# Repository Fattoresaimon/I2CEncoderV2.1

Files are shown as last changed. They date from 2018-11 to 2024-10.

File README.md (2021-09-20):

# I2C Encoder V2.1
--------------------------------------------------------------------------------
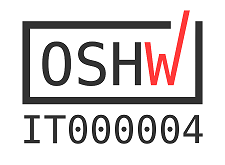
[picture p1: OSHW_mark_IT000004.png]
OSHW


## This repository is for the HW version 2.1!
In the bottom edge it's written the board version. 
If it's written V2.1 you are in the right palce, if it's writte V2.0 you need to go [here](https://github.com/Fattoresaimon/I2CEncoderV2.1/releases/tag/V2.0.0).

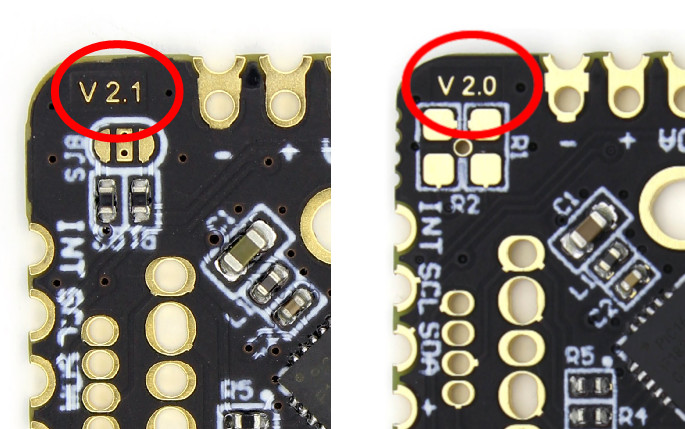
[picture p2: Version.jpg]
HW version V2.1


## Introduction
The I2C Encoder V2.1 is a small board where you can use a classical mechanical encoder, or an illuminated RGB encoder on I2C bus.
The device has also 3 configurable GPIOs with the same footprint of RGB LED. It's possible to connect up to 127 boards in cascade and read all of them with the same I2C bus.
The I2C Encoder V2.1 has a series of 8 bit registers where it is possible to configure  the parameters and four 32 bit of registers. These 32 bit registers store counter value, value of increment steps, maximum and minimum thresholds.
Every time when encoder rotates at least one step, the counter value increases or decreases according to the rotation direction by the value of the increment steps register.
When the counter value is outside of the limit set by the thresholds registers, the counter value can be wrapped or can stuck on the threshold value reached.
I2C Encoder V2.1 also has an open-drain interrupt pin. It is set to logic low every time an interrupt occurs, the source of interrupt can be customized.

## Where you can get this board?
This project is available on our [DuPPa store](https://www.duppa.net/duppa-shop/) and also in our [Tindie store!](https://www.tindie.com/products/Saimon/i2c-encoder-v2/)

## Repository Structure
* [Arduino Library:](https://github.com/Fattoresaimon/ArduinoDuPPaLib) Repository where you can find the Arduino IDE library for the DuPPa boards
* [Raspberry Library:](/Python%20Raspberry%20Library) Ready to use library in Python for the Raspberry board with example.
* [Firmware:](/Firmware) Project folder of Microchip MPLAB X contain the code running inside of the PIC16F18345
* [Hardware:](/Hardware) Folder containing the gerber file, schematic and BOM. 
* [Datasheet EncoderI2C V2.1:](EncoderI2CV2.1_v1.2.pdf) Datasheet of the board with the description of the registers and some useful information.

**The HW project is also available on [CircuitMaker](https://workspace.circuitmaker.com/Projects/Details/Simone--Caron/I2C-Encoder-V2)**

## Third-party libraries
* [CircuitPython](https://github.com/bwshockley/CircuitPython-i2cEncoderLibV21) thanks to Benjamin Shockley
* [C# / nanoFramework]( https://github.com/andylyonette/I2cEncoderV2)  thanks to  [Andy Lyonette](https://www.hackster.io/andy-lyonette)
* [PSOC](https://github.com/rudydevolder/DUPPA-i2cEncoder-for-PSOC) thanks to Rudy De Volder

## Third-party tutorial
[Tutorial #226 – Pyboard – Illuminated encoder](https://tutorial.hyperpanel.com/tutorials/tutorial-226-pyboard-illuminated-encoder/) thanks to Carolino Santonastasi

## Licensing

Hardware and firmware are licensed under GPL-3 license.

Documentation is licensed under a Creative Commons BY-SA 4.0 international license.

**If you want to donate for my work, i would really appreciate it. You can donate here with this link. Thank you!**



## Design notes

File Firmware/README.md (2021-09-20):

# I2C Encoder V2.1 Source code

Here you can find the last firmware version of the project.
You can find the MPLAB project with the source file, and you can find directly the binary file ready to be uploaded to the microcontroller.

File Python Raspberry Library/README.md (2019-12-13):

# I2C Encoder V2.1 Python library 
--------------------------------------------------------------------------------

## Introduction

Here you can find the library and some examples for Raspberry Pi.
For more details of the functionality of the board please read the [Datasheet](../EncoderI2CV2.1_v1.0.pdf) 

## Installation

The installation is very simple:

* Download the file [**i2cEncoderLibV2.py** ](Source/i2cEncoderLibV2.py) 
* Put the file in the folder where you have the source files.
* Import the library in your source files
``` python
import i2cEncoderLibV2
```

## Initialization

The library makes available the class **i2cEncoderLibV2**
For initialize the library you have to declare an instance of the class **i2cEncoderLibV2** for each encoders.
In the instance you have to declare the I2C address of the board
For example:

``` python
import smbus2
import i2cEncoderLibV2

bus = smbus2.SMBus(1)
encoder = i2cEncoderLibV2.i2cEncoderLibV2(bus, 0x61)
```
In this example the I2C address is 0x61: jumpers A0, A5 and A6 are soldered

## Callback Configuration

This library support the callback functionality.
There is the possibility to link a function to a specific interrupt of the I2C Encoder V2, in this way the function is automatically called when the I2C Encoder V2 generates an interrupts.

A callback function must be declared as the following:

```python
def NAME_OF_THE_FUNCTION():
```
There are 16 possible events:

| Event | Description |
|:---:|:---|
| onButtonRelease | Encoder push button is released |
| onButtonPush | Encoder push button is pushed |
| onButtonDoublePush | Encoder push button is double pushed |
| onIncrement | The counter value is incremented |
| onDecrement | The counter value is decremented |
| onChange | The counter value is incremented or decremented |
| onMax | The counter value reach the maximum threshold |
| onMin | The counter value reach the minimum threshold |
| onMinMax | The counter value reach the maximum or minimum threshold |
| onGP1Rise | GP1 configured as input, rising edge |
| onGP1Fall | GP1 configured as input, falling edge |
| onGP2Rise | GP2 configured as input, rising edge  |
| onGP2Fall | GP2 configured as input, falling edge  |
| onGP3Rise | GP3 configured as input, rising edge  |
| onGP3Fall | GP3 configured as input, falling edge  |
| onFadeProcess | Fade process terminated |

#### Examples:

```python
encoder = i2cEncoderLibV2.i2cEncoderLibV2(bus, 0x61)

...

 # Simple callback that ist's called when the encoder is rotated and blink the green led #
def EncoderChange():
    encoder.writeLEDG(100)
    print ('Changed: %d' % (encoder.readCounter32()))
    encoder.writeLEDG(0)

...

encoder.onChange = EncoderChange # Attach the event to the callback function#

}

```

If you need to remove the link with a callback, you just need to define:
```python
encoder.onChange = None
```

## Methods

### Initialization
#### begin(conf)
This is used for initialize the encoder by writing the configuration register.
The parameters can be concatenate in OR mode.
Possible parameters are the following:

| Parameter | Description |
| --- | --- |
| INT_DATA | The Threshold, counter step and counter value are used with integer numbers |
| FLOAT_DATA | The Threshold, counter step and counter value are used with floating numbers |
| | |
| WRAP_ENABLE | Wrap enable. When the counter value reaches the CMAX+1, restart to the CMIN and vice versa |
| WRAP_DISABLE | Wrap disable. When the counter value reaches the CMAX or CMIN, the counter stops to increasing or decreasing |
| | |
| DIRE_LEFT | Rotate left side to increase the value counter |
| DIRE_RIGHT | Rotate right side to increase the value counter |
| | |
| IPUP_DISABLE | Disable the internal pull-up on the INT pin |
| IPUP_ENABLE | Enable the internal pull-up on the INT pin |
| | |
| RMOD_X2 | Encoder in X2 mode |
| RMOD_X1 | Encoder in X1 mode |
| | |
| RGB_ENCODER | RGB illuminated encoder is soldered |
| STD_ENCODER | Standard rotary encoder is soldered |
| | |
| EEPROM_BANK1 | Select the first EEPROM bank |
| EEPROM_BANK2 | Select the second EEPROM bank |
| | |
| RESET | Reset the board |
| | |
| CLK_STRECH_ENABLE | Enable the I2C clock stretch (only v2.1) |
| CLK_STRECH_DISABLE | Disable the I2C clock stretch (only v2.1) |
| | |
| REL_MODE_ENABLE | Enable the CVAL relative mode (only v2.1)|
| REL_MODE_DISABLE | Disable the CVAL relative mode (only v2.1) |
| | |

###### Examples:

```python
encoder.begin(i2cEncoderLibV2.INT_DATA | i2cEncoderLibV2.WRAP_ENABLE | i2cEncoderLibV2.DIRE_RIGHT | i2cEncoderLibV2.IPUP_ENABLE | i2cEncoderLibV2.RMOD_X1 | i2cEncoderLibV2.RGB_ENCODER)
```

###  reset()
Reset of the board. 
In this command there is 8ms delay in order to make the board correctly restart.

### Configuration

#### GPx pins configuration

This 3 function are used for configure the GP pins. The parameter are the same for all of the 3 GP pins.
The interrupt configuration are used only when the pin is configured as digital input.

##### writeGP1conf(gp1)
##### writeGP2conf(gp2)
##### writeGP3conf(gp3)

| Parameter | Description |
|:---:|:---:|
|GP_PWM| Set the GP pin as PWM output|
|GP_OUT| Set the GP pin as digital output|
|GP_AN| Set the GP pin as analog input|
|GP_IN| Set the GP pin as digital input output|
|||
|GP_PULL_EN| Enable the internal pull-up of the pin|
|GP_PULL_DI| Disable the internal pull-up of the pin|
|||
|GP_INT_DI| Disable the pin interrupt|
|GP_INT_PE| Enable the interrupt at the positive edge|
|GP_INT_NE|  Enable the interrupt at the negative edge|
|GP_INT_BE|  Enable the interrupt at the positive and negative edge|

###### Examples:

```python
encoder.writeGP1conf(i2cEncoderLibV2.GP_AN | i2cEncoderLibV2.GP_PULL_DI | i2cEncoderLibV2.GP_INT_DI)  # Configure the GP1 as analog input with the pull-up and the interrupt disable #
```

##### writeInterruptConfig(interrupt)

This method is used for enable or disable the interrupt source selectively. When an interrupt event occurs, the INT pin goes low and the event is stored in the status register.

| Parameter | Description |
|:---:|:---:|
| PUSHR | Push button of the encoder is released |
| PUSHP | Push button of the encoder is pressed |
| PUSHD | Push button of the encoder is doule pushed  |
| RINC  | Encoder is rotated in the increment direction  |
| RDEC  | Encoder is rotated in the decrement direction  |
| RMAX  | Maximum threshold is reached  |
| RMIN  | Minimum threshold is reached  |
| INT_2  | An event on the interrupt 2 register occurs |

###  void autoconfigInterrupt(void)

This method auto configures the **INTCONF** register according to the attached callback.
**For the proper use, must be called after the definition of the last event property.**

```python
encoder.onChange = EncoderChange
encoder.onButtonPush = EncoderPush
encoder.onButtonDoublePush = EncoderDoublePush
encoder.onMax = EncoderMax
encoder.onMin = EncoderMin
  # Enable the I2C Encoder V2 interrupts according to the previous attached callback #
encoder.autoconfigInterrupt()

```

##### writeAntibouncingPeriod(bounce)

This method is used for writing the Anti-bouncing period **ANTBOUNC**.
This set the period where an opposite rotation  is ignored
The I2C encoder V2 will multiplies this value by 10 (value x10).
###### Examples:

```python
encoder.writeAntibouncingPeriod(20)  # Set an anti-bouncing of 200ms # 
```

##### writeDoublePushPeriod(dperiod)

This method is used for setting the window period  **DPPERIOD** of the double push of the rotary encoder switch. It the value is 0 the double push option is disabled.
The I2C encoder V2 will multiply this value x10.
###### Examples:

```python
encoder.writeDoublePushPeriod(50)  # Set a period for the double push of 500ms #
```

##### writeFadeRGB(fade)

This method is used for setting the fade speed **FADERGB** of the RGB LED of the rotary encoder. It the value is 0 the fade option is disabled.
###### Examples:

```python
encoder.writeFadeRGB(1)  #Fade enabled with 1ms step 
```

##### writeFadeGP(fade)

This method is used for setting the fade speed **FADEGP** of the GP pins. It the value is 0 the fade option is disabled.
###### Examples:

```python
  encoder.writeFadeGP(5)  # GP Fade enabled with 5ms step #
```

### writeGammaRLED(gamma)
### writeGammaGLED(gamma)
### writeGammaBLED(gamma)
### writeGammaGP1(gamma)
### writeGammaGP2(gamma)
### writeGammaGP3(gamma)

This method is used to set a gamma correction for the RGB led of the encoder and for the GP pins.

| Parameter | Description |
|:---:|:---|
| GAMMA_OFF | Gamma correction is OFF |
| GAMMA_1 | Gamma is 1, in this case the PWM is linear |
| GAMMA_1_8 | Gamma is 1.8 |
| GAMMA_2 | Gamma is 2 |
| GAMMA_2_2 | Gamma is 2.2 |
| GAMMA_2_4 | Gamma is 2.4 |
| GAMMA_2_6 | Gamma is 2.6 |
| GAMMA_2_8 | Gamma is 2.8 |

#### Examples:

```python
  encoder.writeGammaRLED(i2cEncoderLibV2.GAMMA_2)
  encoder.writeGammaGLED(i2cEncoderLibV2.GAMMA_2)
  encoder.writeGammaBLED(i2cEncoderLibV2.GAMMA_2)
```

### Status

##### updateStatus()
Read from the encoder status register (reg:0x05) and save the value internally.
Return value is **true** in case of some event, otherwise is **false**
In case an event of the I2STATUS  register, the I2STATUS is automatically readed.

###### Examples:

```python
  if Encoder.updateStatus() == True :
  # Something happens
  
```

##### readStatus(status)

Must be called after **updateStatus()**, this method is used for check if some event occurred one the **ESTATUS** register.
Return value is **true** in case of the event occurred, otherwise is **false**
Possible parameter are:

| Parameter | Description |
|:---:|:---:|
| PUSHR | Push button of the encoder is released |
| PUSHP | Push button of the encoder is pressed |
| PUSHD | Push button of the encoder is double pushed  |
| RINC  | Encoder is rotated in the increment direction  |
| RDEC  | Encoder is rotated in the decrement direction  |
| RMAX  | Maximum threshold is reached  |
| RMIN  | Minimum threshold is reached  |
| INT_2  | An event on the interrupt 2 register occurs |

###### Example:
```python
 if  encoder.updateStatus() == True :
      if  encoder.readStatus(RINC) == True :
      	print ('Increment: %d' % (encoder.readCounter32())) 
      
      if  encoder.readStatus(RDEC) == True :
      	print ('Decrement: %d' % (encoder.readCounter32())) 

      if  encoder.readStatus(RMAX) == True :
      	print ('Max!') 

      if  encoder.readStatus(RMIN) == True :
      	print ('Min!')  

      if  encoder.readStatus(PUSHP) == True :
      	print ('Encoder pushed!')  
        
	  if  encoder.readStatus(PUSHR) == True :
      	print ('Encoder released!')   

      if  encoder.readStatus(PUSHD) == True :
      	print ('Encoder double pushed!')
```

##### readStatus()

Return the status of the register **ESTATUS**

##### readInt2(status)
Must be called after **updateStatus()**, this method is used for check if some event occurred one the secondary interrupt status **I2STATUS** register.
Return value is **true** in case of the event occurred, otherwise is **false**
Possible parameter are:

| Parameter | Description |
|:---:|:---:|
| GP1_POS  | Positive edge on the GP1 pin |
| GP1_NEG  | Negative edge on the GP1 pin |
| GP2_POS  | Positive edge on the GP2 pin |
| GP2_NEG  |Negative edge on the GP2 pin |
| GP3_POS  | Positive edge on the GP3 pin|
| GP3_NEG  |Negative edge on the GP3 pin |
| FADE_INT |Fade process finished |

###### Example:
```python
 if  Encoder.updateStatus() == True :
      if  Encoder.readInt2(GP1_POS)
        print("GP1 positive edge")
      
      if Encoder.readInt2(GP1_NEG) == True :
        print ('GP1 negative edge ')

      if Encoder.readInt2(GP2_POS)  == True :
          print('GP2 positive edge')

      if  Encoder.readInt2(GP2_NEG) == True :
        print('GP2 negative edge ')

      if  Encoder.readInt2(GP3_POS) == True :
        print('GP3 positive edge')

      if  Encoder.readInt2(GP3_NEG) == True :
        print('GP3 negative edge ')

      if  Encoder.readInt2(FADE_INT) == True :
        println('Fade process finished') 
      
```

##### readInt2Raw()

Return the status of the register **I2STATUS**

##### readFadeStatus(status)

When this function is called, it performs a I2C reading.
This function return **true** when the fade running, otherwise return **false**

| Parameter | Description |
|:---:|:---:|
| FADE_R  | Fade process status of the RGB encoder Red color |
| FADE_G  | Fade process status of the RGB encoder Green color |
| FADE_B  | Fade process status of the RGB encoder Blue color |
| FADE_GP1  | Fade process status of the GP1 |
| FADE_GP2  | Fade process status of the GP2 |
| FADE_GP3  | Fade process status of the GP3 |

##### readFadeStatusRaw()

Return the value of the register **FSTATUS**.

### Reading methods
In this section are listed all the reading method available

##### readCounter32()
Return the counter value in the format **32bit int**, by reading all the 4 bytes of the counter value registers.

##### readCounter16()
Return the counter value in the format **16bit int**, by reading the 2 LSB  of the counter value registers.
Useful when the counter register is between the values -32768 to 32767.

##### readCounter8()
Return the counter value in the format **8bit int**, by reading the LSB byte of the counter value register.
Useful when the counter register is between the values -128 to 127

##### readCounterFloat()
Return the counter value in the format **float**, by reading all the 4 bytes of the counter value registers.
For using this function you have to configure the board with the parameter **FLOAT_DATA**.

##### readMax()
Return the maximum threshold in format **32bit int**, bye reading all the 4 bytes of the counter Max.

##### readMaxFloat()
Return the maximum threshold in format **float**, bye reading all the 4 bytes of the counter Max.

##### readMin()
Return the minimum threshold in format **32bit int**, by reading all the 4 byte of the counter Min.

##### readMinFloat()
Return the minimum  threshold in format **float**, bye reading all the 4 bytes of the counter Min.

##### readStep()
Return the minimum threshold in format **32bit int**, by reading all the 4 bytes of the ISTEP registers.

##### readStepFloat()
Return the step value in format **float**, by reading all the 4 bytes of the ISTEP registers .

##### readLEDR()
Return the value of the RLED register. 

##### readLEDG()
Return the value of the GLED register. 

##### readLEDB()
Return the value of the BLED register. 

##### readGP1()
Return the value of the GP1REG register. 
If the **GP1** is configured as input, it's possible to read the logic status of the pin: *1* when the pin is high, otherwise *0*.
If the **GP1** is configured as analog, it's possible to read the 8bit of the ADC.

##### readGP2()
Return the value of the GP2REG register. 
If the **GP2** is configured as input, it's possible to read the logic status of the pin: *1* when the pin is high, otherwise *0*.
If the **GP2** is configured as analog, it's possible to read the 8bit of the ADC.

##### readGP3()
Return the value of the GP3REG register. 
If the **GP3** is configured as input, it's possible to read the logic status of the pin: *1* when the pin is high, otherwise *0*.
If the **GP3** is configured as analog, it's possible to read the 8bit of the ADC. 

##### readAntibouncingPeriod()
Return the value of the ANTBOUNC register. 

##### readDoublePushPeriod()
Return the value of the DPPERIOD register. 

##### readFadeRGB()
Return the value of the FADERGB register. 

##### readFadeGP()
Return the value of the FADEGP register. 

##### readIDCode()
Return the ID code of the I2C Encoder V2.1, that is 0x53
Available only on the V2.1

##### readVersion()
Return the version of the board. 
Available only on the V2.1

##### readEEPROM(add)
Return the value of the EEPROM register. 
This function automatically manage the setting of the first and second memory bank.

### Writing methods
#####  writeCounter(value)
Write the counter value register with a  **32bit int** number. All of the 4 bytes are wrote.

#####  writeCounterFloat(value)
Write the counter value register with a  **float** number. All of the 4 bytes are wrote.

#####  writeMax(max)
Write the Max register with a  **32bit int** number. All of the 4 bytes are wrote.

#####  writeMax(max)
Write the Max register with a  **float** number. All of the 4 bytes are wrote.

#####  writeMin(min)
Write the Min register with a **32bit int** number. All of the 4 bytes are wrote.

#####  writeMinFloat(min)
Write the Min register with a **float** number. All of the 4 bytes are wrote.

#####  writeStep(step)
Write the increment step  with a  **32bit int** number. All of the 4 bytes are wrote.

#####  writeStepFloat(step)
Write the increment step with a  **float** number. All of the 4 bytes are wrote.

##### writeLEDR(rled)
Write the PWM value of the RLED of the RGB encoder. When 0 means PWM at 0%, LED off while 0xFF means PWM at 100% and LED ON.

##### writeLEDG(gled)
Write the PWM value of the GLED of the RGB encoder. When 0 means PWM at 0%, LED off while 0xFF means PWM at 100% and LED ON.

##### writeLEDB(bled)
Write the PWM value of the BLED of the RGB encoder. When 0 means PWM at 0%, LED off while 0xFF means PWM at 100% and LED ON.

##### writeRGBCode(rgb)
Write a 24bit RGB color in the format 0xRRGGBB.

##### writeGP1(gp1)
Write the GP1REG register.
If the GP1 is configure as PWM with this method it's possible to write the PWM value.
If the GP1 is configure as output with this method it's possible to write the logic status: 1 for high, while 0 for low.

##### writeGP2(gp2)
Write the GP2REG register.
If the GP2 is configure as PWM with this method it's possible to write the PWM value.
If the GP2 is configure as output with this method it's possible to write the logic status: 1 for high, while 0 for low.

##### writeGP3(gp3)
Write the GP2REG register.
If the GP2 is configure as PWM with this method it's possible to write the PWM value.
If the GP2 is configure as output with this method it's possible to write the logic status: 1 for high, while 0 for low.

##### writeAntibouncingPeriod(bounc)
Write the ANTBOUNC register.

##### writeDoublePushPeriod(dperiod)
Write the DPPERIOD register.

##### writeFadeRGB(fade)
Write the FADERGB register.

##### writeFadeGP(fade)
Write the FADEGP register.

##### writeGammaRLED(gamma)
Configure the gamma correction for the red led of the RGB encoder

##### writeGammaGLED(gamma)
Configure the gamma correction for the green led of the RGB encoder

##### writeGammaBLED(gamma)
Configure the gamma correction for the blue led of the RGB encoder

##### writeGammaGP1(gamma)
Configure the gamma correction for the GP1 pin

##### writeGammaGP2(gamma)
Configure the gamma correction for the GP2 pin

##### writeGammaGP3(gamma)
Configure the gamma correction for the GP3 pin

##### writeEEPROM(add, data)
Write the EEPROM memory.
The input parameter *add* is the address. This method automatically change the first or the second bank.
The input parameter *data* is the data that will be written.

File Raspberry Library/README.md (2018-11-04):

# I2C Encoder V2 Python library 
--------------------------------------------------------------------------------

## Introduction

Here you can find the library and some examples for Raspberry Pi.
For more details of the functionality of the board please read the [Datasheet](https://github.com/Fattoresaimon/I2CEncoderV2/blob/master/EncoderI2CV2_v1.3.pdf) 

## Installation

There are two versions of the library. The library under the folder [smbus](https://github.com/Fattoresaimon/I2CEncoderV2/tree/master/Raspberry%20Library/smbus)  uses the library smbus, while the library under the folder  [smbus2](https://github.com/Fattoresaimon/I2CEncoderV2/tree/master/Raspberry%20Library/smbus2) uses the library  [smbus2](https://github.com/kplindegaard/smbus2).
The smbus2 is better optimized for the I2C transaction respect to the smbus. 

The installation is very simple:

* Download the file **i2cEncoderLibV2.py**
* Put the file in the folder where you have the source files.
* Import the library in your source files
``` python
import i2cEncoderLibV2
```

## Initialization

The library makes available the class **i2cEncoderLibV2**
For initialize the library you have to declare an instance of the class **i2cEncoderLibV2** for each encoders.
For example:

``` python
import smbus
import i2cEncoderLibV2

bus=smbus.SMBus(1)
encoder = i2cEncoderLibV2.i2cEncoderLibV2(bus,0x61)
```
Or if you want to use the smbus2

```python
import smbus2
import i2cEncoderLibV2

bus=smbus2.SMBus(1)
encoder = i2cEncoderLibV2.i2cEncoderLibV2(bus,0x61)
```

## Methods

### Initialization
#### begin(conf)
This is used for initialize the encoder by writing the configuration register of the encoder.
The parameters can be concatenate in OR mode.
Possible parameters are the following:

|Parameter | Description |
| --- | --- |
| INT_DATA | The Threshold, counter step and counter value are used with integer numbers |
| FLOAT_DATA | The Threshold, counter step and counter value are used with floating numbers |
| | |
| WRAP_ENABLE | Wrap enable. When the counter value reaches the CMAX+1, restart to the CMIN and vice versa |
| WRAP_DISABLE | Wrap disable. When the counter value reaches the CMAX or CMIN, the counter stops to increasing or decreasing |
| | |
| DIRE_LEFT | Rotate left side to increase the value counter |
| DIRE_RIGHT | Rotate right side to increase the value counter |
| | |
| IPUP_DISABLE | Disable the internall pull-up on the INT pin |
| IPUP_ENABLE | Enable the internall pull-up on the INT pin |
| | |
| RMOD_X2 | Encoder in X2 mode |
| RMOD_X1 | Encoder in X1 mode |
| | |
| RGB_ENCODER | RGB illuminated encoder is soldered |
| STD_ENCODER | Standard rotary encoder is soldered |
| | |
| EEPROM_BANK1 | Select the first EEPROM bank |
| EEPROM_BANK2 | Select the second EEPROM bank |
| | |
| RESET | Reset the board |

###### Examples:

```python
encoder.begin(i2cEncoderLibV2.INT_DATA | i2cEncoderLibV2.WRAP_ENABLE | i2cEncoderLibV2.DIRE_RIGHT | i2cEncoderLibV2.IPUP_ENABLE | i2cEncoderLibV2.RMOD_X1 | i2cEncoderLibV2.RGB_ENCODER)
```

### Configuration

#### GPx pins configuration

This 3 function are used for configure the GP pins. The parameter are the same for all of the 3 GP pins.
The interrupt configuration are used only when the pin is configured as digital input.

##### writeGP1conf(gp1)
##### writeGP2conf(gp2)
##### writeGP3conf(gp3)

| Parameter | Description |
|:---:|:---:|
|GP_PWM| Se the GP pin as PWM output|
|GP_OUT| Se the GP pin as digital output|
|GP_AN| Se the GP pin as analog input|
|GP_IN| Se the GP pin as digital input output|
|||
|GP_PULL_EN| Enable the internal pull-up of the pin|
|GP_PULL_DI| Disable the internal pull-up of the pin|
|||
|GP_INT_DI| Disable the pin interrupt|
|GP_INT_PE| Enable the interrupt at the positive edge|
|GP_INT_NE|  Enable the interrupt at the negative edge|
|GP_INT_BE|  Enable the interrupt at the positive and negative edge|

###### Examples:

```python
encoder.writeGP1conf(i2cEncoderLibV2.GP_AN | i2cEncoderLibV2.GP_PULL_DI | i2cEncoderLibV2.GP_INT_DI)  ##Configure the GP1 as analog input with the pull-up and the interrupt disable 
```

##### writeInterruptConfig(interrupt)

This method  is used for enable or disable the interrupt source selectively. When an interrupt event occurs, the INT pin goes low and the event is stored in the status register.

| Parameter | Description |
|:---:|:---:|
| PUSHR | Push button of the encoder is released |
| PUSHP | Push button of the encoder is pressed |
| PUSHD | Push button of the encoder is doule pushed  |
| RINC  | Encoder is rotated in the increment direction  |
| RDEC  | Encoder is rotated in the decrement direction  |
| RMAX  | Maximum threshold is reached  |
| RMIN  | Minimum threshold is reached  |
| INT2  | An event on the interrupt 2 register occurs |

##### writeAntibouncingPeriod(bounc)

This method is used for writing the Anti-bouncing period **ANTBOUNC**.
The I2C encoder V2 will multiplie this value x10.
###### Examples:

```python
encoder.writeAntibouncingPeriod(20)  #Set an anti-bouncing of 200ms 
```

##### writeDoublePushPeriod(dperiod)

This method is used for setting the window period  **DPPERIOD** of the double push of the rotary encoder switch. It the value is 0 the double push option is disabled.
The I2C encoder V2 will multiplie this value x10.
###### Examples:

```python
encoder.writeDoublePushPeriod(50)  #Set a period for the double push of 500ms 
```

##### writeFadeRGB(fade)

This method is used for setting the fade speed **FADERGB** of the RGB LED of the rotary encoder. It the value is 0 the fade option is disabled.
###### Examples:

```python
encoder.writeFadeRGB(1)  #Fade enabled with 1ms step 
```

##### writeFadeGP(fade)

This method is used for setting the fade speed **FADEGP** of the RGB LED of the rotary encoder. It the value is 0 the fade option is disabled.
###### Examples:

```python
  encoder.writeFadeGP(5)  #GP Fade enabled with 5ms step 
```

### Status

##### updateStatus()
Read from the encoder status register (reg:0x05) and save the value internally.
Return value is **true** in case of some event, otherwise is **false**
In case an event of the I2STATUS  register, the I2STATUS is automatically readed.

###### Examples:

```python
  if Encoder.updateStatus() == True :
  # Somthing happens
  
```

##### readStatus(status)

Must be called after **updateStatus()**, this method is used for check if some event occurred one the **ESTATUS** register.
Return value is **true** in case of the event occured, otherwise is **false**
Possible parameter are:

| Parameter | Description |
|:---:|:---:|
| PUSHR | Push button of the encoder is released |
| PUSHP | Push button of the encoder is pressed |
| PUSHD | Push button of the encoder is doule pushed  |
| RINC  | Encoder is rotated in the increment direction  |
| RDEC  | Encoder is rotated in the decrement direction  |
| RMAX  | Maximum threshold is reached  |
| RMIN  | Minimum threshold is reached  |
| INT2  | An event on the interrupt 2 register occurs |

###### Example:
```python
 if  encoder.updateStatus() == True :
      if  encoder.readStatus(RINC) == True :
      	print ('Increment: %d' % (encoder.readCounter32())) 
      
      if  encoder.readStatus(RDEC) == True :
      	print ('Decrement: %d' % (encoder.readCounter32())) 

      if  encoder.readStatus(RMAX) == True :
      	print ('Max!') 

      if  encoder.readStatus(RMIN) == True :
      	print ('Min!')  

      if  encoder.readStatus(PUSHP) == True :
      	print ('Encoder pushed!')  
        
	  if  encoder.readStatus(PUSHR) == True :
      	print ('Encoder released!')   

      if  encoder.readStatus(PUSHD) == True :
      	print ('Encoder double pushed!')
```

##### readStatus()

Return the status of the register **ESTATUS**

##### readInt2(status)
Must be called after **updateStatus()**, this method is ued for check if some event occured one the secondary interrupt status **I2STATUS** register.
Return value is **true** in case of the event occured, otherwise is **false**
Possible parameter are:

| Parameter | Description |
|:---:|:---:|
| GP1_POS  | Positive edge on the GP1 pin |
| GP1_NEG  | Negative edge on the GP1 pin |
| GP2_POS  | Positive edge on the GP2 pin |
| GP2_NEG  |Negative edge on the GP2 pin |
| GP3_POS  | Positive edge on the GP3 pin|
| GP3_NEG  |Negative edge on the GP3 pin |
| FADE_INT |Fade process finished |

###### Example:
```python
 if  Encoder.updateStatus() == True :
      if  Encoder.readInt2(GP1_POS)
        print("GP1 positive edge")
      
      if Encoder.readInt2(GP1_NEG) == True :
        print ('GP1 negative edge ')

      if Encoder.readInt2(GP2_POS)  == True :
          print('GP2 positive edge')

      if  Encoder.readInt2(GP2_NEG) == True :
        print('GP2 negative edge ')

      if  Encoder.readInt2(GP3_POS) == True :
        print('GP3 positive edge')

      if  Encoder.readInt2(GP3_NEG) == True :
        print('GP3 negative edge ')

      if  Encoder.readInt2(FADE_INT) == True :
        println('Fade process finished') 
      
```

##### readInt2Raw()

Return the status of the register **I2STATUS**

##### readFadeStatus(status)

When this function is called, it performs a I2C reading.
This function return **true** when the fade running, otherwise return **false**

| Parameter | Description |
|:---:|:---:|
| FADE_R  | Fade process status of the RGB encoder Red color |
| FADE_G  | Fade process status of the RGB encoder Green color |
| FADE_B  | Fade process status of the RGB encoder Blue color |
| FADE_GP1  | Fade process status of the GP1 |
| FADE_GP2  | Fade process status of the GP2 |
| FADE_GP3  | Fade process status of the GP3 |

##### readFadeStatusRaw()

Return the value of the register **FSTATUS**.

### Reading methods

##### readCounter32()
Return the counter value in the format **32bit int**, by reading all the 4 bytes of the counter value registers.

##### readCounter16()
Return the counter value in the format **16bit int**, by reading the 2 LSB  of the counter value registers.
Useful when the counter register is between the values -32768 to 32767.

##### readCounter8()
Return the counter value in the format **8bit int**, by reading the LSB byte of the counter value register.
Useful when the counter register is between the values -128 to 127

##### readCounterFloat()
Return the counter value in the format **float**, by reading all the 4 bytes of the counter value registers.
For using this function you have to configure the board with the parameter **FLOAT_DATA**.

##### readMax()
Return the maximum threshold in format **32bit int**, bye reading all the 4 bytes of the counter Max.

##### readMaxFloat()
Return the maximum threshold in format **float**, bye reading all the 4 bytes of the counter Max.

##### readMin()
Return the minimum threshold in format **32bit int**, by reading all the 4 byte of the counter Min.

##### readMinFloat()
Return the minimum  threshold in format **float**, bye reading all the 4 bytes of the counter Min.

##### readStep()
Return the minimum threshold in format **32bit int**, by reading all the 4 bytes of the ISTEP registers.

##### readStepFloat()
Return the step value in format **float**, by reading all the 4 bytes of the ISTEP registers .

##### readLEDR()
Return the value of the RLED register. 

##### readLEDG()
Return the value of the GLED register. 

##### readLEDB()
Return the value of the BLED register. 

##### readGP1()
Return the value of the GP1REG register. 
If the **GP1** is configured as input, it's possible to read the logic status of the pin: *1* when the pin is high, otherwise *0*.
If the **GP1** is configured as analog, it's possible to read the 8bit of the ADC.

##### readGP2()
Return the value of the GP2REG register. 
If the **GP2** is configured as input, it's possbile to read the logic status of the pin: *1* when the pin is high, otherwise *0*.
If the **GP2** is configured as analog, it's possible to read the 8bit of the ADC.

##### readGP3()
Return the value of the GP3REG register. 
If the **GP3** is configured as input, it's possbile to read the logic status of the pin: *1* when the pin is high, otherwise *0*.
If the **GP3** is configured as analog, it's possible to read the 8bit of the ADC. 

##### readAntibouncingPeriod()
Return the value of the ANTBOUNC register. 

##### readDoublePushPeriod()
Return the value of the DPPERIOD register. 

##### readFadeRGB()
Return the value of the FADERGB register. 

##### readFadeGP()
Return the value of the FADEGP register. 

##### readEEPROM(add)
Return the value of the EEPROM register. 
This function automatically manage the setting of the first and second memory bank.

### Writing methods
#####  writeCounter(value)
Write the counter value register with a  **32bit int** number. All of the 4 bytes are wrote.

#####  writeCounterFloat(value)
Write the counter value register with a  **float** number. All of the 4 bytes are wrote.

#####  writeMax(max)
Write the Max register with a  **32bit int** number. All of the 4 bytes are wrote.

#####  writeMax(max)
Write the Max register with a  **float** number. All of the 4 bytes are wrote.

#####  writeMin(min)
Write the Min register with a **32bit int** number. All of the 4 bytes are wrote.

#####  writeMinFloat(min)
Write the Min register with a **float** number. All of the 4 bytes are wrote.

#####  writeStep(step)
Write the increment step  with a  **32bit int** number. All of the 4 bytes are wrote.

#####  writeStepFloat(step)
Write the increment step with a  **float** number. All of the 4 bytes are wrote.

##### writeLEDR(rled)
Write the PWM value of the RLED of the RGB encoder. When 0 means PWM at 0%, LED off while 0xFF means PWM at 100% and LED ON.

##### writeLEDG(gled)
Write the PWM value of the GLED of the RGB encoder. When 0 means PWM at 0%, LED off while 0xFF means PWM at 100% and LED ON.

##### writeLEDB(bled)
Write the PWM value of the BLED of the RGB encoder. When 0 means PWM at 0%, LED off while 0xFF means PWM at 100% and LED ON.

##### writeRGBCode(rgb)
Write a 24bit RGB color in the format 0xRRGGBB.

##### writeGP1(gp1)
Write the GP1REG register.
If the GP1 is configure as PWM with this method it's possible to write the PWM value.
If the GP1 is configure as output with this method it's possible to write the logic status: 1 for high, while 0 for low.

##### writeGP2(gp2)
Write the GP2REG register.
If the GP2 is configure as PWM with this method it's possible to write the PWM value.
If the GP2 is configure as output with this method it's possible to write the logic status: 1 for high, while 0 for low.

##### writeGP3(gp3)
Write the GP2REG register.
If the GP2 is configure as PWM with this method it's possible to write the PWM value.
If the GP2 is configure as output with this method it's possible to write the logic status: 1 for high, while 0 for low.

##### writeAntibouncingPeriod(bounc)
Write the ANTBOUNC register.

##### writeDoublePushPeriod(dperiod)
Write the DPPERIOD register.

##### writeFadeRGB(fade)
Write the FADERGB register.

##### writeFadeGP(fade)
Write the FADEGP register.

##### writeEEPROM(add, data)
Write the EEPROM memory.
The input parameter *add* is the address. This method automatically change the first or the second bank.
The input parameter *data* is the data taht will be written.

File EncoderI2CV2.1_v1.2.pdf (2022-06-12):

www.duppa.net

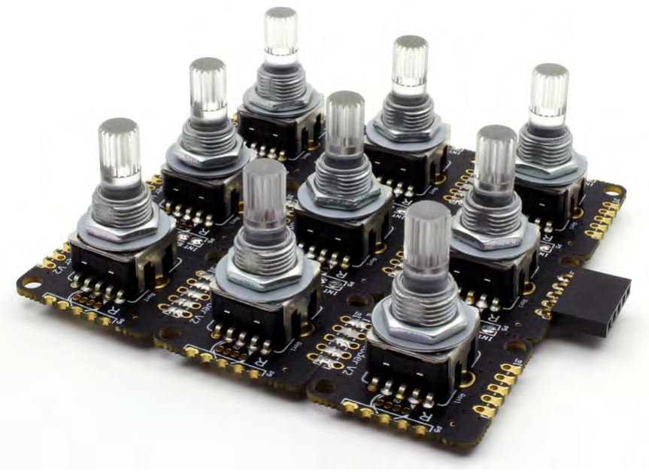
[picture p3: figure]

# I2C Encoder V2.1

## HW V2.1 - FW V2.3

June 12, 2022

Document written in LATEX

www.duppa.net | I2C Encoder V2.1

# Revision History

Revision | Date | Author(s) | Description
1.0 | 09.07.19 | Simone | Update to V2.1

# Contents

1 Device Overview | 4
2 Registers | 15

3 Reference | 32
4 Programming | 33
5 Changelog | 34
6 Issues | 36
7 Schematic | 37

# 1. Device Overview

The I2C Encoder V2.1 is a small board where you can use a classical mechanical encoder, or an illuminated RGB encoder on I²C bus. The device has also 3 configurable GPIOs with the same footprint of RGB LED. It’s possible to connect up to 127 boards in cascade and read all of them with the same I²C bus.
The I2C Encoder V2.1 has a series of 8 bit registers where it is possible to configure the parameters and four 32 bit of registers. These 32 bit registers store counter value, value of increment steps, maximum and minimum thresholds. Every time when encoder rotates at least one step, the counter value increases or decreases according to the rotation direction by the value of the increment steps register .
When the counter value is outside of the limit set by the thresholds registers, the counter value can be wrapped or can stuck on the threshold value reached.
The I2C Encoder V2.1 also has an open-drain interrupt pin. It is set to logic low every time an interrupt occurs, the source of interrupt can be customized.

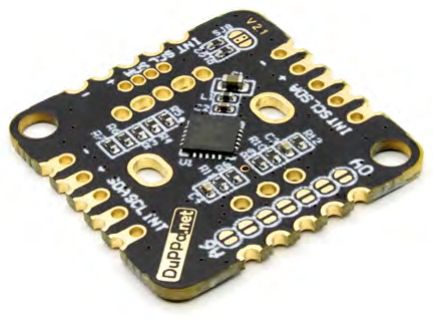
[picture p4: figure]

Figure 1.1: I2C Encoder V2.1 bottom view

## 1.1 Electrical characteristics

Parameter | Symbol | Min | Max
Supply voltage | VDD | 3.3V | 5V
2C input-low level I | VIL | 0 | 0.3 * VDD
I 2C input-high level | VIH | 0.8 * VDD | VDD
I 2C clock input frequency | fSCL | | 400kHz
Encoder frequency | fENC | | 500hz
Current at 5V | IDD5V | 1.9mA (RGB LED off) | 57mA (RGB LED on)
Current at 3.3V | IDD3V3 | 1.7mA (RGB LED off) | 25mA (RGB LED on)
Interrupt pull-up resistor | RINT | 15kΩ | 120kΩ

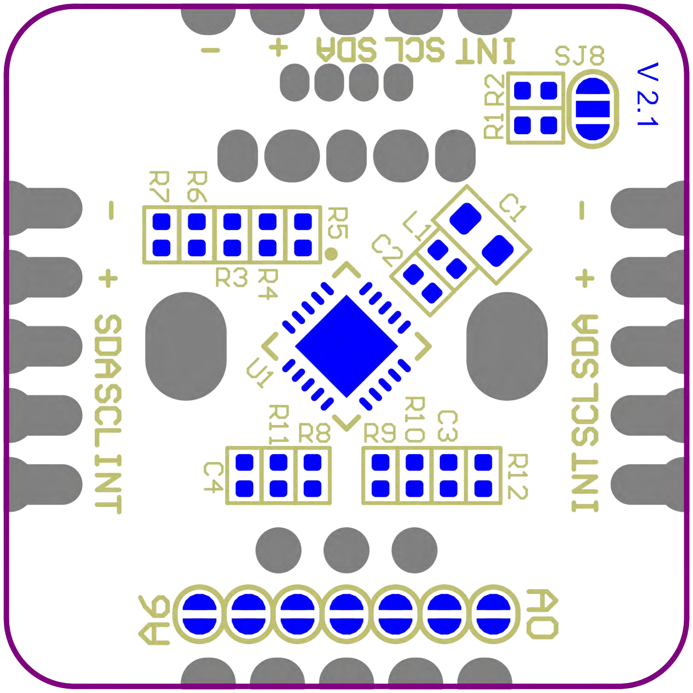
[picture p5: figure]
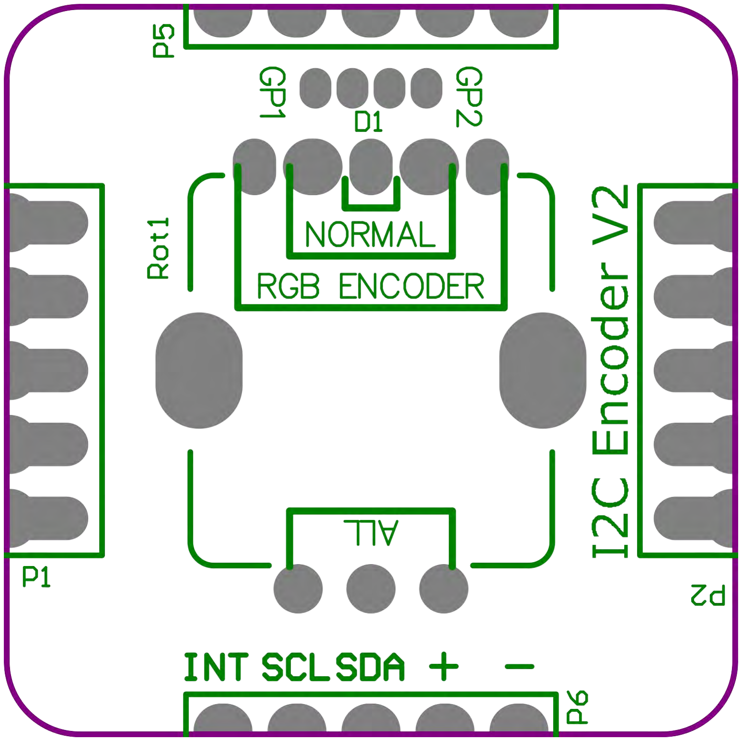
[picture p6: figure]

Figure 1.2: Top view of the board | Figure 1.3: Bottom view of the board

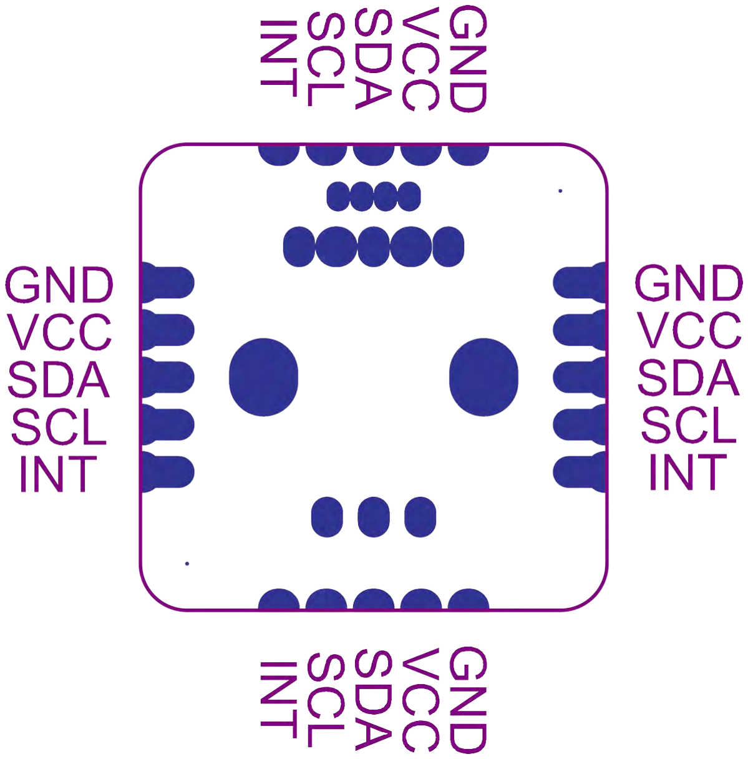
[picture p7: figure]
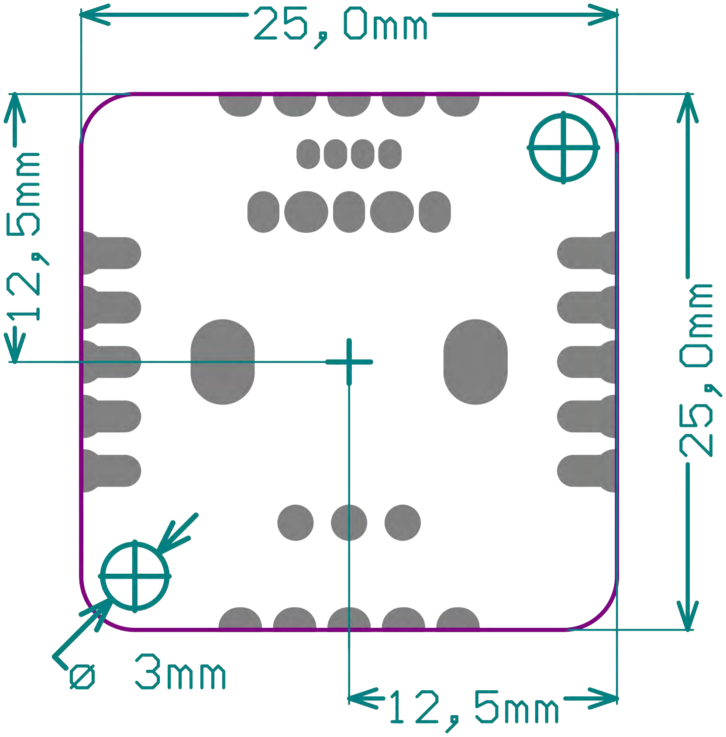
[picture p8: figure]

Figure 1.4: Dimensions of the board | Figure 1.5: Pin-out of the board

## 1.2 Connection

Figure 1.5 shows the pin-out of the I2C Encoder V2.1.

Pin | I/O Type | Function
GND | Power | Ground reference for logic
Vcc | Power | Positive supply for logic
SDA | I/O | 2C data I
SCL | I | 2C clock I
INT | OD | Open-drain interrupt output

There are two 5 pin headers on the right and left sides of the I2C Encoder V2.1. There are also 5 castellated holes on each four side.
The I2C Encoder V2.1 can be connected together in a matrix by soldering the castellated holes. In order to avoid I

2C address conflict, the address of each device must be different. In the section 1.3, it is described how to set the address.

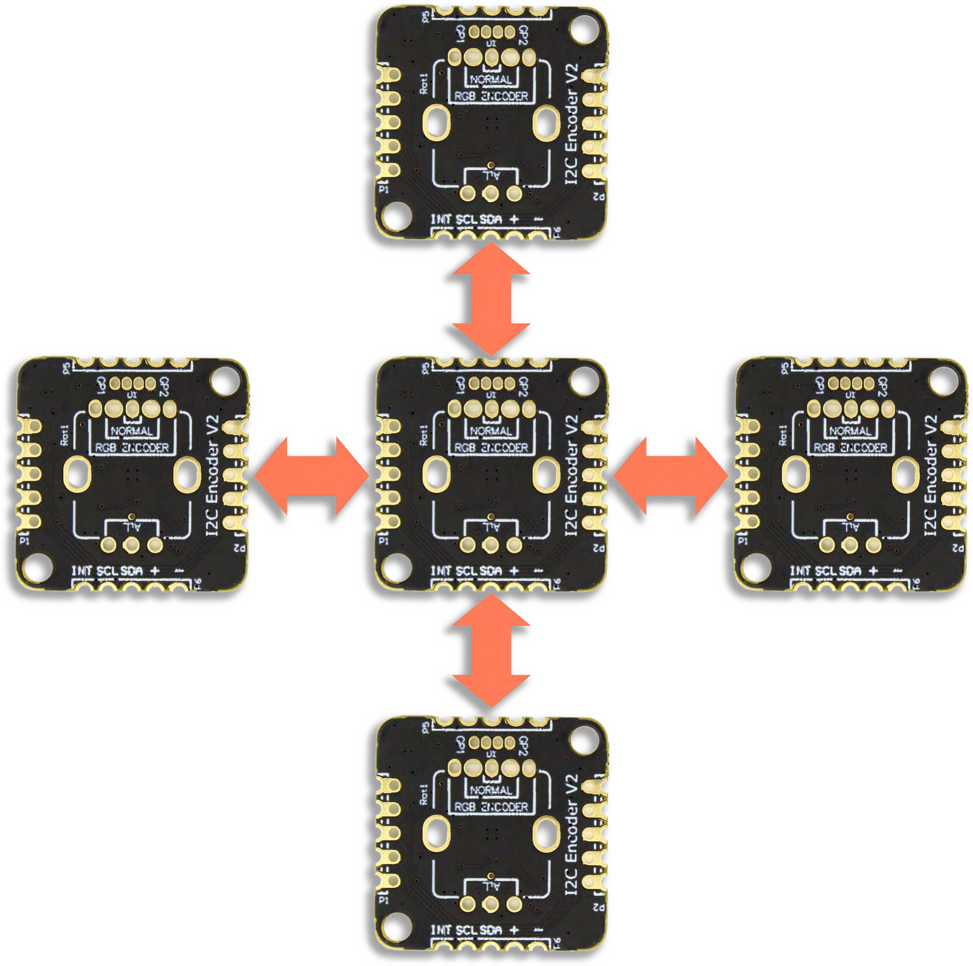
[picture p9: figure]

Figure 1.6: Easy way to create a custom encoder matrix

## 1.3 I²C interface

The I2C Encoder V2.1 is a I²C slave. In order to be as compatible as possible, the clock stretch feature is disabled by default, it is possible to enable it by setting the bit CKSRC of the second configuration register.

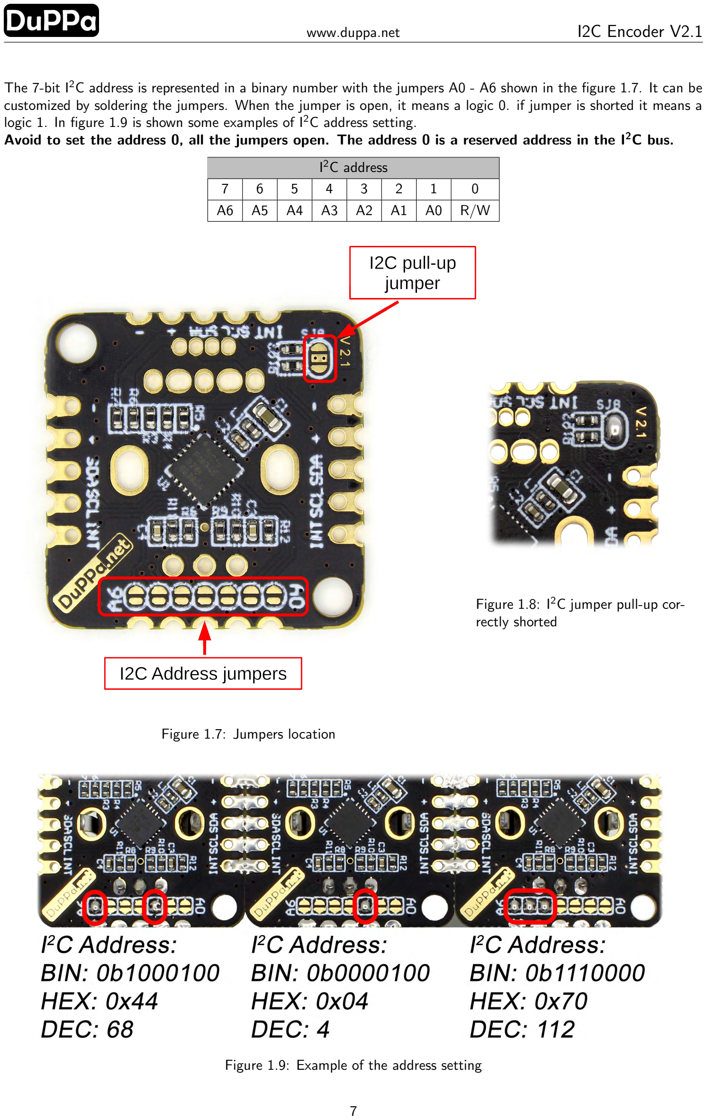
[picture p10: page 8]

The 7-bit I²C address is represented in a binary number with the jumpers A0 - A6 shown in the figure 1.7. It can be customized by soldering the jumpers. When the jumper is open, it means a logic 0. if jumper is shorted it means a logic 1. In figure 1.9 is shown some examples of I²C address setting.
Avoid to set the address 0, all the jumpers open. The address 0 is a reserved address in the I²C bus.

I

2C address

7 | 6 | 5 | 4 | 3 | 2 | 1 | 0
A6 | A5 | A4 | A3 | A2 | A1 | A0 | R/W

Figure 1.7: Jumpers location

Figure 1.8: I²C jumper pull-up cor-rectly shorted

Figure 1.9: Example of the address setting

The I2C Encoder V2.1 has built in 4.7kΩ pull-up resistors for the I²C bus. By default the resistors are disabled. It’s possible to enable them by soldering the jumper SJ8, in the figure 1.7 is showed the correct soldering. This must be done in case that the master doesn’t have these resistors and must be enabled only one I2C Encoder V2.1 in a chain.

## 1.4 Rotary encoder

On the I2C Encoder V2.1, it is possible to solder a standard rotary encoder and an illuminated RGB encoder. In the figure 1.12 is showed in witch pins with the standard encoder have to be soldered, while in the figure 1.13 is showed the pins used for the illuminated RGB encoder.
In both cases the encoder have to be soldered on the TOP face, where there are no components.

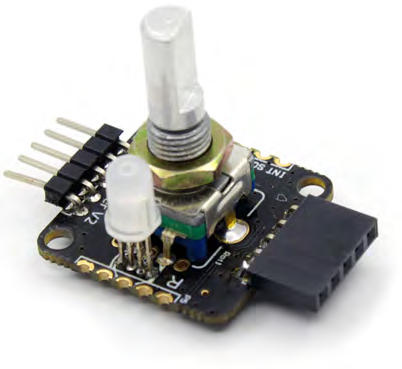
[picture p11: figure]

Figure 1.10: Example of assembled board with EC11 encoder, RGB LED and connectors

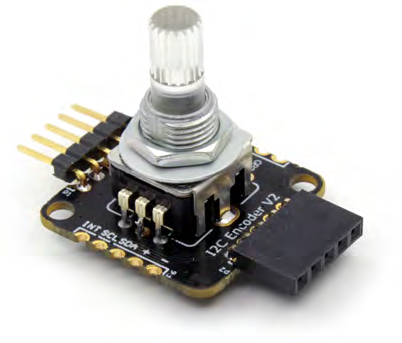
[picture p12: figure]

Figure 1.11: Example of assembled board with Illuminated RGB Encoder and connectors

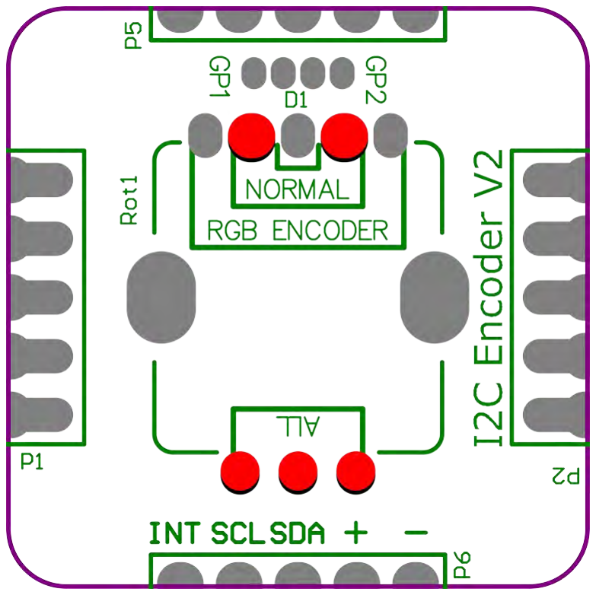
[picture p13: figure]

Figure 1.12: Used pins for mounting the standard rotary encoder

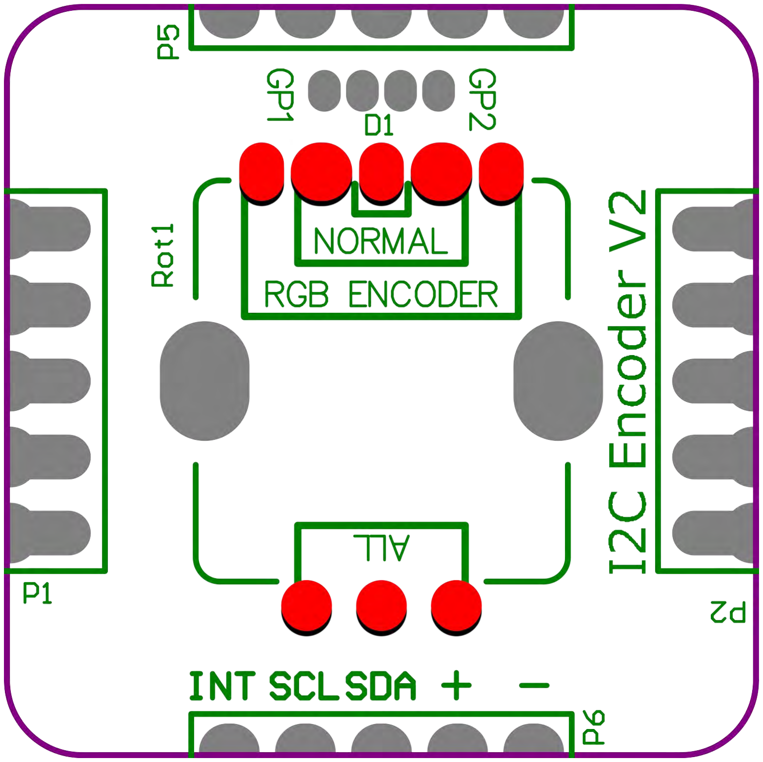
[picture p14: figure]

Figure 1.13: Used pins for mounting the RGB encoder

It’s possible to configure several option by setting the registers with the I²C bus. With the GCONF and GCONF2 registers, it is possible to configure several parameters.

In the configuration, it’s possible to set the rotation direction and also to set if the output of the encoder is X1 or X2.
In X1 mode the counting happens only on the falling edge of the channel A, The B channel is used for the direction. Most of the encoder have this type of encoding.
In X2 mode the it’s used both the falling and rising edge of the channel A, in this way the resolution is the double respect the X1. Few encoder have this type of encoding, or can be used for the encoder without dent.

For reading the rotary encoder movement, there are 4 32bit registers: CVAL, CMAX, CMIN and ISTEP. All of these 4 registers can be configured to work as 32bit int or as IEEE 754 floating number, this format can be set in the GCONF register.
The I2C Encoder V2.1 can work in two different way: absolute mode and relative mode. This option can be configured with the bit RELMODE.
By default it works in absolute mode. Every time the encoder moves one step, the value of the CVAL register is increased or decreased of the value of ISTEP. The direction of the rotation decides if ISTEP is added or subtracted from CVAL.
CMAX and CMIN are used for setting a minimum and maximum thresholds of CVAL. In the GCONF register, there is WRAPE bit. This bit is used to enable or disable a wrap functionality of CVAL when it exceeds from the thresholds.
If the bit RELMODE the I2C Encoder V2.1 works in relative mode, this mode is similar to the absolute mode, but every time the register CVAL is read it is automatically set to 0. In this way you know the number of step between two CVAL reading.

The counter limits are the following:

- 32bit INT: from −2.147.483.648 to +2.147.483.647
- IEEE 754 float: from −126, 0 to +127, 0

In case of 32bit INT, it is not necessary to read all the 4 bytes, you can read only the first 8 bit or the first 16 bit. For example, if you want to count between 0 and 10, you can read only the first byte of the CVAL register. In this way you can save I²C transactions.

Here a couple of example of how the I2C Encoder V2.1 works:

- CVAL= 0
- CMAX = 5
- CMIN = -5
- ISTEP= 1

I will have CVAL is incremented of 1 at each rotation step of the encoder. The maximum value that CVAL can reach will be 5 while the minimum is -5. In the figure 1.14 shows the value of CVAL.
As showed in the figure 1.15, when WRAPE is set to 1 when CVAL reaches the value of 5, at the next increment CVAL it will be wrapped to -5.
Every time when the encoder is rotated one step and when CVAL touch the thresholds, an interrupt is generated and is possible to read in the register ESTATUS.
The I2C Encoder V2.1 support also the rotary encoder with the push button. When the push button is pressed an interrupt is generated at the rising and falling edge. In this way, it is possible to check when the push button is pressed or released.
There is also possibility to read a fast double push by setting a window time in the register DPPERIOD. When a double push is made inside of the DPPERIOD window, an interrupt is generated.
If the DPPERIOD is 0, the double push function is disabled.
All the above interrupt are possible to read in the register ESTATUS, and can be also disabled with the register INTCONFIG.

The I2C Encoder V2.1 has a RC filer as anti-bouncing filter, but sometimes is not enough especially when the encoder is rotated slowly. In addition there is a digital filter made with fil-flops where it’s possible to configure the windows where the encoder signals are sampled.

With the register ANTBOUNC it’s possible to set the windows form 0.192ms up to 49.152ms with a step of 0.192ms. Value of 0 is not accepted and it is changed to 1.
The ANTBOUNC windows should be less than the maximum encoder frequency.

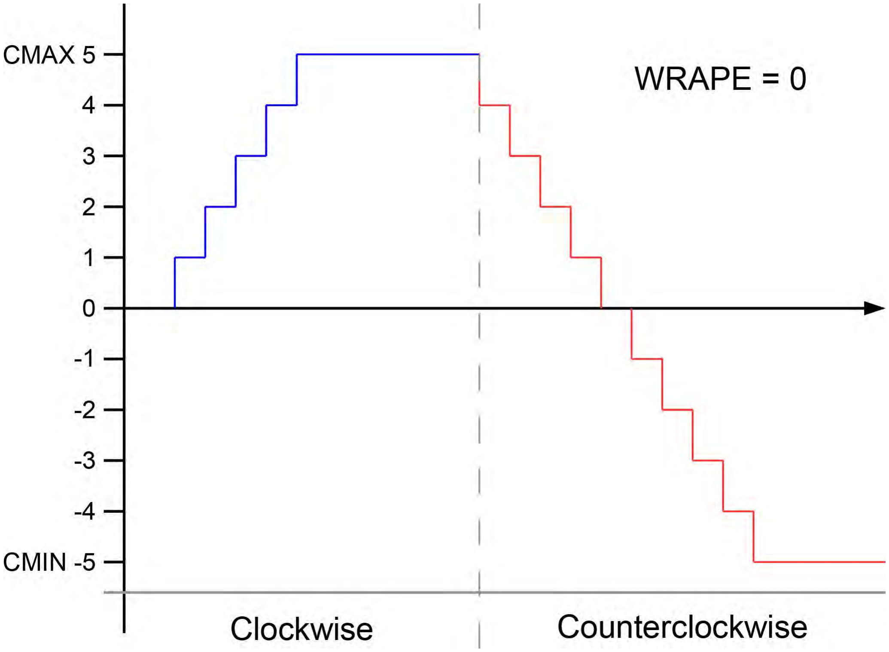
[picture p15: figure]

Figure 1.14: Blue and red line are the CVAL values when the encoder is rotate and the WRAPE is disabled

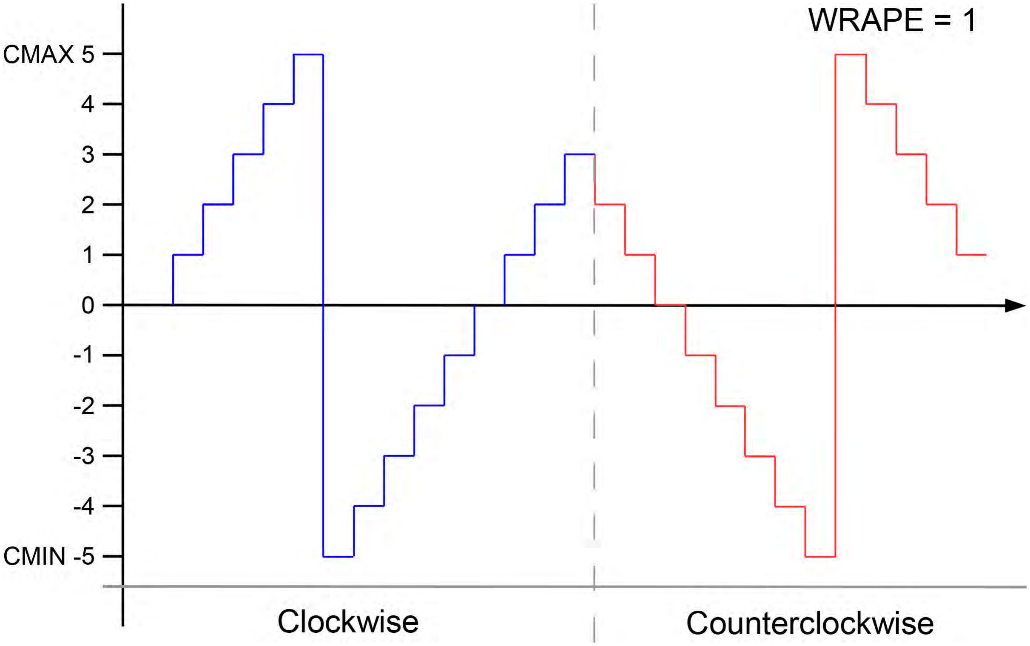
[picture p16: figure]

Figure 1.15: Blue and red line are the CVAL values when the encoder is rotate and the WRAPE is enabled

## 1.5 GP pins

There are 3 configurable GP pins, they are called GP1, GP2 and GP3. They have the same footprint of an 5mm RGB led. In figure 1.16, it is shown the position. Each pin can be configured to be:

- PWM: The pins is configured to be a PWM output.
- Analog input: The pins is configured to be an input of the internal ADC, the resolution is 8 bit.
- GPIO output: The pins is configured to be a digital output.
- GPIO Input: The pin is configured to be a digital input. It’s possible to set an interrupt at every signal edge.

In case of a RGB encoder is mounted, the GP3 will not be available. This because GP3 is internally connect to the red color of the RGB led and it is automatically configured to be a PWM.

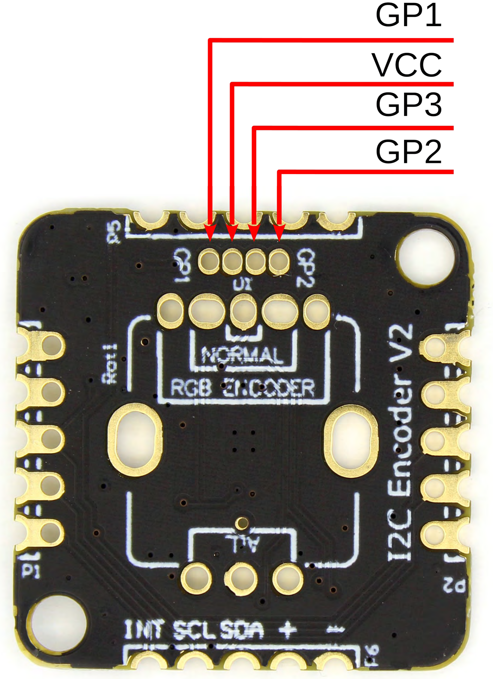
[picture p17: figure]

Figure 1.16: GP pins pinout

## 1.6 PWM

The I2C Encoder V2.1 have 6 configurable PWM outputs, 3 belong to the RGB LED of the RGB encoder, while the other 3 can be the GP pins. If the RGB Encoder is configured, only 2 PWM are available on the GP pins. The corresponding register are described in the section 2.5 for the RGB LEDs, and in the section 2.6 for the GP pins. There are a couple of features around the PWM, there is an automatic fading feature and the gamma correction in order to optimize the LED light.
The PWM resolution 10bit with a frequency of 31.25kHz, but the user can not access to the full resolution. By default the gamma correction in off and the user can access of a resolution of 8bit, from minimum is 0 and maximum of 255. 1
If a gamma correction is chose the PWM range change to maximum 100. In this way it’s possible to set a PWM value between 0% to 100% by writing 0 to 100 to the corresponding register.
In both case when the PWM is set to 0 the output is VCC, while when is set to it’s maximum the output is GND The PWM value can be changed in any moment during the board operation.

### 1.6.1 Fade function

The I2C Encoder V2.1 has an auto fading feature. This function can be enabled for the RGB LED of the rotary encoder, or in the PWM output of the GP pins.
There are two registers:
- FADERGB: for setting the RGB LED of the rotary encoder
- FADEGP: for setting the GP pins

The value of these registers is the step speed of the fading ramp, and it’s in ms. If the value is 0, the fade feature is disabled. It means that when the new value of PWM is written, it is immediately updated to the output.

In this way it’s compatible with the previous version I2C Encoder V2

The fading process starts when a PWM value is written. Fading process is complete according to the PWM value you have set. When the internal fade PWM value is the same of the PWM value (it means that when fading is complete), an interrupt will be generated. Let’s make an example:

At the startup, i write as:

- RLED = 0
- GLED = 0
- BLED = 0
- FADERGB = 1

In above case, the LEDs of the encoder are off and the fade has 1ms step size.
Now i write as: RLED=0xFF.
This moment, the ramp of the RLED starts and reaches the value 0xFF in 255ms. (the other LEDs remain OFF) When the ramp reaches 0xFF, i get an interrupt from the INT pin.
After this, i write as: RLED=0x00. At this point, the fade ramp starts again and it will turn off the LED in 255ms, and an interrupt will be generated at the end.
The figure 1.17 is showing an example of the fade output when a PWM value is written in different moments, as well as when the interrupt of the fade is generated.

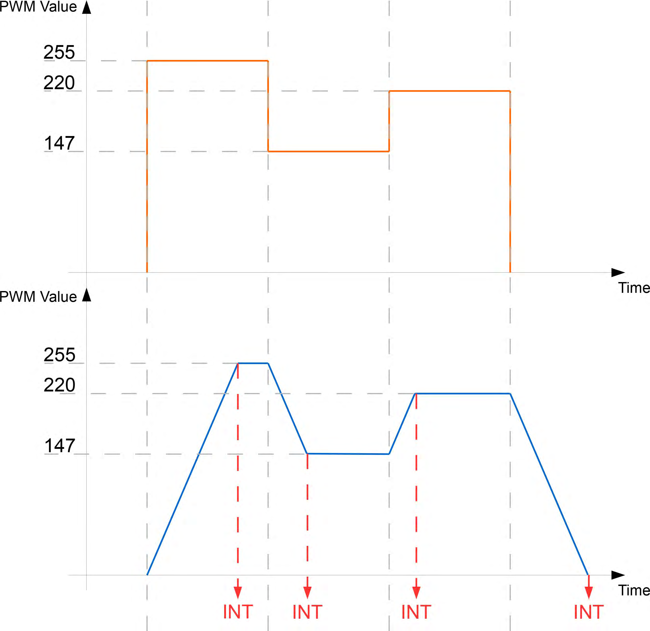
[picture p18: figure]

Figure 1.17: Time diagram of the fade output when writing on the PWM register

### 1.6.2 Gamma correction

The I2C Encoder V2.1 have in build a gamma correction function. This correction can be applied to all of the PWM output, such as the LEDs of the RGB encoder and the GP pins. The gamma correction is very useful in case you are using a LED, this because it make the luminosity of the LED more linear to our eys according to the PWM value. 2 There are six register where to configure the gamma correction and they are described in the section 2.8. It’s possible to configure 7 type of curve:

✥ Gamma OFF
✥ Gamma 1 (linear)

✥ Gamma 1.8

✥ Gamma 2.0

✥ Gamma 2.2

✥ Gamma 2.4

✥ Gamma 2.6

✥ Gamma 2.8

By default, the gamma correction is OFF, this means that it is possible to access to a 8bit PWM resolution. In the figure 1.18 is showed the relationship between the PWM at the full resolution and the PWM settable from the user.

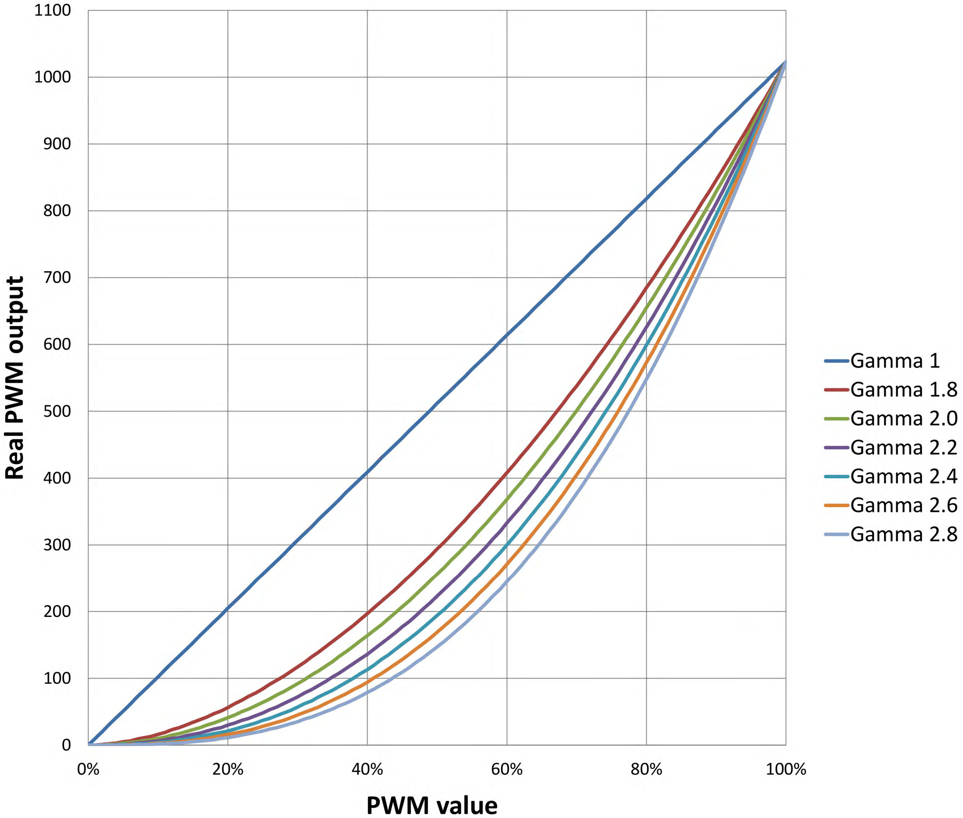
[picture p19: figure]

Figure 1.18: Possible gamma option

2For more information: https://en.wikipedia.org/wiki/Gamma correction (https://en.wikipedia.org/wiki/Gamma_correction)

## 1.7 EEPROM

The I2C Encoder V2.1 has 256 bytes of EEPROM.
This memory is divided in two banks of 128 bytes. With the bit MBANK in the GCONF register, it is possible to choose the bank 1 or the bank 2.
The memory area is between 0x80 and 0xFF address. To use the EEPROM, user only needs to perform reading or a writing in these address areas.
The writing time takes 4 - 5ms to be executed. Wait this time before sending other commands.

## 1.8 Interrupt

The I2C Encoder V2.1 has multiple interrupt source previously described. When an interrupt is generated, the INT pin is tied low. By reading the register ESTATUS, the interrupts are cleared and the INT pin returns high.
The INT pin is open-drain output. Hence it requires an external pull-up resistor, or internal pull-up resistor can be enabled by setting the bit IPUD to 1.
In a chain of I2C Encoder V2.1 all the INT pins can be connected together, like the pin of the I²C. When an interrupt occurs, user has to scan the boards in the chain to find who generates the interrupt.
With the register INTCONF, it is possible to enable or disable interrupt. When an interrupt is disabled, the corresponding bit is set, but the INT pin is not affected.

# 2. Registers

In this section, the internal registers of I2C Encoder V2.1 is described.
The I2C Encoder V2.1 has the auto increment feature. This means that after writing or reading a register, the internal address pointer is automatically incremented by one.

Address range | Name | Description | Dimension | Default value
0x00 | GCONF | General Configuration | 1 Byte | 0
0x01 | GP1CONF | GP 1 Configuration | 1 Byte | 0
0x02 | GP2CONF | GP 2 Configuration | 1 Byte | 0
0x03 | GP3CONF | GP 3 Configuration | 1 Byte | 0
0x04 | INTCONF | INT pin Configuration | 1 Byte | 0
0x05 | ESTATUS | Encoder Status | 1 Byte | 0
0x06 | I2STATUS | Secondary interrupt status | 1 Byte | 0
0x07 | FSTATUS | Fade process status | 1 Byte | 0
0x08 - 0x0B | CVAL | Counter Value | 4 Byte | 0
0x0C - 0x0F | CMAX | Counter Max value | 4 Byte | 0
0x10 - 0x13 | CMIN | Counter Min value | 4 Byte | 0
0x14 - 0x17 | ISTEP | Increment step value | 4 Byte | 0
0x18 | RLED | LED red color intensity | 1 Byte | 0
0x19 | GLED | LED green color intensity | 1 Byte | 0
0x1A | BLED | LED blue color intensity | 1 Byte | 0
0x1B | GP1REG | I/O GP1 register | 1 Byte | 0
0x1C | GP2REG | I/O GP2 register | 1 Byte | 0
0x1D | GP3REG | I/O GP3 register | 1 Byte | 0
0x1E | ANTBOUNC | Anti-bouncing period | 1 Byte | 1
0x1F | DPPERIOD | Double push period | 1 Byte | 0
0x20 | FADERGB | Fade timer RGB Encoder | 1 Byte | 0
0x21 | FADEGP | Fade timer GP ports | 1 Byte | 0
0x27 | GAMRLED | Gamma correction on red LED | 1 Byte | 0
0x28 | GAMGLED | Gamma correction on green LED | 1 Byte | 0
0x29 | GAMBLED | Gamma correction on blue LED | 1 Byte | 0
0x2A | GAMMAGP1 | Gamma correction on PWM of GP1 | 1 Byte | 0
0x2B | GAMMAGP2 | Gamma correction on PWM of GP2 | 1 Byte | 0
0x2C | GAMMAGP3 | Gamma correction on PWM of GP3 | 1 Byte | 0
0x30 | GCONF2 | Second configuration | 1 Byte | 0
0x70 | IDCODE | I2C Encoder V2.1 unique code | 1 Byte | 0x53
0x71 | VERSION | I2C Encoder V2.1 version | 1 Byte | 0x23
0x80 - 0xFF | EEPROM | EEPROM memory | 128 Byte | 0

## 2.1 Configuration

### 2.1.1 General Configuration

GCONF Address: 0x00
7 | 6 | 5 | 4 | 3 | 2 | 1 | 0
R/W-0 | R/W-0 | R/W-0 | R/W-0 | R/W-0 | R/W-0 | R/W-0 | R/W-0
RESET | MBANK | ETYPE | RMOD | IPUD | DIRE | WRAPE | DTYPE

❖ DTYPE Data type of the register: CVAL, CMAX, CMIN and ISTEP.

1: The registers are considered float numbers IEEE 754

0: The registers are considered int 32bit

❖ WRAPE Enable counter wrap.

1: Wrap enable. When the counter value reaches the CMAX+1, restart to the CMIN and vice versa

0: Wrap disable. When the counter value reaches the CMAX or CMIN, the counter stops to increasing or decreasing

❖ DIRE Direction of the encoder when increment.

1: Rotate left side to increase the value counter

0: Rotate right side to increase the value counter

❖ IPUD Interrupt Pull-UP disable.

1: Disable

0: Enable

❖ RMOD Reading Mode.

1: X2 mode

0: X1 mode

❖ ETYPE Set the encoder type

1: RGB illuminated encoder

0: Standard encoder

❖ MBANK Select the EEPROM memory bank. Each bank are 128 byte wide

1: Second memory bank

0: First memory bank

❖ RST Reset of the I2C Encoder V2.1

1: Reset of the I2C Encoder V2.1. The RESET command takes 400us to be executed.

0: No reset

### 2.1.2 Second Configuration

This register is available only in the I2C Encoder V2.1.

GCONF2 Address: 0x30
7 | 6 | 5 | 4 | 3 | 2 | 1 | 0
R/W-0 | R/W-0 | R/W-0 | R/W-0 | R/W-0 | R/W-0 | R/W-0 | R/W-0
- | - | - | - | - | - | RELMOD | CKSRC

❖ CKSRC I

2C clock stretch option.

1: Enable the I²C clock stretch.

0: Disable the I²C clock stretch.

❖ RELMOD CVAL working mode

1: Enable the relative mode of the CVAL register.

0: Disable the relative mode of the CVAL register.

### 2.1.3 GP1 Configuration

GP1CONF Address: 0x01
7 | 6 | 5 | 4 | 3 | 2 | 1 | 0
R/W-0 | R/W-0 | R/W-0 | R/W-0 | R/W-0 | R/W-0 | R/W-0 | R/W-0
- | - | - | GP1INT | | GP1PUL | GP1MODE

❖ GP1MODE Configuration of the pin GP1

00: PWM output
01: GPIO output Push-Pull

10: Analog input
11: GPIO Input

❖ GP1PUL Enable or disable the internal pull-up.

0: Pull-UP disable

1: Pull-UP enabled

❖ GP1INT Configuration of the interrupt, available only when the pin is configured as input

00: Interrupt disabled

01: Interrupt on positive edge

10: Interrupt on negative edge

11: Interrupt on both edges

### 2.1.4 GP2 Configuration

GP2CONF Address: 0x02
7 | 6 | 5 | 4 | 3 | 2 | 1 | 0
R/W-0 | R/W-0 | R/W-0 | R/W-0 | R/W-0 | R/W-0 | R/W-0 | R/W-0
- | - | - | GP2INT | | GP2PUL | GP2MODE

❖ GP2MODE Configuration of the pin GP2

00: PWM output
01: GPIO output Push-Pull

10: Analog input
11: GPIO Input

❖ GP2PUL Enable or disable the internal pull-up.

0: Pull-UP disable

1: Pull-UP enabled

❖ GP2INT Configuration of the interrupt, available only when the pin is configured as input

00: Interrupt disabled

01: Interrupt on positive edge

10: Interrupt on negative edge

11: Interrupt on both edges

### 2.1.5 GP3 Configuration

GP3CONF Address: 0x03
7 | 6 | 5 | 4 | 3 | 2 | 1 | 0
R/W-0 | R/W-0 | R/W-0 | R/W-0 | R/W-0 | R/W-0 | R/W-0 | R/W-0
- | - | - | GP3INT | | GP3PUL | GP3MODE

Note: When the ETYPE bit is set, this pin is in PWM mode automatically and can’t be changed.

❖ GP3MODE Configuration of the pin GP3

00: PWM output
01: GPIO output Push-Pull

10: Analog input
11: GPIO Input

❖ GP3PUL Enable or disable the internal pull-up.

0: Pull-UP disable

1: Pull-UP enabled

❖ GP3INT Configuration of the interrupt, available only when the pin is configured as input

00: Interrupt disabled

01: Interrupt on positive edge

10: Interrupt on negative edge

11: Interrupt on both edges

## 2.2 Interrupt output Configuration

This register is used for enable or disable the interrupt source selectively. When an interrupt event occurs, the INT pin goes low and the event is stored in the status register.

INTCONF Address: 0x04
7 | 6 | 5 | 4 | 3 | 2 | 1 | 0
R/W-0 | R/W-0 | R/W-0 | R/W-0 | R/W-0 | R/W-0 | R/W-0 | R/W-0
INT2 | IRMIN | IRMAX | IRDEC | IRINC | IPUSHD | IPUSHP | IPUSHR

❖ IPUSHR Push button release bit

1: Interrupt enabled when the push button is released.

0: Interrupt disabled

❖ IPUSHP Push button press bit

1: Interrupt enabled when the push button is pressed.

0: Interrupt disabled

❖ IPUSHD Push button double press

1: Interrupt enabled when the push button is double pressed.

0: Interrupt disabled

❖ IRINC Rotary encoder direction of increase

1: Interrupt enabled when the encoder is rotated in the direction of increase

0: Interrupt disabled

❖ IRDEC Rotary encoder direction of decrease

1: Interrupt enabled when the encoder is rotated in the direction of decrease

0: Interrupt disabled

❖ IRMAX CVAL reaches CMAX bit

1: Interrupt enabled when CVAL reaches CMAX

0: Interrupt disabled

❖ IRMIN CVAL reaches CMIN bit

1: Interrupt enabled when CVAL reaches CMIN

0: Interrupt disabled

❖ INT2 Enable the secondary interrupts

1: Secondary interrupt enabled

0: Secondary interrupt disabled

## 2.3 Status

### 2.3.1 Encoder Status

This register if only readable, when is read is automatically cleared.

ESTATUS Address: 0x05
7 | 6 | 5 | 4 | 3 | 2 | 1 | 0
R-0 | R-0 | R-0 | R-0 | R-0 | R-0 | R-0 | R-0
INT2 | RMIN | RMAX | RDEC | RINC | PUSHD | PUSHP | PUSHR

❑ PUSHR Status of the push button of the encoder

1: Push button is released

0: Push button is not released

❑ PUSHP Status of the push button of the encoder

1: Push button is pressed

0: Push button is not pressed

❑ PUSHD Status of the push button of the encoder

1: Push button is double pressed

0: Push button is not double pressed

❑ RINC Rotary encoder is rotated in the increase direction

1: Encoder is rotated

0: Encoder is not rotated

❑ RDEC Rotary encoder is rotated in the decrease direction

1: Encoder is rotated

0: Encoder is not rotated

❑ RMAX Status of the counter value

1: CVAL reaches the CMAX value

0: CVAL is below the CMAX value

❑ RMIN Status of the counter value

1: CVAL reaches the CMIN value

0: CVAL is above the CMIN value

❑ SINT2 Secondary interrupt status

1: Secondary interrupt event occurs

0: No secondary event occurs

### 2.3.2 Secondary interrupt status

In this register is possible to check the event of the fade process as well as the GP pins when is configured as input. This register if only readable, when is read is automatically cleared.

I2STATUS Address: 0x06
7 | 6 | 5 | 4 | 3 | 2 | 1 | 0
R-0 | R-0 | R-0 | R-0 | R-0 | R-0 | R-0 | R-0
- | FADE | EGP3 | | EGP2 | | EGP1

❑ GP1 Configuration of the GP1

00: No event occurs

01: Positive edge event

10: Negative edge event

❑ GP2 Configuration of the GP2.

00: No event occurs

01: Positive edge event

10: Negative edge event

❑ GP3 Configuration of the GP3. Available only with the standard encoder

00: No event occurs

01: Positive edge event

10: Negative edge event

❑ FADE Fade event occurs

1: Fade process event

0: No event in the fade process

### 2.3.3 Fade process status

With this register is possible to check the status of the PWM channel during the fade process. This register is only readable and the bits are set or cleared automatically during the fade process.

FSTATUS Address: 0x07
7 | 6 | 5 | 4 | 3 | 2 | 1 | 0
R-0 | R-0 | R-0 | R-0 | R-0 | R-0 | R-0 | R-0
- | - | FGP3 | FGP2 | FGP1 | FEB | FEG | FER

❑ FER Fade status process of the RGB Encoder color red

1: Fade process is running

0: Fade process terminated

❑ FEG Fade status process of the RGB Encoder color green

1: Fade process is running

0: Fade process terminated

❑ FEB Fade status process of the RGB Encoder color blue

1: Fade process is running

0: Fade process terminated

❑ GP1 Fade status process of the GP pin 1

1: Fade process is running

0: Fade process terminated

❑ GP2 Fade status process of the GP pin 2

1: Fade process is running

0: Fade process terminated

❑ GP3 Fade status process of the GP pin 3

1: Fade process is running

0: Fade process terminated

## 2.4 Encoder registers

### 2.4.1 Counter Value

CVAL Address: 0x08
31 | 30 | 29 | 28 | 27 | 26 | 25 | 24
R/W-0 | R/W-0 | R/W-0 | R/W-0 | R/W-0 | R/W-0 | R/W-0 | R/W-0
CVAL BYTE 4 <31 - 24>
Address: 0x09
23 | 22 | 21 | 20 | 19 | 18 | 17 | 16
R/W-0 | R/W-0 | R/W-0 | R/W-0 | R/W-0 | R/W-0 | R/W-0 | R/W-0
CVAL BYTE 3 <23 - 16>
Address: 0x0A
15 | 14 | 13 | 12 | 11 | 10 | 9 | 8
R/W-0 | R/W-0 | R/W-0 | R/W-0 | R/W-0 | R/W-0 | R/W-0 | R/W-0
CVAL BYTE 2 <15 - 8>
Address: 0x0B
7 | 6 | 5 | 4 | 3 | 2 | 1 | 0
R/W-0 | R/W-0 | R/W-0 | R/W-0 | R/W-0 | R/W-0 | R/W-0 | R/W-0
CVAL BYTE 1 <7 - 0>

### 2.4.2 Counter Max

CMAX Address: 0x0C
31 | 30 | 29 | 28 | 27 | 26 | 25 | 24
R/W-0 | R/W-0 | R/W-0 | R/W-0 | R/W-0 | R/W-0 | R/W-0 | R/W-0
CMAX BYTE 4 <31 - 24>
Address: 0x0D
23 | 22 | 21 | 20 | 19 | 18 | 17 | 16
R/W-0 | R/W-0 | R/W-0 | R/W-0 | R/W-0 | R/W-0 | R/W-0 | R/W-0
CMAX BYTE 3 <23 - 16>
Address: 0x0E
15 | 14 | 13 | 12 | 11 | 10 | 9 | 8
R/W-0 | R/W-0 | R/W-0 | R/W-0 | R/W-0 | R/W-0 | R/W-0 | R/W-0
CMAX BYTE 2 <15 - 8>
Address: 0x0F
7 | 6 | 5 | 4 | 3 | 2 | 1 | 0
R/W-0 | R/W-0 | R/W-0 | R/W-0 | R/W-0 | R/W-0 | R/W-0 | R/W-0
CMAX BYTE 1 <7 - 0>

### 2.4.3 Counter Min

CMIN Address: 0x10
31 | 30 | 29 | 28 | 27 | 26 | 25 | 24
R/W-0 | R/W-0 | R/W-0 | R/W-0 | R/W-0 | R/W-0 | R/W-0 | R/W-0
CMIN BYTE 4 <15 - 8>
Address: 0x11
23 | 22 | 21 | 20 | 19 | 18 | 17 | 16
R/W-0 | R/W-0 | R/W-0 | R/W-0 | R/W-0 | R/W-0 | R/W-0 | R/W-0
CMIN BYTE 3 <7 - 0>
Address: 0x12
15 | 14 | 13 | 12 | 11 | 10 | 9 | 8
R/W-0 | R/W-0 | R/W-0 | R/W-0 | R/W-0 | R/W-0 | R/W-0 | R/W-0
CMIN BYTE 2 <15 - 8>
Address: 0x13
7 | 6 | 5 | 4 | 3 | 2 | 1 | 0
R/W-0 | R/W-0 | R/W-0 | R/W-0 | R/W-0 | R/W-0 | R/W-0 | R/W-0
CMIN BYTE 1 <7 - 0>

### 2.4.4 Increment step

ISTEP Address: 0x14
31 | 30 | 29 | 28 | 27 | 26 | 25 | 24
R/W-0 | R/W-0 | R/W-0 | R/W-0 | R/W-0 | R/W-0 | R/W-0 | R/W-0
ISTEP BYTE 4 <15 - 8>
Address: 0x15
23 | 22 | 21 | 20 | 19 | 18 | 17 | 16
R/W-0 | R/W-0 | R/W-0 | R/W-0 | R/W-0 | R/W-0 | R/W-0 | R/W-0
ISTEP BYTE 3 <7 - 0>
Address: 0x16
15 | 14 | 13 | 12 | 11 | 10 | 9 | 8
R/W-0 | R/W-0 | R/W-0 | R/W-0 | R/W-0 | R/W-0 | R/W-0 | R/W-0
ISTEP BYTE 2 <15 - 8>
Address: 0x17
7 | 6 | 5 | 4 | 3 | 2 | 1 | 0
R/W-0 | R/W-0 | R/W-0 | R/W-0 | R/W-0 | R/W-0 | R/W-0 | R/W-0
ISTEP BYTE 1 <7 - 0>

## 2.5 LEDs registers

### 2.5.1 LED Red intensity

RLED Address: 0x18
7 | 6 | 5 | 4 | 3 | 2 | 1 | 0
R/W-0 | R/W-0 | R/W-0 | R/W-0 | R/W-0 | R/W-0 | R/W-0 | R/W-0
RED LED PWM Value <7 - 0>

This register is used for setting the PWM of the red LED of the RGB encoder. A value of 0x00 means PWM at 0%, LED OFF. A value of 0xFF means PWM at 100%, LED completely ON.

### 2.5.2 LED Green intensity

GLED Address: 0x19
7 | 6 | 5 | 4 | 3 | 2 | 1 | 0
R/W-0 | R/W-0 | R/W-0 | R/W-0 | R/W-0 | R/W-0 | R/W-0 | R/W-0
GREEN LED PWM Value <7 - 0>

This register is used for setting the PWM of the green LED of the RGB encoder. A value of 0x00 means PWM at 0%, LED OFF. A value of 0xFF means PWM at 100%, LED completely ON.

### 2.5.3 LED Blue intensity

BLED Address: 0x1A
7 | 6 | 5 | 4 | 3 | 2 | 1 | 0
R/W-0 | R/W-0 | R/W-0 | R/W-0 | R/W-0 | R/W-0 | R/W-0 | R/W-0
BLUE LED PWM Value <7 - 0>

This register is used for setting the PWM of the blue LED of the RGB encoder. A value of 0x00 means PWM at 0%, LED OFF. A value of 0xFF means PWM at 100%, LED completely ON.

## 2.6 GPs registers

The usage of these register depends of the configuration of the GP pins:

- PWM Is possible to write the PWM value.
- GPIO output: Is possible to write 1 or 0 for setting the output logic level.
- Analog input: Is possible to read the ADC value
- GPIO Input: Is possible to read the logic level of the output

### 2.6.1 GP1 register

GP1REG Address: 0x1B
7 | 6 | 5 | 4 | 3 | 2 | 1 | 0
R/W-0 | R/W-0 | R/W-0 | R/W-0 | R/W-0 | R/W-0 | R/W-0 | R/W-0
GP1 Value <7 - 0>

### 2.6.2 GP2 register

GP2REG Address: 0x1C
7 | 6 | 5 | 4 | 3 | 2 | 1 | 0
R/W-0 | R/W-0 | R/W-0 | R/W-0 | R/W-0 | R/W-0 | R/W-0 | R/W-0
GP2 Value <7 - 0>

### 2.6.3 GP3 register

GP3REG Address: 0x1D
7 | 6 | 5 | 4 | 3 | 2 | 1 | 0
R/W-0 | R/W-0 | R/W-0 | R/W-0 | R/W-0 | R/W-0 | R/W-0 | R/W-0
GP3 Value <7 - 0>

## 2.7 Timing registers

This register are used for changing some timing parameter

### 2.7.1 Anti-bouncing period

This register is used for setting the anti-bounce window. The range if from 0.192ms to 49.152ms with a step of 0.192ms. The default value is 1, it meas a window of 0.192ms. Value of 0 is not accepted and is converted to 1.

ANTBOUNC Address: 0x1E
7 | 6 | 5 | 4 | 3 | 2 | 1 | 0
R/W-0 | R/W-0 | R/W-0 | R/W-1 | R/W-1 | R/W-0 | R/W-0 | R/W-1
PBOUN <7 - 0>

### 2.7.2 Double push time

This register is used for setting the double push of the rotary encoder switch. The value is in ms × 10. When this register is 0 this function is disabled.

DPPERIOD Address: 0x1F
7 | 6 | 5 | 4 | 3 | 2 | 1 | 0
R/W-0 | R/W-0 | R/W-0 | R/W-0 | R/W-0 | R/W-0 | R/W-0 | R/W-0
PDPUSH <7 - 0>

### 2.7.3 Fade RGB encoder LED

This register is used for setting the fade speed of the RGB LED of the rotary encoder. The value is in ms and indicate the time of one step. If a standard rotary encoder is used, this register is not used.

FADERGB Address: 0x20
7 | 6 | 5 | 4 | 3 | 2 | 1 | 0
R/W-0 | R/W-0 | R/W-0 | R/W-0 | R/W-0 | R/W-0 | R/W-0 | R/W-0
FADERGB <7 - 0>

### 2.7.4 Fade GP ports

This register is used for setting the fade speed of the GP ports. The value is in ms and indicate the time of one step. This register is working only if the GP port are configured in PWM

FADEGP Address: 0x21
7 | 6 | 5 | 4 | 3 | 2 | 1 | 0
R/W-0 | R/W-0 | R/W-0 | R/W-0 | R/W-0 | R/W-0 | R/W-0 | R/W-0
FADEGP <7 - 0>

## 2.8 Gamma correction

This register is used for applying a gamma correction of the PWM output It can be very useful when a LED is connected.
This three registers are only for the RGB led of the RGB encoder

GAMRLED Address: 0x27
7 | 6 | 5 | 4 | 3 | 2 | 1 | 0
- | - | - | - | | R/W-0 | R/W-0 | R/W-0
| | | | | GAMRLED <2 - 0>

GAMGLED Address: 0x28
7 | 6 | 5 | 4 | 3 | 2 | 1 | 0
- | - | - | - | | R/W-0 | R/W-0 | R/W-0
| | | | | GAMGLED <2 - 0>

GAMBLED Address: 0x29
7 | 6 | 5 | 4 | 3 | 2 | 1 | 0
- | - | - | - | | R/W-0 | R/W-0 | R/W-0
| | | | | GAMBLED <2 - 0>

❑ GAMxLED Gamma curve selector for RGB led of the rotary encoder

000: Gamma OFF, the PWM register work like the V2.0

001: Gamma 1

010: Gamma 1.8

011: Gamma 2.0

100: Gamma 2.2

101: Gamma 2.4

110: Gamma 2.6

111: Gamma 2.8

This other three registers are used only when the corresponding GP pins is set to PWM.

GAMMAGP1 Address: 0x2A
7 | 6 | 5 | 4 | 3 | 2 | 1 | 0
- | - | - | - | | R/W-0 | R/W-0 | R/W-0
| | | | | GAMMAGP1 <2 - 0>

GAMMAGP2 Address: 0x2B
7 | 6 | 5 | 4 | 3 | 2 | 1 | 0
- | - | - | - | | R/W-0 | R/W-0 | R/W-0
| | | | | GAMMAGP2 <2 - 0>

GAMMAGP3 Address: 0x2C
7 | 6 | 5 | 4 | 3 | 2 | 1 | 0
- | - | - | - | | R/W-0 | R/W-0 | R/W-0
| | | | | GAMMAGP3 <2 - 0>

❑ GAMMAGPx Gamma curve selector for the PWM pins

000: Gamma OFF, the PWM register work like the V2.0

001: Gamma 1

010: Gamma 1.8

011: Gamma 2.0

100: Gamma 2.2

101: Gamma 2.4

110: Gamma 2.6

111: Gamma 2.8

## 2.9 I2C Encoder V2.1 unique code

This register contains an unique code that it’s used to identify the I2C Encoder V2.1. This register is only readable and not writable.

IDCODE Address: 0x70
7 | 6 | 5 | 4 | 3 | 2 | 1 | 0
R-0 | R-1 | R-0 | R-1 | R-1 | R-0 | R-1 | R-1
IDCODE = 0x53

## 2.10 I2C Encoder V2.1 version

This register contains the version of the I2C Encoder V2.1. This value will change in case of a new hardware or firmware release. This register is only readable and not writable.

VERSION Address: 0x71
7 | 6 | 5 | 4 | 3 | 2 | 1 | 0
R-0 | R-0 | R-0 | R-1 | R-0 | R-0 | R-0 | R-1
Version = 0x23

# 3. Reference

This project is open source, the HW and the FW as well as some example can be found on GitHub: https://github.com/Fattoresaimon/I2CEncoderV2.1

The HW project can be found on Circuit Maker site: https://workspace.circuitmaker.com/Projects/Details/Simone--Caron/I2C-Encoder-V2

# 4. Programming

The I2C Encoder V2.1 can be easily programmed with a customized firmware or with an official updated version. For programming the I2C Encoder V2.1 it’s required an external programmer, such us the PICkit 3 or the PICkit 4. The I2C Encoder V2 can be flashed with the FW of the I2C Encoder V2.1.

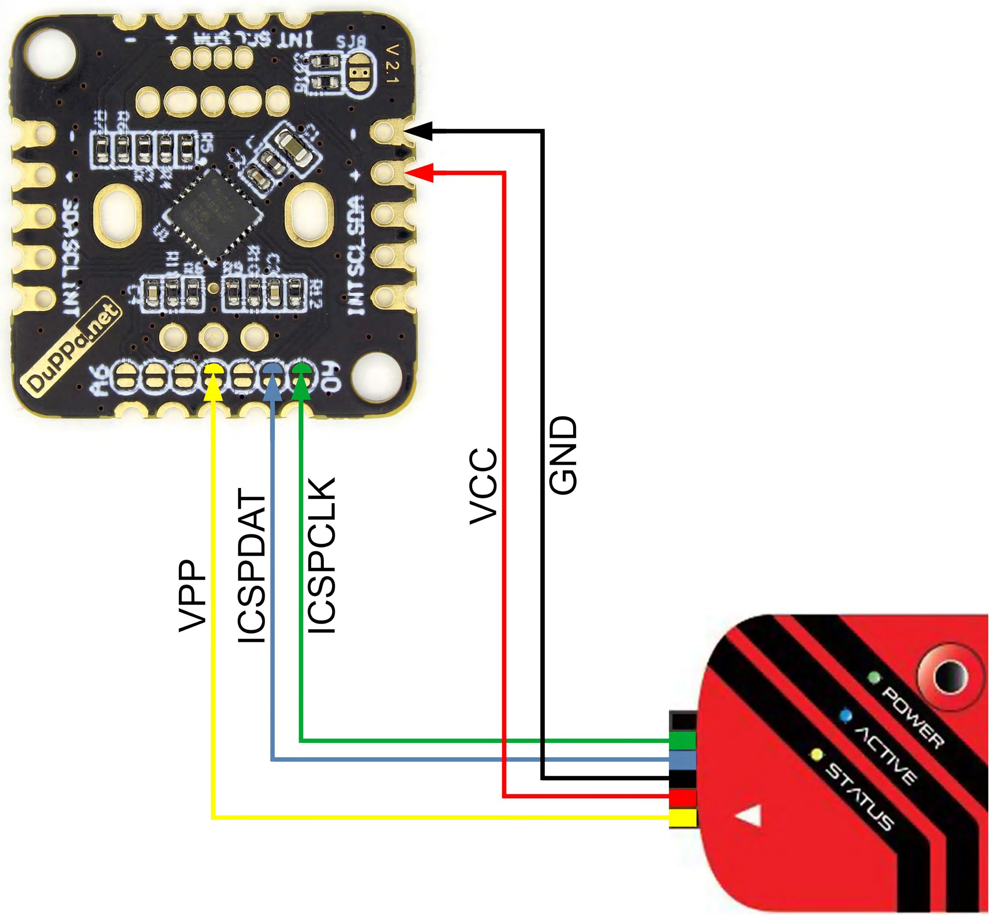
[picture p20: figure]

Figure 4.1: Schematic for programming with the PICkit 3

# 5. Changelog

In this chapter there are the hardware and firmware changes between the board version.

## I2C Encoder HW2.1 FW2.3 :

VERSION register value: 0x23

Firmware changes:

- Changed the ANTBOUNC register usage.
- Changed the method of detecting the encoder rotation.

## I2C Encoder HW2.1 FW2.1 :

VERSION register value: 0x21

Hardware changes:

- Added the jumper SJ8 for enable the pull-up resistor in the I²C bus.
- R1 and R2 are already soldered on the board with a 0402 footprint.
- Changed the value of R3 and R4 with 42.2Ω.
- Changed the value of R5 with 107Ω.

Firmware changes:

- Added the gamma correction feature.
- Added the unique code and the version registers.
- Added the possibility to enable/disable the I²C clock stretch.
- Added the possibility to count absolute or relative steps.
- Added and extra delay after the detection of the double-push.
- Changed the PWM frequency from 125kHz to 31,25kHz
- Decreased of the ∼33% the power consumption.
- Changed the default value of ISTEP from 1 to 0.

## I2C Encoder V2:

First version of the I2C Encoder V2.

# 6. Issues

In this section, there are listed the known bugs of the I2C Encoder V2.

# 7. Schematic

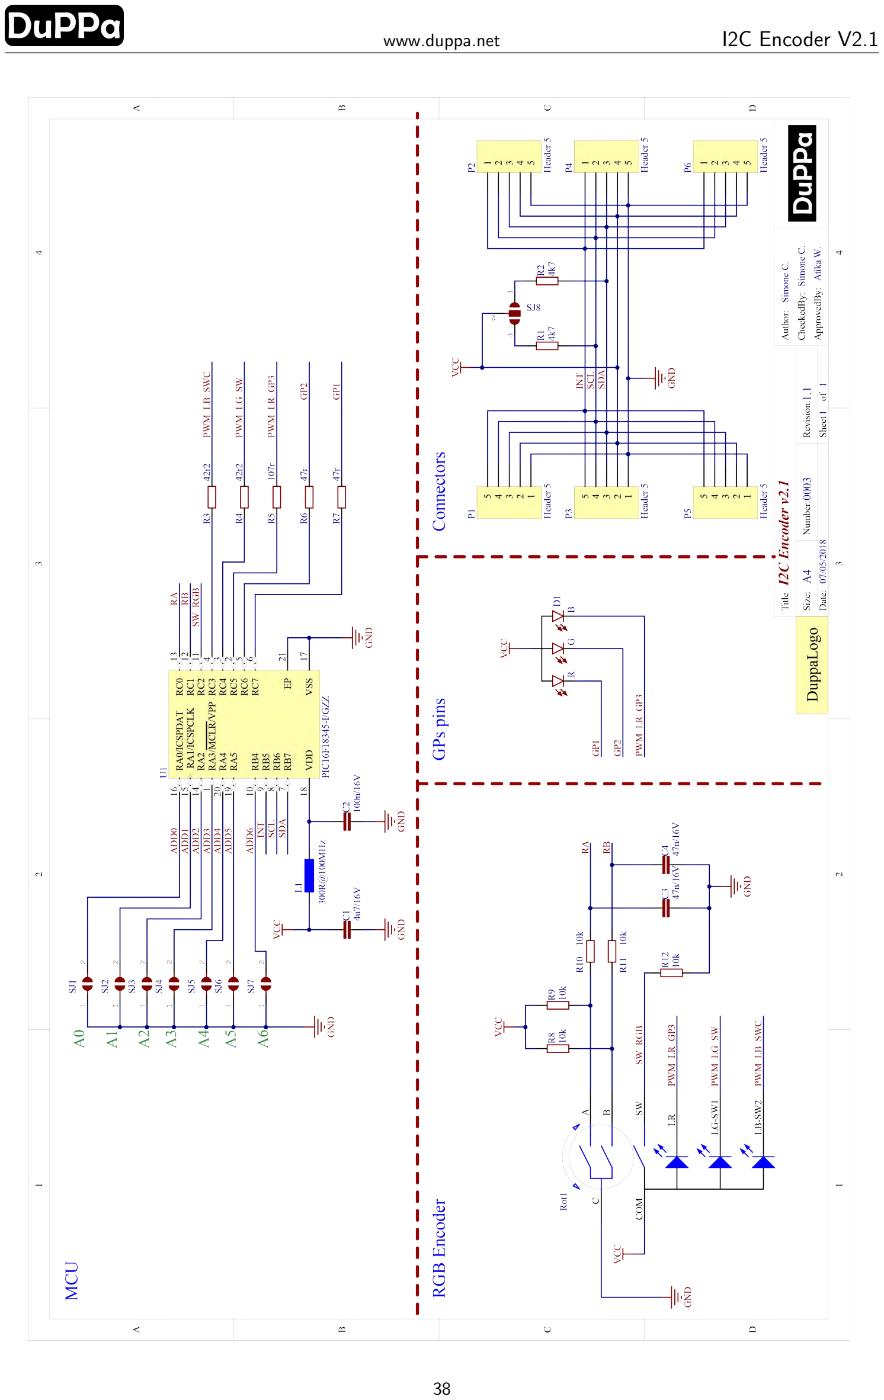
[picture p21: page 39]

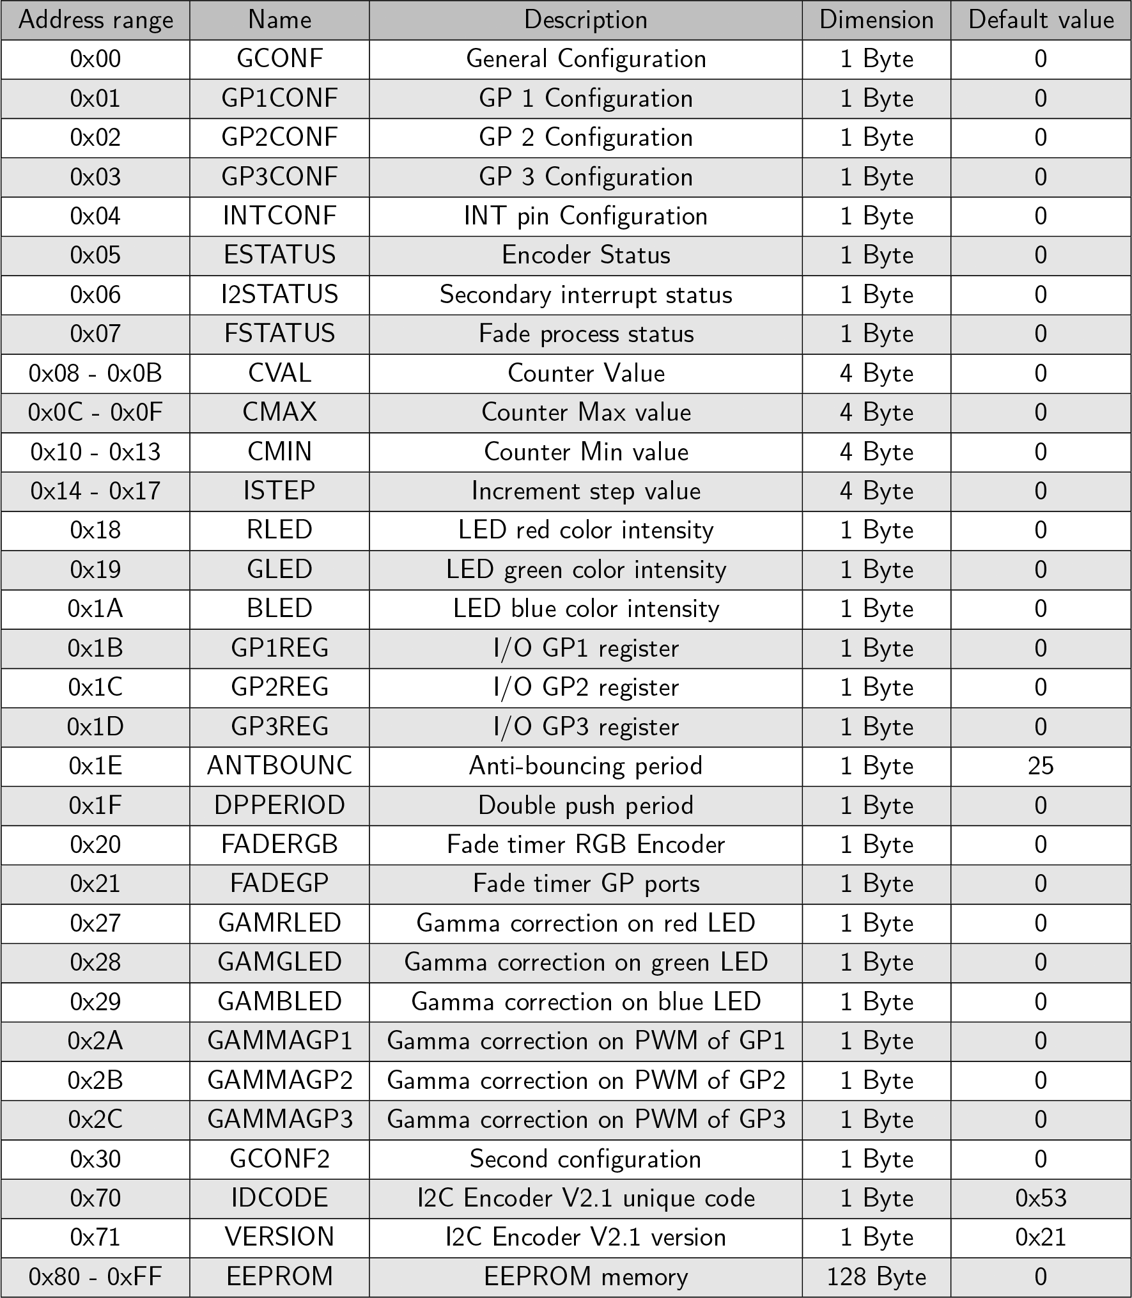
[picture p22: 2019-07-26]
I2Cmap.png

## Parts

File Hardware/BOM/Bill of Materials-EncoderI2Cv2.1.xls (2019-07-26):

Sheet: Bill of Materials-EncoderI2Cv2_
Description | Designator | Value | Footprint | MouserCode | PartNumber | Note
Capacitor | C1 | 4u7/16V | C0603 | 963-EMK107ABJ475MA-T | CC0603KRX5R7BB475
Capacitor | C2 | 100n/16V | C0402 | 603-CC402KRX5R8BB104 | GRM155R61C104KA88D
Capacitor | C3 | 47n/16V | C0402 | 81-GCM155R71E473KA5D | GCM155R71E473KA55D
Capacitor | C4 | 47n/16V | C0402 | 81-GCM155R71E473KA5D | GCM155R71E473KA55D
Ferrite Bead | L1 | 300R@100MHz | L0402 | 815-ACML-0402HC-301T | ACML-0402HC-301-T
Resistor | R1 | 4k7 | R0402 | 603-RC0402FR-074K7L | RC0402FR-074K7L
Resistor | R2 | 4k7 | R0402 | 603-RC0402FR-074K7L | RC0402FR-074K7L
Resistor | R3 | 42r2 | R0402 | 603-AC0402FR-0742R2L | AC0402FR-0742R2L
Resistor | R4 | 42r2 | R0402 | 603-AC0402FR-0742R2L | AC0402FR-0742R2L
Resistor | R5 | 107r | R0402 | 603-RC0402FR-07107RL | RC0402FR-07107RL
Resistor | R6 | 47r | R0402 | 603-RC0402FR-0747RL | RC0402FR-0747RL
Resistor | R7 | 47r | R0402 | 603-RC0402FR-0747RL | RC0402FR-0747RL
Resistor | R8 | 10k | R0402 | 603-RC0402FR-0710KL | RC0402FR-0710KL
Resistor | R9 | 10k | R0402 | 603-RC0402FR-0710KL | RC0402FR-0710KL
Resistor | R10 | 10k | R0402 | 603-RC0402FR-0710KL | RC0402FR-0710KL
Resistor | R11 | 10k | R0402 | 603-RC0402FR-0710KL | RC0402FR-0710KL
Resistor | R12 | 10k | R0402 | 603-RC0402FR-0710KL | RC0402FR-0710KL
8-bit Microcontrollers - MCU 8-BIT MCU 14KB Flash 1KB RAM, 256 EEPROM | U1 |  | MCHP-QFN-ML20_L | 579-PIC16F18345-I/GZ | PIC16F18345-I/GZ | I will ship to PCBWAY

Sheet: Foglio2
Description | Designator | Value | Footprint | MouserCode | PartNumber | PartNumber | Quantita | Board | Total
Capacitor | C1 | 4u7/16V | C0603 | 963-EMK107ABJ475MA-T | CC0603KRX5R7BB474 | EMK107ABJ475KA-T | 1 | 1200 | 1440
Capacitor | C2 | 100n/16V | C0402 | 603-CC402KRX5R8BB104 | GRM155R61C104KA88D | CC0402KRX7R7BB104 | 1 | 1200 | 1440
Capacitor | C3 | 47n/16V | C0402 | 81-GCM155R71E473KA5D | GCM155R71E473KA55D | CC0402KRX7R9BB473 | 2 | 1200 | 2880
Ferrite Bead | L1 | 300R@100MHz | L0402 | 815-ACML-0402HC-301T | ACML-0402HC-301-T | BLM15PX221SN1D | 1 | 1200 | 1440
Resistor | R1 | 4k7 | R0402 | 603-RC0402FR-074K7L | RC0402FR-074K7L | RC0402FR-074K7L | 2 | 1200 | 2880
Resistor | R3 | 42r2 | R0402 | 603-AC0402FR-0742R2L | AC0402FR-0742R2L | AC0402FR-0742R2L | 2 | 1200 | 2880
Resistor | R5 | 107r | R0402 | 603-RC0402FR-07107RL | RC0402FR-07107RL | AC0402FR-07107RL | 1 | 1200 | 1440
Resistor | R6 | 47r | R0402 | 603-RC0402FR-0747RL | RC0402FR-0747RL | RC0402FR-0747RL | 2 | 1200 | 2880
Resistor | R8 | 10k | R0402 | 603-RC0402FR-0710KL | RC0402FR-0710KL | RC0402FR-0710KL | 5 | 1200 | 7200

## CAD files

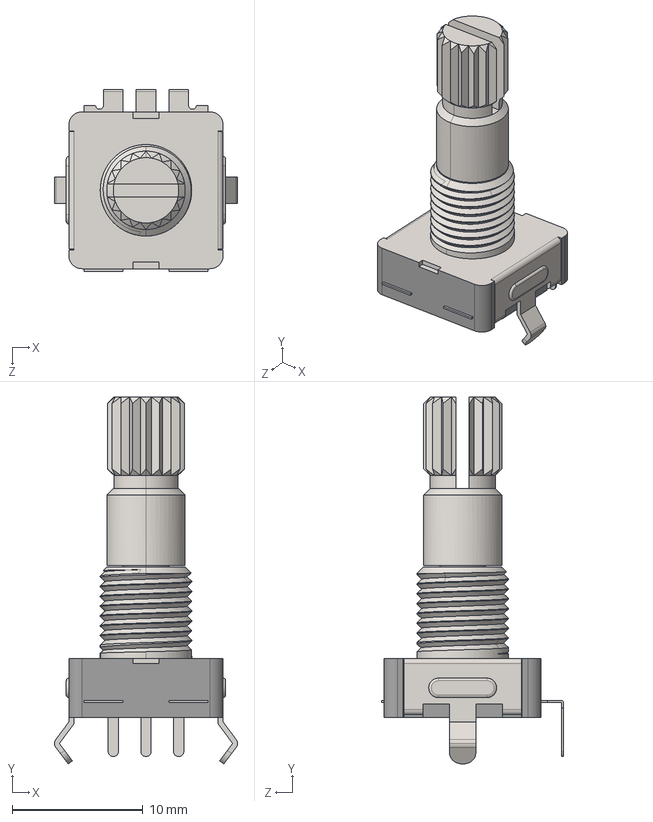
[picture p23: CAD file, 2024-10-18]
Hardware/STEP/EC11_20mm_Knurled.stp
14.0 x 28.1 x 13.9 mm

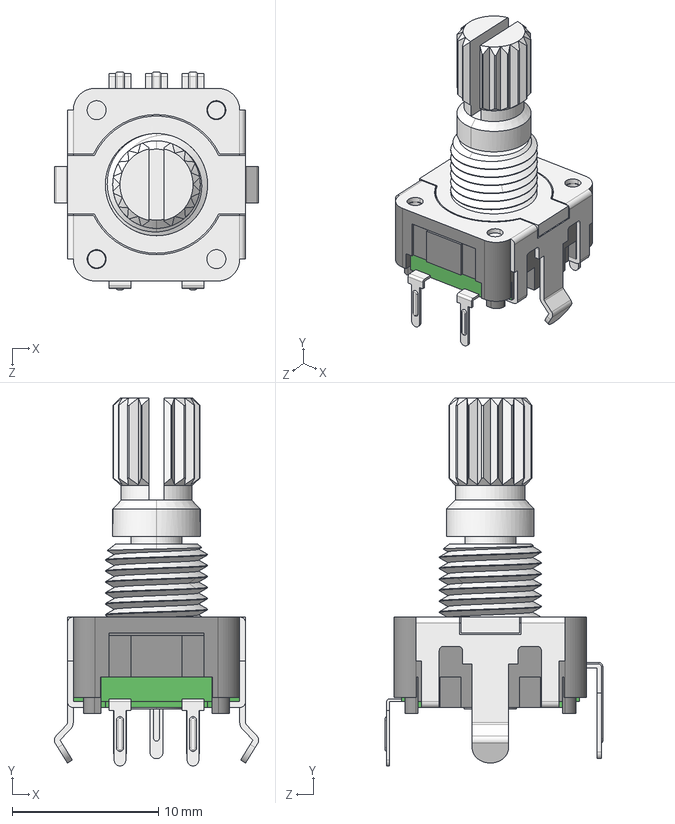
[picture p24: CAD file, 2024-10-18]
Hardware/STEP/EC11_15mm_Knurled.stp
14.0 x 25.2 x 14.9 mm

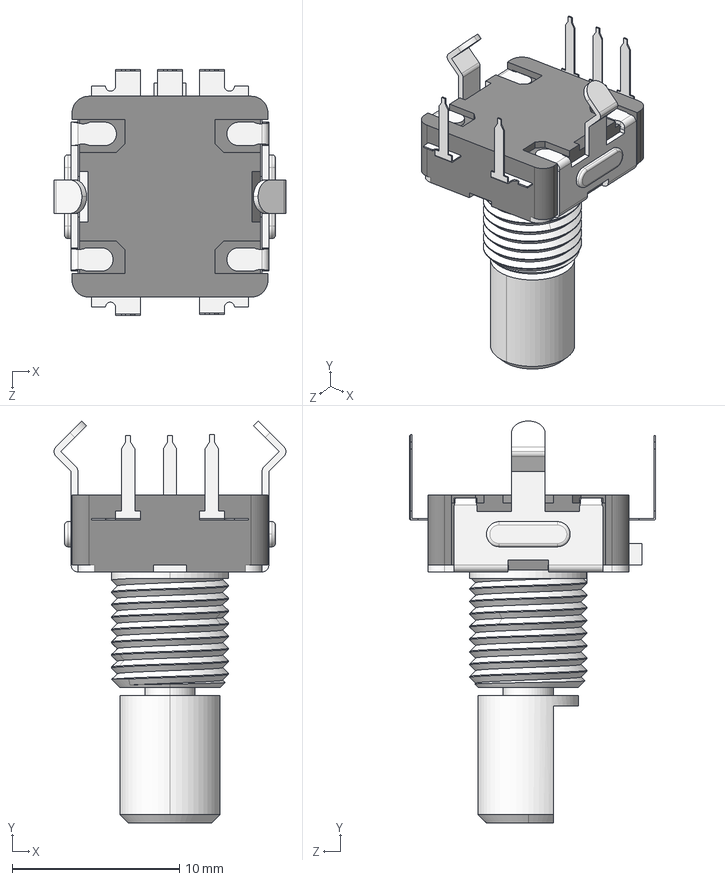
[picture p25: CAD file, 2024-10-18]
Hardware/STEP/EC11_15mm_Dshape.stp
13.8 x 24.0 x 14.7 mm

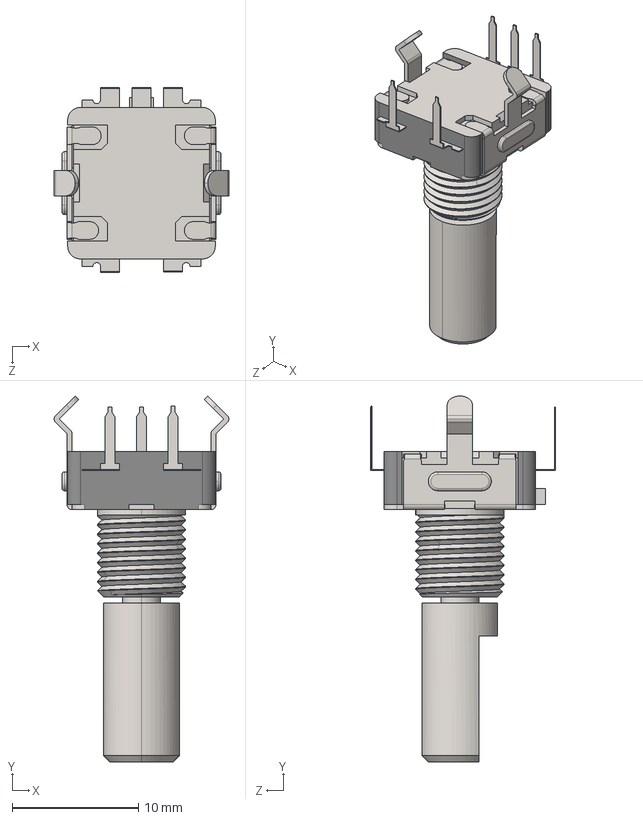
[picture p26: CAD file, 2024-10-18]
Hardware/STEP/EC11_20mm_Dshape.stp
13.8 x 29.0 x 14.7 mm

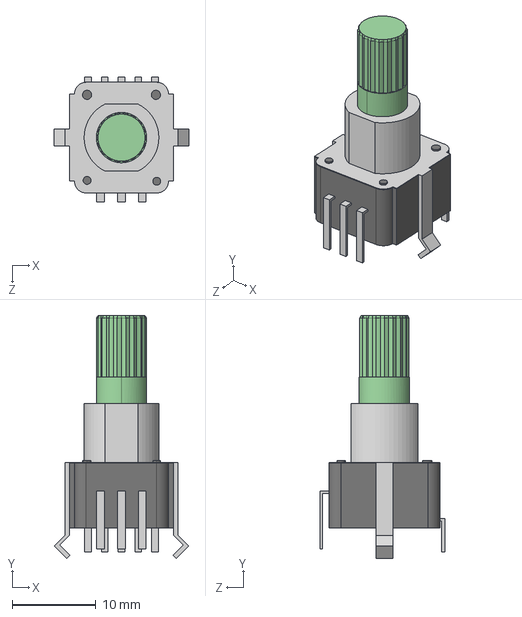
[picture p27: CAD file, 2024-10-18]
Hardware/STEP/RGB encoder.step
16.0 x 29.0 x 14.8 mm

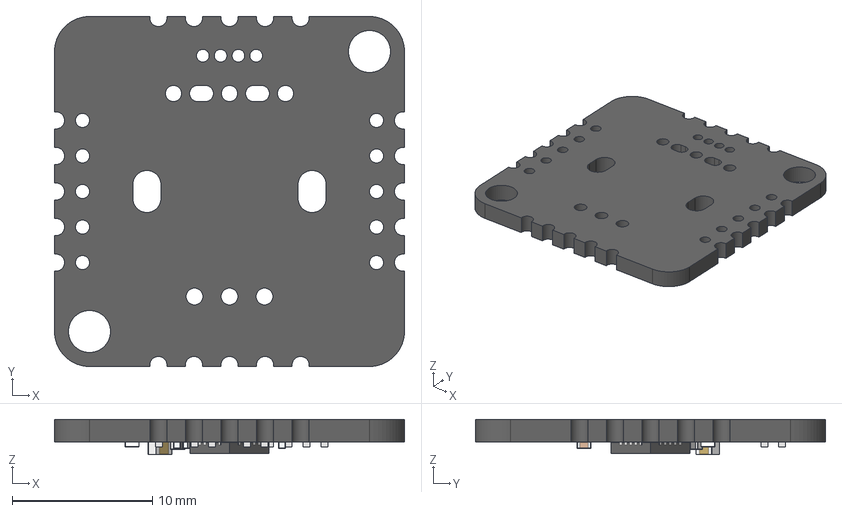
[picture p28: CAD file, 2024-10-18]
Hardware/STEP/EncoderI2Cv21.step
25.0 x 25.0 x 2.50 mm
User Library-R_0402 x 12
User Library-V0402HD_K_X_F6rper_1
User Library-V0402HD_Anschl_X_FCsse_1
User Library-QFN20_4x4x0_8
User Library-Capacitor 0402 x 3
User Library-CAPC1608X09

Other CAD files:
Hardware/AutoCAD PCB/EncoderI2Cv21_4Layer.DWG

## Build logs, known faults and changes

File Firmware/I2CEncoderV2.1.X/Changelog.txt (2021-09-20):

V2.1:

- Added gamma correction for all the PWM
- Added Version and ID code
- Added Clock strech option
- Added a delay after the double push
- the interrupt and register clear is immediatly the reading, and not after I2C stop
- ISTEP default now is 0

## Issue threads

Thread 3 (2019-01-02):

writeEEPROM requires some delay

hanyazou, 2019-01-02:
It seems that some delay() is needed after writeEEPROM() issued. Without this delay(), following read/write I2C register requests will fail and Arduino board and the I2C Encoder lose their sync.

```
for (int k = 0; k < 16; k++) {
  for (int j = 0; j < 16; j++) {
    Encoder.writeEEPROM(k*16+j, (k*16+j));
    delay(3);  // THIS IS NEEDED
  }
}
```

Is there any method to detect if the I2C Encoder is ready to receive next I2C request?

Fattoresaimon, 2019-01-02:
Hello,
Yes, you need to wait few ms when you write each byte on the EEPROM.
The PIC16F18344 datasheet says 4 - 5ms.
As far as i know from the other commands, there is no need to wait between commands.
Unfortunately there is no way to know when the I2C Encoder is ready to receive commands.

hanyazou, 2019-01-03:
I do not know about I2C in detail and I have never used PIC. But it is better to enable clock stretching, I think. It seems to be disabled SEN (Start Condition Enable/Stretch Enable bit) in I2C1_Initialize() in Firmware/I2CEncoderV2.X/mcc_generated_files/i2c1.c. (I don't know how to 'generate'd this...)
If clock stretching will be enabled properly, following I2C request might wait for completion of EEPROM access.

Fattoresaimon, 2019-01-03:
The clock stretching can be a solution, but can be a problem...
For example on the Raspberry Pi the clock stretching is buggy. Then in order to make the product more compatible i have decided to disable it
If you can grab a PIC programmer you can customize the FW. You only need to install the MPLAB X and the XC8 compiler. The peripheral driver are generated with the MCC tool inside of the MPLAB X

mrkale, 2019-01-03:
In general, clock stretching is driven by some slave, not by an MCU. Alas, the EEPROM chips belong to those slaves that do not provide clock stretching. So that we have to rely on the time delay by datasheets.

hanyazou, 2019-01-04:
I've installed MPLAB X and XC8 on to my Mac and enabled the SEN bit. I just changed SEN bit to 1 (enabled) in SSP1CON2 register. It worked well for Arduino Leonardo. The slave holds I2C clock for about 3ms to delay next I2C request from the master. I could issue EEPROM write requests from Arduino master  repeatedly without any delay().

I will try this with Raspberry Pi also when I have a time. If RaPi have any problem with this modification, how about that the clock stretching shall be controlled (enabled / disabled) from master by sending some configuration command so that Arduino master can issue EEPROM write request w/o delay()?

```
diff --git a/Firmware/I2CEncoderV2.X/mcc_generated_files/i2c1.c b/Firmware/I2CEncoderV2.X/mcc_generated_files/i2c1.c
index c1bf399..3b19913 100644
--- a/Firmware/I2CEncoderV2.X/mcc_generated_files/i2c1.c
+++ b/Firmware/I2CEncoderV2.X/mcc_generated_files/i2c1.c
@@ -79,7 +79,7 @@ void I2C1_Initialize(void) {
     // SSPEN enabled; WCOL no_collision; CKP disabled; SSPM 7 Bit Polling; SSPOV no_overflow;
     SSP1CON1 = 0x26;
     // ACKEN disabled; GCEN disabled; PEN disabled; ACKDT acknowledge; RSEN disabled; RCEN disabled; ACKSTAT received; SEN disabled;
-    SSP1CON2 = 0x00;
+    SSP1CON2 = 0x01; // SEN enabled
     // ACKTIM ackseq; SBCDE disabled; BOEN disabled; SCIE disabled; PCIE disabled; DHEN disabled; SDAHT 100ns; AHEN disabled;
     SSP1CON3 = 0x00;
     // SSP1MSK 127;
```

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

Fattoresaimon, 2019-01-04:
Hello, very good, thank you for the experiment!
Yes, I think is possible to add a configuration bit for enable/disable the clock stretch. But unfortunately the GCONF register is already full.
Change the registers map it will make incompatible the FW to the people that already have the boards. Since it's not a big bug I'm not intended to add now.
I will consider it to the next version!

hanyazou, 2019-01-04:
I tired my modification with My Raspberry Pi and raspbian. That did not allow the clock stretching even if it was only 5us. This means that I must disable the SEN bit for the RasPi. The micro seconds  order of interrupt latency can not handle by the firmware.

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

> the GCONF register is already full.

You can add new register for that. You have enough address space, don't you? If existing programs do not write new register and leave them as initial values, the encoder behaves as is was. So  there is no problem of compatibilities.

```
  /** Internal i2C address definition **/
  typedef enum {
      REG_GCONF = 0x00,
      REG_GP1CONF = 0x01,
          :
      REG_FADEGP = 0x21,
+     REG_GCONF2 = 0x22,
      REG_EEPROMS = 0x80,
};
```

> Since it's not a big bug I'm not intended to add now.

Yeah. It's your choice.

Fattoresaimon, 2019-01-04:
Hello, Thank you again for the experiment!

> You can add new register for that. You have enough address space, don't you? If existing programs do not write new register and leave them as initial values, the encoder behaves as is was. So there is no problem of compatibilities.

Yes, it's not a problem of space! i just don't want to do some mess with same boards but different FW version.
When i will run a new production i can change the marking on the boards from V2.0 to V2.1 and include this feature in the FW.

hanyazou, 2019-01-04:
I understand. I recommend you to add ID register and revision registers, from which I can read some fixed values.

Closed 2019-01-04.

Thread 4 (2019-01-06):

Dead time after resetting

therealprof, 2019-01-06:
I'm writing a driver in Rust for the I2CEncoderV2 and noticed that my initialisation sequence does not work because as a good citizen I would like to do a RESET followed by proper initialisation but when I set the reset bit the following I2C interaction automatically receives a NACK.

Fattoresaimon, 2019-01-06:
Hello,
I just did some tests.
I have found that the board requires at least 400uS for RESET.
Try to put a 400uS after issuing the RESET command.
Sorry i never had measured it before, i will add in the datasheet.
Thank you.

therealprof, 2019-01-06:
Hm, no idea how to achieve that in a generic driver. Can I keep polling until it comes back?

Fattoresaimon, 2019-01-06:
You can try, but i'm not sure that is the way.
Remember that the I2C Encoder V2 is based on a MCU and not on FPGA or CPLD.
So it's a bit slower on some operations.

therealprof, 2019-01-06:
Yeah, but I2C is not super fast anyway. I'd totally expect that any MCU can handle the timing by setting I2C up early and stretching the clock until it is ready to handle additional data.

Fattoresaimon, 2019-01-06:
Clock stretch is not enabled, check the other issue https://github.com/Fattoresaimon/I2CEncoderV2/issues/3

Fattoresaimon, 2019-01-06:
The RESET command is a full reset of the MCU.
So after that the MCU will restart from the beginning: initialize the peripherals, the variables, ecc..

therealprof, 2019-01-06:
Sure. But maybe if you want to have a proper I2C slave you should try to prioritise the functionality required for an I2C slave first?

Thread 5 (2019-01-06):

Cannot use RGB values with RGB encoders

therealprof, 2019-01-06:
First I'm enabling the RGB LED by setting the ETYPE bit and then I'm calling a function which tries to do a write on `RLED`, then `GLED` then `BLED` in succession but depending on the combination of colours and the previous value this yields completely random results; single colours mostly work, combinations of RGB deliver completely random results.

Reading back the `RLED`, `GLED` and `BLED` registers shows the correct colours I've set before. Fading is disabled.

Fattoresaimon, 2019-01-06:
Hello,
Can you please post the code with a combination of colors?
Can you please tell me which board you are using?
I've never encountered this problem, so it's look strange.

Fattoresaimon, 2019-01-06:
I have tried this sequence:

Encoder.begin(INT_DATA | WRAP_ENABLE | DIRE_LEFT | IPUP_ENABLE | RMOD_X1 | RGB_ENCODER);
Encoder.writeLEDR(0xff);
Encoder.writeLEDG(0xff);
Encoder.writeLEDB(0xff);

And i get the LED white, that is correct.
I'm thinking that you are sending the commands to much fast and this causes some misbehavior.
I'm using an ESP8266 and between the commands there are 20uS delay,

therealprof, 2019-01-06:
Uhm, too fast? The weird thing is that the values read back perfectly fine so they're registered by the MCU, just not properly applied.

Fattoresaimon, 2019-01-06:
Try to add a delay between the commands and tell me if it's solve.
And also try to send the commands with the I2C auto increment like the following:

1. Write I2C address of your board
2. Write the  REG_RLED address ->   0x18
3. Write the RLED data -> 0xFF
4. Write the GLED data -> 0xFF
5. Write the BLED data -> 0xFF

therealprof, 2019-01-06:
> Try to add a delay between the commands and tell me if it's solve.

I can't. This is a generic driver, could be executed on anything from a small MCU over a RaspPi over to a Windows server connected via a FTDI chip. I can only use defined features of the I2C bus which is write and write followed by a read.

> And also try to send the commands with the I2C auto increment like the following:

That makes it even worse. Reminds me, this should also be mentioned in the documentation; I wasn't sure if the registers are auto-incrementing since it worked even worse than before when I tried.

But I figured out a way to make it work: Reduce the I2C clock to 10kHz and write some dummy value (e.g. 0, 0, 0) to the RGB LED registers first...

Something is really off here...

Fattoresaimon, 2019-01-07:
Hi,
I have just tried with a NUCLEO-F446RE, but since i don't know how to program in Rust, i have made a simple example in C.
I have used the STM32CubeMX to generate the peripheral code and i have made a simple program in C using eclipse and the System Workbench plugin.
I have set the I2C at 400kHz in fast mode.
Here is the code:
```
  uint8_t buffer[5];
  buffer[0]=0;
  buffer[1]=0b00111111;
  HAL_I2C_Master_Transmit_IT(&hi2c1,0xC2,buffer,2);
  HAL_Delay(2); // Necessary in order to complete the previews writing
  buffer[0]=0x18;
  buffer[1]=0xFF;
  buffer[2]=0xFF;
  buffer[3]=0xFF;
  HAL_I2C_Master_Transmit_IT(&hi2c1,0xC2,buffer,4);
```

In my test, the RGB LED correctly turns on with white color, i did't have any issue.
Here  you can see the I2C transaction, there isn't any delay between the packet, and the RGB LED works correctly.

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

I don't know what was happening to you, did you tried with a different board?

Fattoresaimon, 2019-01-23:
Any update?
Did you have some code that i can try?

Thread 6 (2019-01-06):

RMOD not documented

therealprof, 2019-01-06:
There's a RMOD bit in the general configuration, but what does `Reading Mode` `X2 mode` and `X1 mode` actually mean?

Fattoresaimon, 2019-01-06:
Hello,
They are two types of encoding in the encoders.
Just google a bit: https://www.motioncontroltips.com/faq-what-do-x1-x2-and-x4-position-encoding-mean-for-incremental-encoders/

therealprof, 2019-01-06:
@Fattoresaimon So I guess the documentation should mention then that X2 mode doubles the resolution?

Fattoresaimon, 2019-01-06:
Yes!
I made this in order to be compatible with different type of encoders.

therealprof, 2019-01-06:
That is great but useless without the knowledge what it is and which setting is compatible with which encoder, (i.e. what is correct setting for the RGB led encoders and non-RGB encoders?)

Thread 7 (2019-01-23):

Make the library event driven with function callbacks

codebeat-nl, 2019-01-23:
Because it is now a more advanced product and you can use more than one, make it event driven.

for example:
--------------------

#define MAX_ENCODERS 5
#define ENC_ID_CHANNEL1 0x30
#define ENC_ID_CHANNEL2 0x31
#define ENC_ID_CHANNEL3 0x32
#define ENC_ID_CHANNEL4 0x33
#define ENC_ID_CHANNEL5 0x34

i2cEncoderLibV2* encoders[MAX_ENCODERS];

// Just an example event handler:
void myRotaryEncoderChangeEvent( EncoderClass opSender, int8_t iValue )
{
  Serial.print( opSender->addres );
  Serial.print( "has been changed to " );
  Serial.println( iValue );

 if( opSender->addres == ENC_ID_CHANNEL3 )
 {
   // do something nice
 }
}

void setup()
{
  uint8_t i = MAX_ENCODERS;
  while( i-- )
  {
    encoders[i]= new i2cEncoderLibV2(ENC_ID_CHANNEL1+i);
    encoders[i]->onEncoderChange = myRotaryEncoderChangeEvent;
  }
}

void loop()
{
  uint8_t i = MAX_ENCODERS;
  while( i-- )
  {
     // if something has been changed, it triggers an event if assigned
     encoders[i]->update();
  }
}

--------------------

Hopefully you understand the idea and why this would be nice. It makes it easier to handle more objects at once and avoids a if then else mess (structorize the code).

Fattoresaimon, 2019-01-23:
Hi,
Can be a nice idea,
When i will have more free time, i would definitely try.
Thank you
Simone

Fattoresaimon, 2019-03-02:
Hi,
I have followed your suggestion.
Here the result: https://github.com/Fattoresaimon/ArduinoDuPPaLib

codebeat-nl, 2019-03-05:
Hi,
Nice, great, however, why you call the event and handlers at some points interrupts? In your code of `attachInterrupt`() you assign a function to an event array (it is called Events). On update, you poll the encoder and fire events if assigned. Why is it not called `attachEvent`() ( and `detachEvent`() )?  An interrupt is really something else, this is confusing.

Another thing is the amount of events and the type of events. For example ENCODER_INCREMENT and  ENCODER_DECREMENT could be one event type, for example onChange. Now you have to specify two eventhandlers for practically the same - the encoder 'wiper' changed.  This could be something like onChange( obj, direction ), for example negative (steps) when turned left and positive (steps) when turned right.

Also the assignment of events could be more user friendly and less prone to errors (for example using the wrong constants, there is also no range check in the attachInterrupt function!). For example each encoder provides these simple event properties:
```
- onChange
- onButtonClick
- onButtonDown / onButtonPress
- onButtonUp / onButtonRelease
- onButtonDoubleClick
- onButtonHold
- onMinMaxRange()   // Do not know why you want to know this.

```
So you can do, to assign an event handler:
```
encoder.onChange = evMyEncoderChange;
encoder.onClick = evMyEncoderClick;
```

This naming convention is more clear, nicer, easier and also very similar to other languages.

Fattoresaimon, 2019-03-05:
Thank you a lot for the suggestion!

> there is also no range check in the attachInterrupt function!

Yeah i have noticed that huge mistake, i will fix.
I think i will follow (again 😅) your suggestions!

Fattoresaimon, 2019-03-13:
Hello,
I have made an update following your suggestions.
Thank you so much!

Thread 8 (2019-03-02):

GCONF.DIRE bit doesn't to work.

deadsy, 2019-03-02:
I'm using the kickstarter RGB encoder.

Here are my initial config values:

  {REI2C_GCONF, REI2C_GCONF_ETYPE},
  {REI2C_CVAL, 0}, // Counter Value
  {REI2C_CMAX, 32}, // Counter Max value
  {REI2C_CMIN, -32}, // Counter Min value
  {REI2C_ISTEP, 1}, // Increment step value

With GCONF = 0x20 (DIRE=0) turning it clockwise decrements the cval.
With GCONF = 0x24 (DIRE=1) turning it clockwise *still* decrements the cval.

I would expect that:
DIRE=0 a clockwise turn would increment cval.
DIRE=1 a clockwise turn would decrement cval.

Fattoresaimon, 2019-03-02:
Hello,

The DIRE functionality works, just re-tested to make sure.
I have tested with Arduino and with the following configuration:

Encoder.begin(INT_DATA | WRAP_DISABLE | DIRE_RIGHT | IPUP_ENABLE | RMOD_X1 | RGB_ENCODER);
Rotate right CVAL _increment_

Encoder.begin(INT_DATA | WRAP_DISABLE | DIRE_LEFT | IPUP_ENABLE | RMOD_X1 | RGB_ENCODER);
Rotate right CVAL _decrement_

deadsy, 2019-03-03:
Hmm... Started working.
No code changes, just a power cycle.
Don't you hate it when that happens....

Closed 2019-03-03.

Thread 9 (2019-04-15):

I2c scan problem using micropython

rudydevolder, 2019-04-15:
I am still figuring out what is happening.
I got the encoder working on Arduino Uno 5v, and also on A CYPRESS PSOC processor where I am planning to use it. But trying a simple I2c.scan I can't discover the device on a micropython pyboard 3v.
The strangest is though I put 2 I2c devices in series. The encoder and a pressure sensor. With exactly the same configuration and termination I tried on all 3 processors and having a different outcome. Scanning on micropython reveals only the pressure sensor on the bus, and on the PSoC I can discover only the encoder. When I connect only the encoder with termination I also can't discover on micropython. No idea what is going on here, anybody?

Fattoresaimon, 2019-04-15:
Hello,
This type of i2c scanning program doesn't work well with the I2C Encoder V2.
It is written in the datasheet, chapter Issue.
Try to communicate directly instead!

Simone

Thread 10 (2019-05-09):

[bug(?)] Triple pressing acts as a double push instantly followed by a single press...

IAmOrion, 2019-05-09:
Triple pressing acts as a double push instantly followed by a single press.  Realistically this should still fall under control of the debouncing methods, given that's it's highly unlikely someone wants to action a double press and then a single press like that.  Ideally, it should not register the 3rd press... so in other words, it should action the double press method and ignore the 3rd press (within the debounce period)

cconde, 2019-07-28:
Might be a "multiple press" event and a register to read the number of presses.
That would fit all situations, the proposed one by IAmOrion and perhaps somebody coding an Easter egg after ten presses :)

Fattoresaimon, 2019-07-28:
Hello,
In the version V2.1 i have fixed this issue.
After detecting a double push there is window of the same amount of the DPPERIOD where the button is not detected.

IAmOrion, 2019-07-28:
> Hello,
> In the version V2.1 i have fixed this issue.
> After detecting a double push there is window of the same amount of the DPPERIOD where the button is not detected.

Do I have to upload a new firmware to the I2C encoder somehow? Or do I only need to update the library? I have the v2.0 board I believe

Fattoresaimon, 2019-07-28:
You have to update the FW on the board. The FW is compatible.
You need a PIC programmer, like the PICKit 3.
In the datasheet it's written how to connect: https://github.com/Fattoresaimon/I2CEncoderV2.1/blob/master/EncoderI2CV2.1_v1.0.pdf

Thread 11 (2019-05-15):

X4 operation

wyealex, 2019-05-15:
Congratulations on an excellent device, and thank you for porting it to Python for RPi!
I don't understand why there is not full quadrature access available - I have 24 pulses on my encoder, therefore I should be able to identify 96 positions in a revolution. I am keen to use very basic rotary encoders for very basic positional sensing and if I can get full X4 quadrature then I get twice the X2 resolution for free!

Fattoresaimon, 2019-05-24:
Hello,
The X4 is not available because for reading the encoder i'm using the CLC feature of the PIC micro.
Page 14 of this [document](http://ww1.microchip.com/downloads/en/DeviceDoc/41631B.pdf).

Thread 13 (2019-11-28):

std encoder: pushbutton not working unless GCONF register is written to

az143, 2019-11-28:
i've got two fresh v2.1 boards, wired up with a plain std. encoder with switch. my multimeter shows the switch conducts exactly when pushed. the boards are unconfigured, ie. using the
default values for all config bits, which according to the datasheet should mean 'std encoder'.
symptom:  the i2cencoder doesn't report anything in the button-related bits of ESTATUS when or
after i press the button.

tldr: looks as if STD_EncoderMode() isn't called unless GCONF is written.
workaround: write to the GCONF register even if it's just the same 0x0 as the defaults.
proper fix: i think that the function FirstConfig needs to be called sometime during startup, not just as part of RegisterWrite.

minor problematic aspects: the datasheet doesn't describe the pinout of the 5 pins below the gp1/2 pins (which are listed in figure 1.16). the hardware/schematic sheet also doesn't describe how a std encoder's switch is wired up. would be great if that was amended in a future revision.

i've beeped the board traces and figured out that way that the 5 pins correspond
(top near 'v2.1' to bottom) to PWM_LR_GP3, PWM_LG_SW, SW_RGB, PWM_LB_SWC and VCC.
the two switch terminals are connected to PWM_LG_SW and PWM_LB_SWC.

digging through the code in Encoder.c and GPports.c i see that in std encoder mode
PWM_LG_SW should be pulled up weakly, and PWM_LB_SWC is pulled low. PWM_LG_SW is then read as inverted input.

the crux: if i just power up the chip and start using it then the multimeter tells me that PWM_LG_SW is floating. only after i write to GCONF the pull up is pulling up and things start working.

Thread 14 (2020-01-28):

Question: What are the CLCs doing to read the rotary encoder?

jazzychad, 2020-01-28:
Hi! I am very interested in this project because I am learning PIC programming and also wanting to use rotary encoders in a project. I see in your MPLAB project that you have configured the two CLC peripherals to use "2-input D flip-flop with R" configuration and reading the RA and RB pins (RC0 and RC1). Could you please explain what logic is going on here that makes this work? I am only familiar with the rotary encoders which use 4 "steps" between each detent (is this what you are using?) and am curious how the CLCs correctly interpret this?

Thanks for any info!

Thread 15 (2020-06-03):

Board as an KiCad symbol

Renha, 2020-06-03:
Hello! I'm designing some board in KiCad and going to use i2c Encoder there. It would be great to have it as a symbol I could insert to my design to get correct pin placement, names, etc., and footprint, all of that for inserting the i2c Encoder board into mine.

Even better is to have different connection variants in same library - for soldering, for inserting, with GP ports also being soldered, or without, in single KiCad library.

Thank you!

Soundpauli, 2024-12-28:
Hey @Renha or @Fattoresaimon i'm looking for a footprint as well - did someone already made one?

Renha, 2024-12-28:
Not me, I've ended up integrating the encoder more deeply into the project and handle it with the main MCU

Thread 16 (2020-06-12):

Mechanical drawing

Hugh3226, 2020-06-12:
Please could we have a better mechanical drawing showing the X-Y dimensions of:
1. The fixing holes
2. Pin1 of every connector.
Regards

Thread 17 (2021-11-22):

Acceleration

fixus971, 2021-11-22:
Hi. It would be very useful for me to accelerate the CVAL steps when the encoder is rotated quickly to manage large values without losing precision.
I've used this feature before through traditional rotary encoder libraries and was fine with it.
Is there any hope that you will implement it or is it better to manage externally by activating RelMode?
Thank you, -Fede.

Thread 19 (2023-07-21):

Connection list to I2C device: OSError: [Errno 121] Remote I/O error

maltejahn, 2023-07-21:
Hi,

i bought version 2.1 and i am trying to run it on a raspberry 4 later in combination with the led ring (both connected to the RPi).
I2C is set to 100kHz in the config.txt

Now it occurs after some random turns of the encoder that the,  i think, mc of the encoder crashes because  `i2cdetect -y 1` still sees my LED ring, but the encoder is gone after the error:

```
Encoder min!
sum: 1289
Traceback (most recent call last):
  File "/home/pi/i2cring/./drehencoder.py", line 58, in Encoder_INT
    encoder.updateStatus()
  File "/home/pi/i2cring/i2cEncoderLibV2.py", line 192, in updateStatus
    self.eventCaller (self.onChange)
  File "/home/pi/i2cring/i2cEncoderLibV2.py", line 167, in eventCaller
    event()
  File "/home/pi/i2cring/./drehencoder.py", line 19, in EncoderChange
    temp = encoder.readCounter32()
  File "/home/pi/i2cring/i2cEncoderLibV2.py", line 298, in readCounter32
    return (self.readEncoder32(REG_CVALB4))
  File "/home/pi/i2cring/i2cEncoderLibV2.py", line 624, in readEncoder32
    data = self.i2cbus.read_i2c_block_data(self.i2cadd, add, 4)
  File "/home/pi/.local/lib/python3.9/site-packages/smbus2/smbus2.py", line 617, in read_i2c_block_data
    ioctl(self.fd, I2C_SMBUS, msg)
OSError: [Errno 121] Remote I/O error
Traceback (most recent call last):
  File "/home/pi/i2cring/./drehencoder.py", line 58, in Encoder_INT
    encoder.updateStatus()
  File "/home/pi/i2cring/i2cEncoderLibV2.py", line 171, in updateStatus
    self.stat = self.readEncoder8(REG_ESTATUS)
  File "/home/pi/i2cring/i2cEncoderLibV2.py", line 610, in readEncoder8
    data[0] = self.i2cbus.read_byte_data(self.i2cadd, add)
  File "/home/pi/.local/lib/python3.9/site-packages/smbus2/smbus2.py", line 433, in read_byte_data
    ioctl(self.fd, I2C_SMBUS, msg)
OSError: [Errno 121] Remote I/O error
^CTraceback (most recent call last):
  File "/home/pi/i2cring/./drehencoder.py", line 114, in <module>
    pass
KeyboardInterrupt
```
After this error i have to disconnect the Encoder/LED Ring. It doesnt help to just rerun the script.

I tried it multiple times to see if there is a kinf of pattern. But it crashes after 700.... 3000 clicks. Slow or fast does also seem to do the same.
Any ideas?

```
import smbus2
import RPi.GPIO as GPIO
from time import sleep
import i2cEncoderLibV2
#import ledring

oldEncValue = 0
sum=0

minLedLoudness = 34
maxLedLoudness = 0

def EncoderChange():
    encoder.writeLEDG(100)
    global sum
    sum = sum +1
    print('sum: %d' % (sum))
    temp = encoder.readCounter32()
    oldEncValue = temp
    print ('Changed: %d' % (temp))

    #ledring.LEDRing_Set_RGB(temp,0x12345)

    #ledring.LEDRing_Set_RGB(temp+1,0)
    #ledring.LEDRing_Set_RGB(temp-1,0)
#    if temp >= minLedLoudness:
#        temp = minLedLoudness
#    ledring.LEDRing_loudness(temp,0x50)
    #encoder.writeLEDG(0)

def EncoderPush():
    #encoder.writeLEDB(100)
    print ('Encoder Pushed!')
    #encoder.writeLEDB(0)

def EncoderDoublePush():
    #encoder.writeLEDB(100)
    #encoder.writeLEDG(100)
    print ('Encoder Double Push!')
    #encoder.writeLEDB(0)
    #encoder.writeLEDG(0)

def EncoderMax():
    #encoder.writeLEDR(100)
    print ('Encoder max!')
    #encoder.writeLEDR(0)

def EncoderMin():
    #encoder.writeLEDR(100)
    print ('Encoder min!')
    #encoder.writeLEDR(0)

def Encoder_INT(self):
    encoder.updateStatus()

GPIO.setmode(GPIO.BCM)
bus = smbus2.SMBus(1)
INT_pin = 4
GPIO.setup(INT_pin, GPIO.IN, pull_up_down=GPIO.PUD_UP)

encoder = i2cEncoderLibV2.i2cEncoderLibV2(bus, 0x50)
#ledring= ledring.ledRing(bus, 0x28)
#ledring.setup()

#ledring.LEDRing_ClearAll()
#ledring.LEDRing_Set_RGB(1,0x12345)
#ledring.LEDRing_Set_BLUE(34,0x60)
#ledring.LEDRing_Set_BLUE(47,0x60)

encconfig = (i2cEncoderLibV2.INT_DATA | i2cEncoderLibV2.WRAP_DISABLE | i2cEncoderLibV2.DIRE_RIGHT | i2cEncoderLibV2.IPUP_ENABLE | i2cEncoderLibV2.RMOD_X1 | i2cEncoderLibV2.RGB_ENCODER)
encoder.begin(encconfig)

encoder.writeCounter(0)
encoder.writeMax(47)
encoder.writeMin(0)
encoder.writeStep(1)
encoder.writeAntibouncingPeriod(8)
encoder.writeDoublePushPeriod(50)
encoder.writeGammaRLED(i2cEncoderLibV2.GAMMA_2)
encoder.writeGammaGLED(i2cEncoderLibV2.GAMMA_2)
encoder.writeGammaBLED(i2cEncoderLibV2.GAMMA_2)

encoder.onChange = EncoderChange
encoder.onButtonPush = EncoderPush
encoder.onButtonDoublePush = EncoderDoublePush
encoder.onMax = EncoderMax
encoder.onMin = EncoderMin

encoder.autoconfigInterrupt()
print ('Board ID code: 0x%X' % (encoder.readIDCode()))
print ('Board Version: 0x%X' % (encoder.readVersion()))

encoder.writeRGBCode(0x640000)
sleep(0.3)
encoder.writeRGBCode(0x006400)
sleep(0.3)
encoder.writeRGBCode(0x000064)
sleep(0.3)
encoder.writeRGBCode(0x00)

GPIO.add_event_detect(INT_pin, GPIO.FALLING, callback=Encoder_INT, bouncetime=10)

while True:
  #  if GPIO.input(INT_pin) == False: #
   #     Encoder_INT() #
    pass

```

maltejahn, 2023-07-21:
Hi,

also another problem is the 100 percent usage when using the example. Probably due to this:

```
while True:
  #  if GPIO.input(INT_pin) == False: #
   #     Encoder_INT() #
    time.sleep(0.00001) <- added by me
    pass
```
I added some sleep (so about 20 pervent load by python), also played aroung with the value.

The problem, that the mc isnt responding anymore, remains. Is the buffer of the PIC mc too small? It seems that it crash mor often when rotating fast. But sometimes it also crashes when doing slot rotation

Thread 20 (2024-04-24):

Encoder not responding after removing JSD connector

nicolasvair, 2024-04-24:
Hi,

I bought 4 encoder for my project. They came with JSD XH two side so I could plug everything and test my idea.
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

Everything was working fine, the lib is great ! So I removed the JSD connector because I needed something thinner for my design (it's a wearable).

Now one of the encoder doesnt work. I changed the address without luck, tried connectors from the 4 sides and still nothing.

With the others 3, it seems I lost the INTERRUPT PIN on one side on 2 of them. One is as new.

Any idea how I could check what has been broken and how to solve it ?

From the outside it seems perfect, no sign of damage, and I don't have any undesired continuity between the pins (like between SDA and SCL, between + and -).

Thank you !

Fattoresaimon, 2024-04-24:
Hello,

Maybe some trace get damage during the removing?

Try to check if there is continuity among the connector of the 4 side.
I mean check if there is continuity among all the SCL, SDA, INT and power pin of the 4 side.
and also double check the short.
Also check if there are the pull-up resistors on the I2C bus.

Thank you,
Simone

nicolasvair, 2024-04-24:
Hi

thank you for your quick reply !

I have continuity on 4 sides except for the INTERRUPT on one side.

So I soldered on one of the other side (it is the last in chain because the other 3 are working).

I tried with and without pull-up but it didn’t help.

Do you think it could be because one INTERRUPT IS LOST ?

Is it possible to use it without interrupt ?
and could I tweak sth using the available GPIO ?

Thank you

nicolasvair, 2024-04-24:
Ok I finally found it. SDL was broken. I connected a wire straight to micro controller and got it back..
Not sure for how long tho

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

My first precision soldering 🥹
With iphone as binocular glass and giant soldering iron 😂

Fattoresaimon, 2024-04-24:
Hello,

Oh nice job! ;)

Thank you,
Simone

Closed 2024-04-25.

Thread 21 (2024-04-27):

Store multiple values in registers ?

nicolasvair, 2024-04-27:
Hi,

I have a question on how the encoder works. I'm doing a bluetooth midi controller and plan to have several pages of controls.

I read in the docs that the encoder have 4 adress bytes. Does it means that I can store 4 values ? Or are you using the 4 of them for one value ?

Fattoresaimon, 2024-04-27:
Hello,
I think you are referring to the CVAL, CMAX, CMIN and ISTEP register.
They are 32bit register and they store 1 value. They use 4 register because a 32bit number is composed of 4 byte.

Thank you!

nicolasvair, 2024-04-27:
Allright, that what I thought.

I have then another related question. What would be the benefit of storing the value in the register rather than in an arduino variable ?

Thank you

Fattoresaimon, 2024-04-27:
The I2C encoder keep counting when you rotate the encoder even if you don't read trough the I2C command. This can happens when your arduino is busy with other tasks.
So in this way you will not miss the steps

nicolasvair, 2024-04-28:
Oh ok. That makes sense.

Thank you ! Those controllers and led rings are really great and well made.

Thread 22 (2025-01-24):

Interrupt issue in MicroPython when using multiple encoders

cameronprince, 2025-01-24:
Hello,

I'd like to use the i2cencoders for a project that is coded in MicroPython. I wasn't able to find an existing library, so I ported the Python library to MicroPython here: https://github.com/cameronprince/i2cEncoderLibV2

Everything has been working well with a single i2cencoder, but once I added additional i2cencoders to the bus, the interrupt pin sticks low on the first interaction with any i2cencoder. This causes the interrupt handler to fire continuously until the ESP-WROOM-32 grinds to a halt.

My initial order from you was for five of the i2cencoders. I soldered four together using the castellations and have one stand alone. The stand-alone i2cencoder has the same address (0x50) as the first i2cencoder in the group of four. Both of these have the i2c bus pull-up pads soldered.

When testing the four i2cencoders together, I initially had a single set of callbacks that were being shared with all four i2cencoders. I thought this might have something to do with the problem, so I switched to separate callbacks. This made no difference. I also tried initializing each of the four individually, but this also made no difference. Additional delays were tried in various places, as well. All four have the same problem, but the stand-alone continues to work fine by itself.

Here is my test code:

```
import time
import struct
from machine import Pin, I2C
import i2cEncoderLibV2

I2C_BUS = 1
I2C_SCL_PIN = 33
I2C_SDA_PIN = 32
INTERRUPT_PIN = 34
# ENCODER_ADDRESSES = [0x50]
ENCODER_ADDRESSES = [0x50, 0x30, 0x60, 0x44]

# Setup the Interrupt Pin from the encoders.
INT_pin = Pin(INTERRUPT_PIN, Pin.IN)

# Initialize the I2C bus.
i2c = I2C(I2C_BUS, scl=Pin(I2C_SCL_PIN), sda=Pin(I2C_SDA_PIN))

# Initialize encoders
encoder1 = i2cEncoderLibV2.i2cEncoderLibV2(i2c, ENCODER_ADDRESSES[0])
encoder2 = i2cEncoderLibV2.i2cEncoderLibV2(i2c, ENCODER_ADDRESSES[1])
encoder3 = i2cEncoderLibV2.i2cEncoderLibV2(i2c, ENCODER_ADDRESSES[2])
encoder4 = i2cEncoderLibV2.i2cEncoderLibV2(i2c, ENCODER_ADDRESSES[3])

# Callback functions for Encoder 1
def EncoderChange1():
    encoder1.writeLEDG(100)
    valBytes = struct.unpack('>i', encoder1.readCounter32())
    print('Encoder 1 Changed: %d' % valBytes[0])
    encoder1.writeLEDG(0)

def EncoderPush1():
    encoder1.writeLEDB(100)
    print('Encoder 1 Pushed!')
    encoder1.writeLEDB(0)

# Callback functions for Encoder 2
def EncoderChange2():
    encoder2.writeLEDG(100)
    valBytes = struct.unpack('>i', encoder2.readCounter32())
    print('Encoder 2 Changed: %d' % valBytes[0])
    encoder2.writeLEDG(0)

def EncoderPush2():
    encoder2.writeLEDB(100)
    print('Encoder 2 Pushed!')
    encoder2.writeLEDB(0)

# Callback functions for Encoder 3
def EncoderChange3():
    encoder3.writeLEDG(100)
    valBytes = struct.unpack('>i', encoder3.readCounter32())
    print('Encoder 3 Changed: %d' % valBytes[0])
    encoder3.writeLEDG(0)

def EncoderPush3():
    encoder3.writeLEDB(100)
    print('Encoder 3 Pushed!')
    encoder3.writeLEDB(0)

# Callback functions for Encoder 4
def EncoderChange4():
    encoder4.writeLEDG(100)
    valBytes = struct.unpack('>i', encoder4.readCounter32())
    print('Encoder 4 Changed: %d' % valBytes[0])
    encoder4.writeLEDG(0)

def EncoderPush4():
    encoder4.writeLEDB(100)
    print('Encoder 4 Pushed!')
    encoder4.writeLEDB(0)

# Interrupt handler
def Encoder_INT(pin):
    print('Encoder_INT')
    for i, encoder in enumerate(encoders):
        status = encoder.readEncoder8(i2cEncoderLibV2.REG_ESTATUS)
        print(f'Encoder {i+1} Status 1: {status}')
        encoder.updateStatus()
        status = encoder.readEncoder8(i2cEncoderLibV2.REG_ESTATUS)
        print(f'Encoder {i+1} Status 2: {status}')
        print(" ")
        time.sleep(0.1)

# Initialize each encoder
def init_encoder(encoder, change_callback, push_callback):
    encoder.reset()
    print(f"Encoder reset")
    time.sleep(0.1)

    encconfig = (i2cEncoderLibV2.INT_DATA | i2cEncoderLibV2.WRAP_ENABLE
                 | i2cEncoderLibV2.DIRE_RIGHT | i2cEncoderLibV2.IPUP_ENABLE
                 | i2cEncoderLibV2.RMOD_X1 | i2cEncoderLibV2.RGB_ENCODER)
    encoder.begin(encconfig)
    print(f"Encoder begin with config: {encconfig}")

    reg = (i2cEncoderLibV2.PUSHP | i2cEncoderLibV2.RINC | i2cEncoderLibV2.RDEC)
    encoder.writeEncoder8(i2cEncoderLibV2.REG_INTCONF, reg)
    print(f"Encoder begin with intconfig: {reg}")

    encoder.writeCounter(0)
    encoder.writeMax(35)
    encoder.writeMin(-20)
    encoder.writeStep(1)
    encoder.writeAntibouncingPeriod(12)

    encoder.onChange = change_callback
    encoder.onButtonPush = push_callback

    print(f'Board ID code: 0x{encoder.readIDCode():X}')
    print(f'Board Version: 0x{encoder.readVersion():X}')

    encoder.writeRGBCode(0x640000)

# Initialize each encoder with their respective callback functions
init_encoder(encoder1, EncoderChange1, EncoderPush1)
init_encoder(encoder2, EncoderChange2, EncoderPush2)
init_encoder(encoder3, EncoderChange3, EncoderPush3)
init_encoder(encoder4, EncoderChange4, EncoderPush4)

# Add the encoders to the list for interrupt handling
encoders = [encoder1, encoder2, encoder3, encoder4]
# encoders = [encoder1]

# Setup the interrupt handler
INT_pin.irq(trigger=Pin.IRQ_FALLING, handler=Encoder_INT)
```

With the four i2cencoders, this is the output in which I rotated the first i2cencoder two detents:

```
MPY: soft reboot
Encoder reset
Encoder begin with config: 34
Encoder begin with intconfig: 26
Board ID code: 0x53
Board Version: 0x23
Encoder reset
Encoder begin with config: 34
Encoder begin with intconfig: 26
Board ID code: 0x53
Board Version: 0x23
Encoder reset
Encoder begin with config: 34
Encoder begin with intconfig: 26
Board ID code: 0x53
Board Version: 0x23
Encoder reset
Encoder begin with config: 34
Encoder begin with intconfig: 26
Board ID code: 0x53
Board Version: 0x23
>>> Encoder_INT
Encoder 1 Status 1: 8
Encoder 1 Status 2: 0

Encoder 2 Status 1: 0
Encoder 2 Status 2: 0

Encoder 3 Status 1: 0
Encoder 3 Status 2: 0

Encoder 4 Status 1: 0
Encoder 4 Status 2: 0

Encoder_INT
Encoder 1 Status 1: 8
Encoder 1 Status 2: 0

Encoder 2 Status 1: 0
Encoder 2 Status 2: 0

Encoder 3 Status 1: 0
Encoder 3 Status 2: 0

Encoder 4 Status 1: 0
Encoder 4 Status 2: 0

Encoder_INT
Encoder 1 Status 1: 0
Encoder 1 Status 2: 0

Encoder 2 Status 1: 0
Encoder 2 Status 2: 0

Encoder 3 Status 1: 0
Encoder 3 Status 2: 0

Encoder 4 Status 1: 0
Encoder 4 Status 2: 0

Encoder_INT
Encoder 1 Status 1: 0
Encoder 1 Status 2: 0

Encoder 2 Status 1: 0
Encoder 2 Status 2: 0

Encoder 3 Status 1: 0
Encoder 3 Status 2: 0

Encoder 4 Status 1: 0
Encoder 4 Status 2: 0

Encoder_INT
Encoder 1 Status 1: 0
Encoder 1 Status 2: 0

Encoder 2 Status 1: 0
Encoder 2 Status 2: 0

Encoder 3 Status 1: 0
Encoder 3 Status 2: 0

Encoder 4 Status 1: 0
Encoder 4 Status 2: 0
```
The Encoder_INT method fires continuously until I reset the microcontroller.

This is the output when testing with the stand-along i2cencoder:

```
MPY: soft reboot
Encoder reset
Encoder begin with config: 34
Encoder begin with intconfig: 26
Board ID code: 0x53
Board Version: 0x23
>>> Encoder_INT
Encoder 1 Status 1: 8
Encoder 1 Status 2: 0

Encoder_INT
Encoder 1 Status 1: 8
Encoder 1 Status 2: 0

Encoder_INT
Encoder 1 Status 1: 2
Encoder 1 Status 2: 0
```
This output stops after each interaction.

Would you have any idea as to what might be happening?

Thank you,
Cameron

cameronprince, 2025-01-24:
This solution is a bit of a hack, but I've discovered if I check the pin status in the interrupt callback, I can determine whether or not to call updateStatus() and keep from crashing the microcontroller:

def Encoder_INT(pin):
    if pin.value() == 0:
        print('Encoder_INT')

        # Read the status of the interrupt pin
        pin_status = INT_pin.value()
        print(f'Interrupt Pin Status: {pin_status}')

        for i, encoder in enumerate(encoders):
            status = encoder.readEncoder8(i2cEncoderLibV2.REG_ESTATUS)
            print(f'Encoder {i+1} Status 1: {status}')
            encoder.updateStatus()
            status = encoder.readEncoder8(i2cEncoderLibV2.REG_ESTATUS)
            print(f'Encoder {i+1} Status 2: {status}')
            print(" ")

Do you have any ideas as to why the interrupt callback is firing after the pin returns high, and why this would only happen with multiple i2cencoders?

cameronprince, 2025-01-24:
This still seems like a hack, but I've discovered that if I reinit the interrupt pin inside the Encoder_INT function, the continuous calls to the function cease. I'm now getting solid, consistent callback triggering, like with the stand-alone i2cencoder.

```
import time
import struct
from machine import Pin, I2C
import i2cEncoderLibV2

I2C_BUS = 1
I2C_SCL_PIN = 33
I2C_SDA_PIN = 32
INTERRUPT_PIN = 34
ENCODER_ADDRESSES = [0x50, 0x30, 0x60, 0x44]

# Initialize the interrupt pin.
INT_pin = Pin(INTERRUPT_PIN, Pin.IN, Pin.PULL_UP)

# Initialize the I2C bus.
i2c = I2C(I2C_BUS, scl=Pin(I2C_SCL_PIN), sda=Pin(I2C_SDA_PIN))
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
Fattoresaimon, 2025-01-24:
Hello,
I never used micropython and i'm not expert of python, so i can't help you on that side. I'm sorry.
But i remember a similar issue on the Arduino uno.
The Arduno uno can mange only 1 interrupt at time, so inside on the GPIO interrupt the I2C bus doesn't work. Because also the I2C use the interrupt.
In that case the program was blocking inside the GPIO interrupt and not I2C transition.

cameronprince, 2025-01-25:
Thanks for the reply... In testing this work around mentioned above, eventually, after some number of interactions with the i2cencoder, the interrupt stops firing. So it seems I have three options:

1. Remove the code which clears and re-adds the interrupt handler and just allow the function to be continuously called. The pin value check seems reliable to know when a true interrupt is received.
2. Switch to polling with asyncio.
3. Separate the i2cencoders and dedicate individual GPIO pins for each interrupt.

I'll let you know how it goes.

Cameron

cameronprince, 2025-02-01:
@Fattoresaimon,

A follow-up here... I've been pretty successful using four I2CEncoders with my project. I did settle with a separate GPIO pin for each encoder's interrupt. I was never able to figure out why the interrupt callback kept firing when trying to poll the encoders to see which fired when sharing interrupt pins.

What I'm seeing now that maybe I should create a new issue about is that during operation, several times, I've seen an encoder become unresponsive. Sometimes, the other encoders continue to work. Other times, the whole program crashes. I attribute this to I2C bus overruns. I'm currently running with encoder.writeAntibouncingPeriod(40) for each encoder. Is this the only deterrent to slow down I2C comms?

In my project, during MIDI playback, which is in it's own thread, I have four encoders controlling four output levels in the main thread. The code is set up so that the encoders scale the duty cycle of each output and the RGB LED in each encoder shows a color indicative of the output level (green, to yellow, to red). I also have an elapsed time display running. While the MIDI file is playing and adjusting the encoders, sometimes I see this problem. In these cases, the encoder adjustment is triggering back-to-back calls to readEncoder8() and writeRGBCode(), one triggering the other.

Is the solution here to queue the comms? I would certainly rather have a slight delay in the RGB color changing than the program be interrupted.

Thank you,
Cameron

cameronprince, 2025-03-12:
I was able to resolve this. The key was to not try and do the polling to see which i2cencoder triggered the interrupt in the interrupt callback itself. The interrupt callback must be lean and fast.

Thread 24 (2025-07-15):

False GP1 trigger upon initialization

cameronprince, 2025-07-15:
Hello,

I've started using the GP switch inputs on one I2CEncoder in my project and have noticed a false GP1_IN trigger happening consistently upon power up. I've worked around the problem as follows:

`                        if i2status & GP1_IN:
                            # Ignore input for the first 10 seconds after start.
                            if time.ticks_diff(time.ticks_ms(), self.init.start_time) < 10000:
                                break
`

Is there a way to prevent this false trigger?

Thanks,
Cameron

Fattoresaimon, 2025-07-15:
Hello,
Uh that looks interesting.

Can you explain a little bit what is your configuration?

After the power up, you configure the encoder, and as soon as you configure the GP pin you receive the interrupt?

Are you sure regarding the polarity of the trigger?

Thank you,
Simone

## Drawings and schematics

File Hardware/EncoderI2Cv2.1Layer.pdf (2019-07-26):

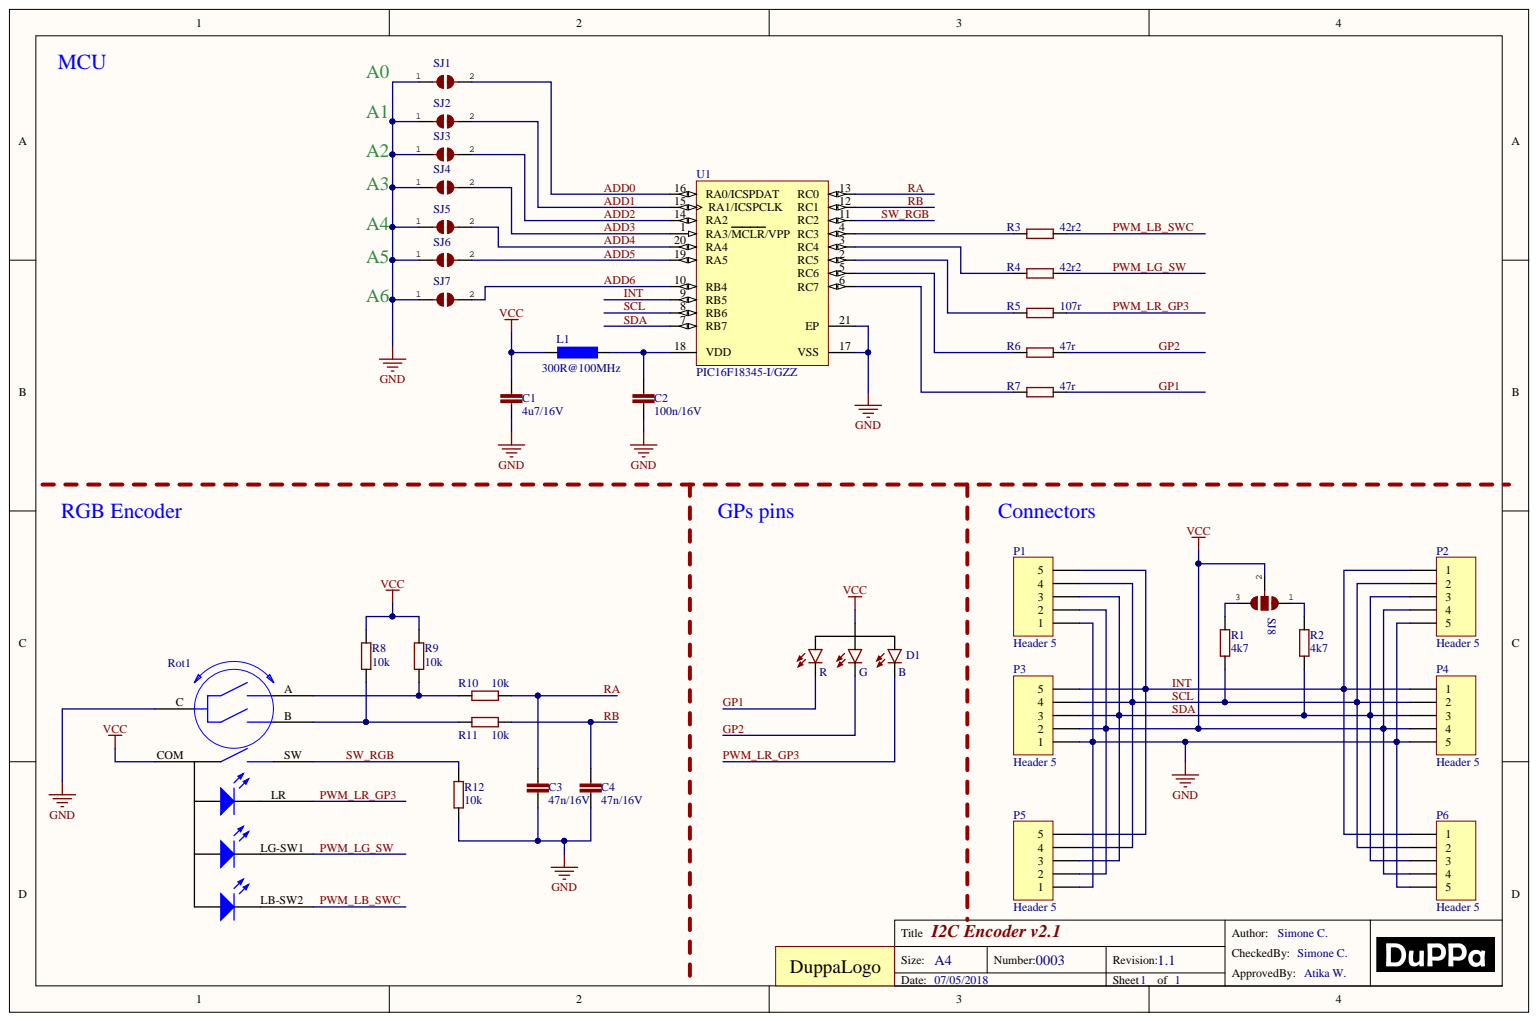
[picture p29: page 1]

ADD1 | | RA2 14 RA0/ICSPDAT 16 RA1/ICSPCLK 15

ADD2

SCL
SDA

I2C Encoder v2.1 Title | Author: Simone C. CheckedBy: Simone C. ApprovedBy: Atika W .

DuppaLog o | Size: A4 | Number: 0003 | Revision: 1.1

Date: 07/05/2018 | | Sheet 1 of 1

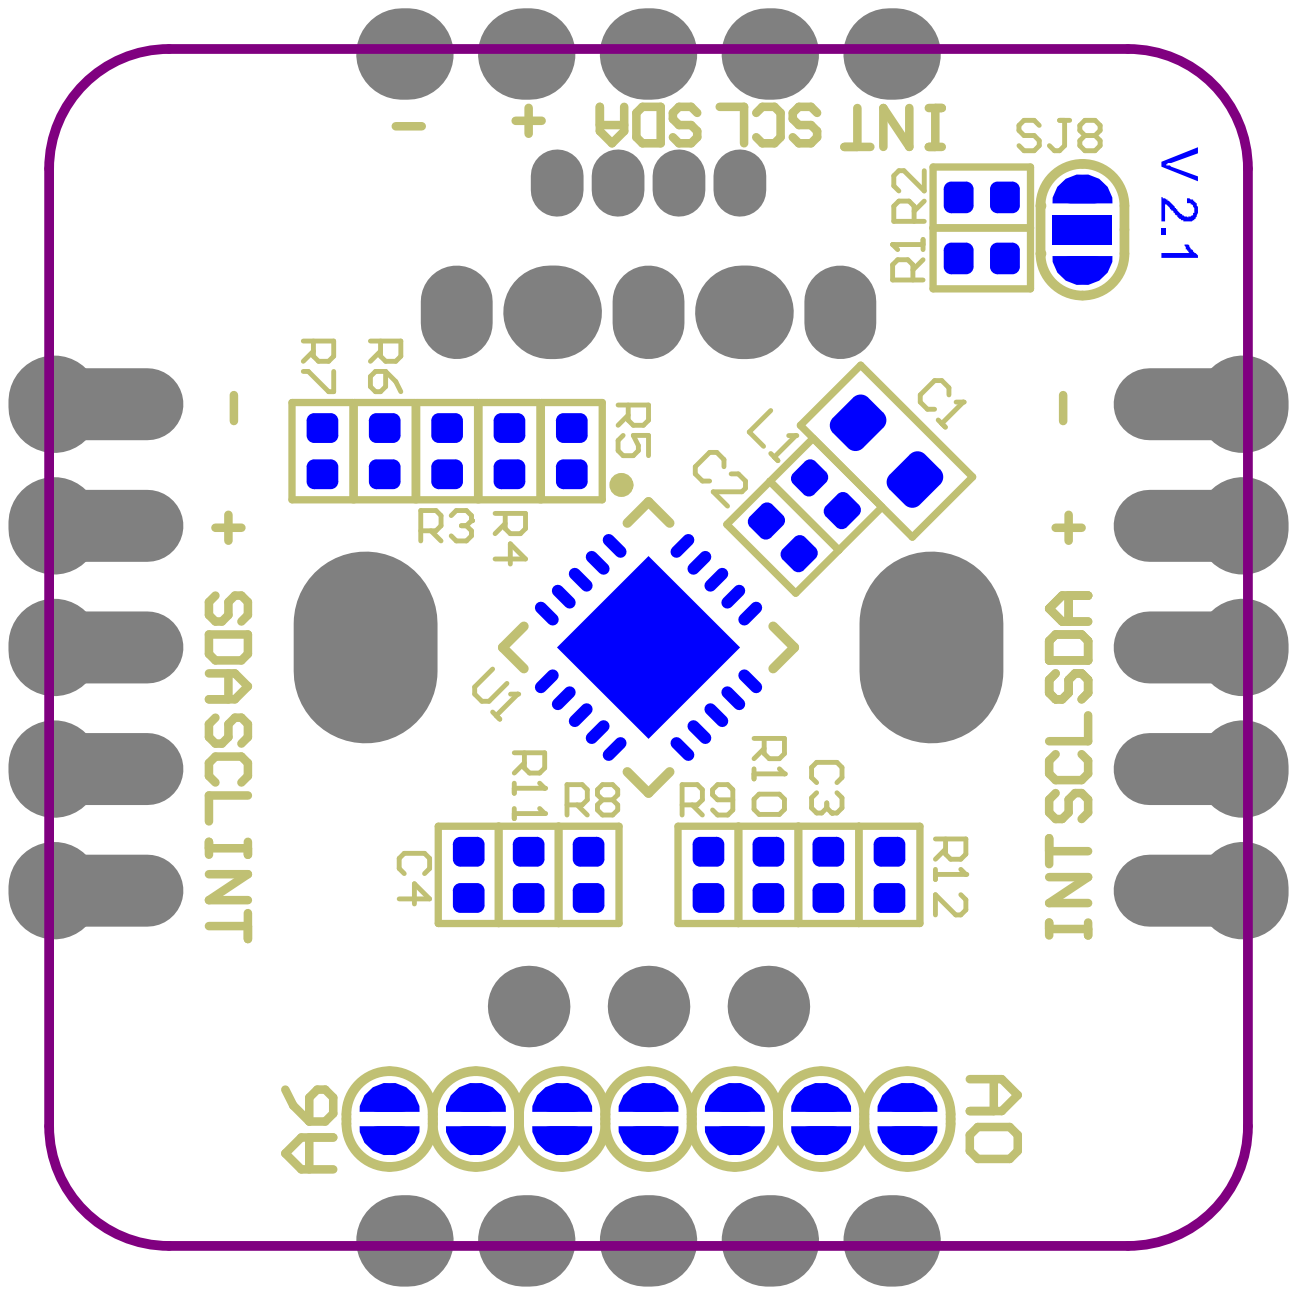
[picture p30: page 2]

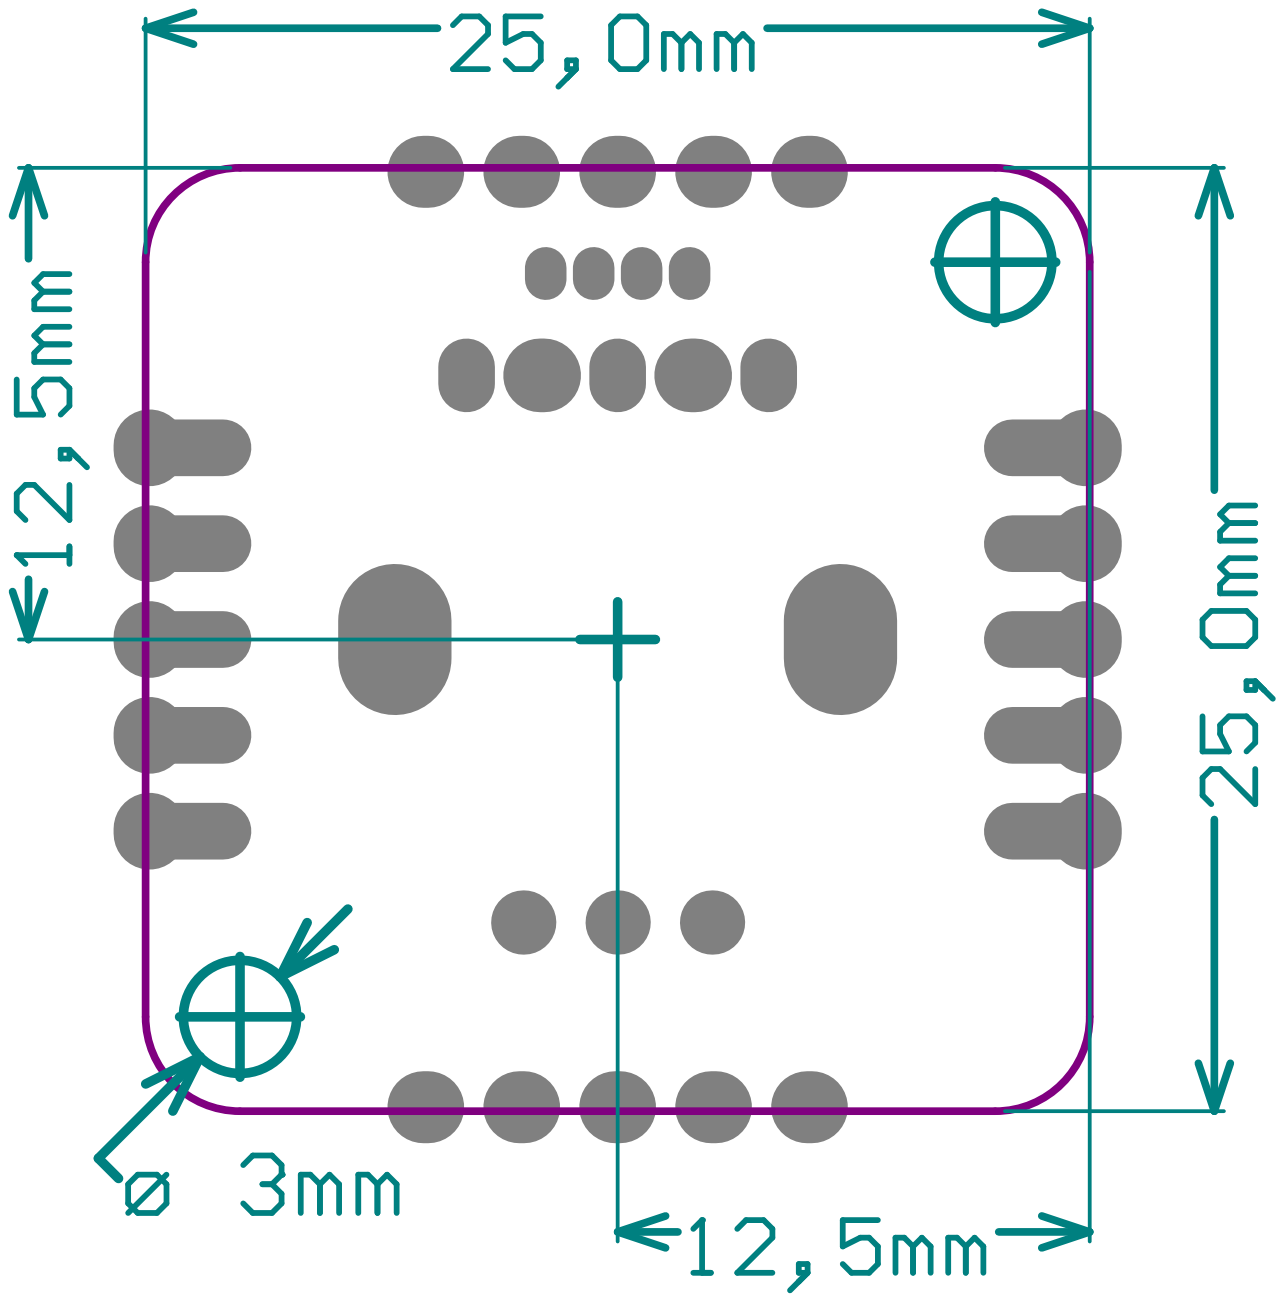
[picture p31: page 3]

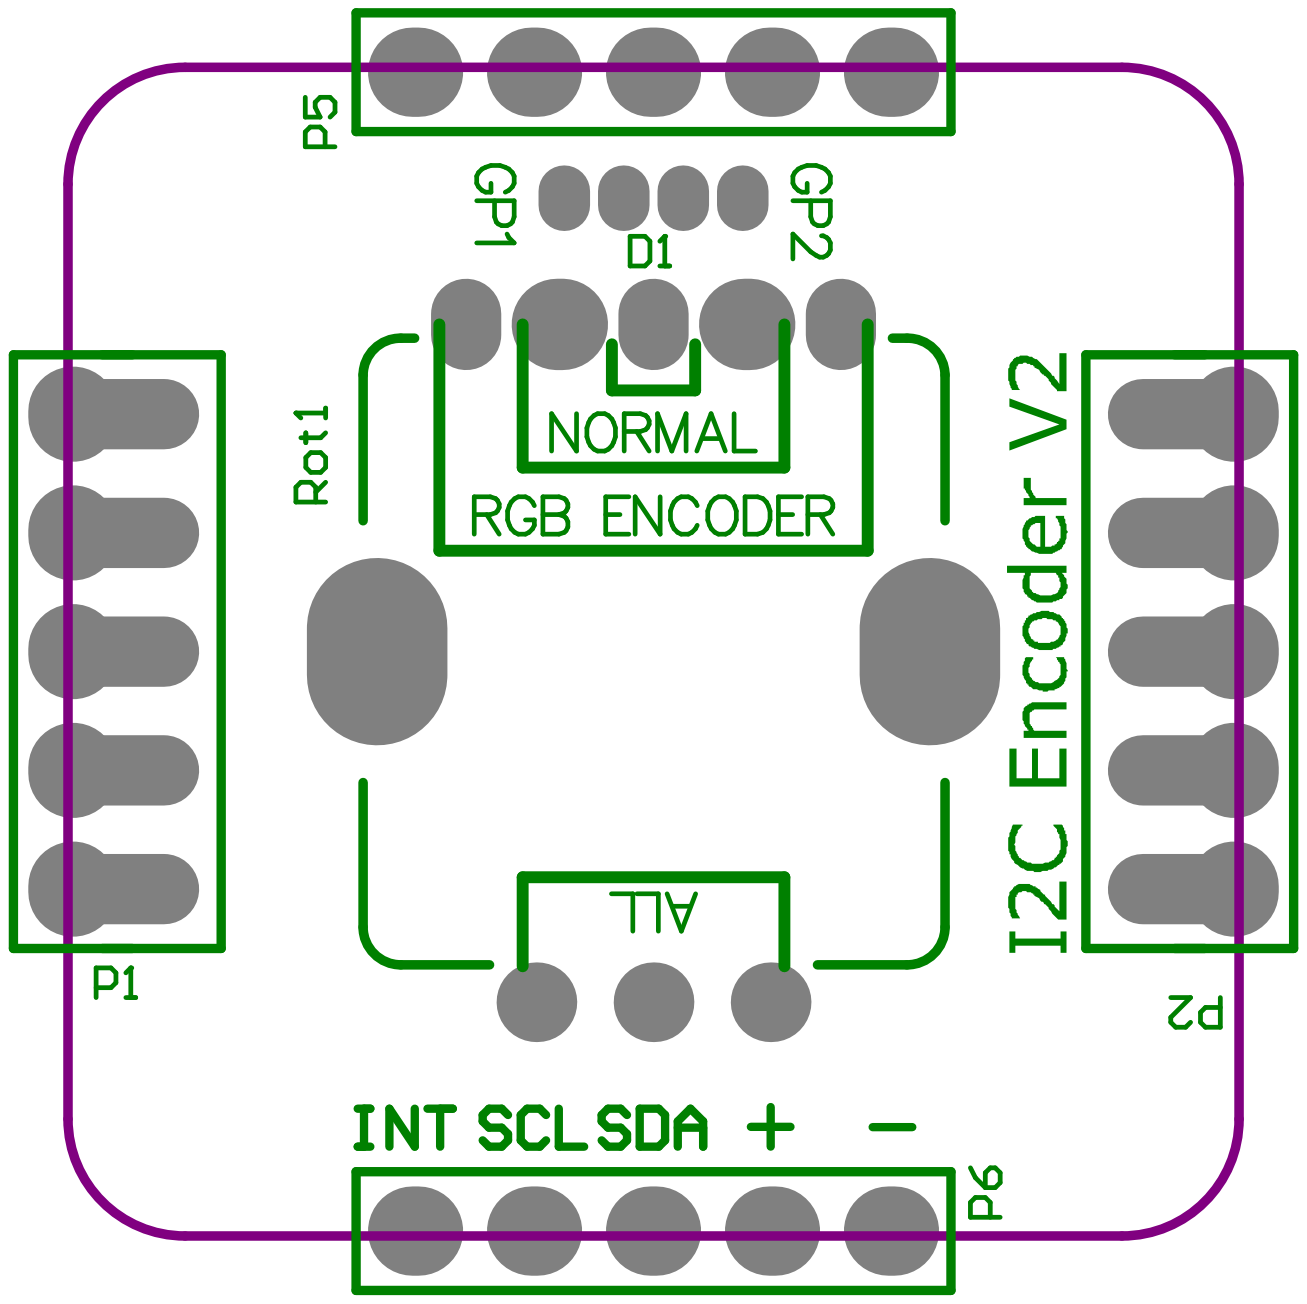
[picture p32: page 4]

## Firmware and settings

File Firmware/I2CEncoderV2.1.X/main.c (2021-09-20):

/**
  Generated Main Source File

  Company:
    Microchip Technology Inc.

  File Name:
    main.c

  Summary:
    This is the main file generated using PIC10 / PIC12 / PIC16 / PIC18 MCUs

  Description:
    This header file provides implementations for driver APIs for all modules selected in the GUI.
    Generation Information :
        Product Revision  :  PIC10 / PIC12 / PIC16 / PIC18 MCUs - 1.65.2
        Device            :  PIC16F18344
        Driver Version    :  2.00
 */

/*
    (c) 2018 Microchip Technology Inc. and its subsidiaries. 
    
    Subject to your compliance with these terms, you may use Microchip software and any 
    derivatives exclusively with Microchip products. It is your responsibility to comply with third party 
    license terms applicable to your use of third party software (including open source software) that 
    may accompany Microchip software.
    
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
    IN NO EVENT WILL MICROCHIP BE LIABLE FOR ANY INDIRECT, SPECIAL, PUNITIVE, 
    INCIDENTAL OR CONSEQUENTIAL LOSS, DAMAGE, COST OR EXPENSE OF ANY KIND 
    WHATSOEVER RELATED TO THE SOFTWARE, HOWEVER CAUSED, EVEN IF MICROCHIP 
    HAS BEEN ADVISED OF THE POSSIBILITY OR THE DAMAGES ARE FORESEEABLE. TO 
    THE FULLEST EXTENT ALLOWED BY LAW, MICROCHIP'S TOTAL LIABILITY ON ALL 
    CLAIMS IN ANY WAY RELATED TO THIS SOFTWARE WILL NOT EXCEED THE AMOUNT 
    OF FEES, IF ANY, THAT YOU HAVE PAID DIRECTLY TO MICROCHIP FOR THIS 
    SOFTWARE.
 */

#include "mcc_generated_files/mcc.h"
#include "i2c_register.h"
#include "main.h"
#include "GPports.h"
#include "DataVariable.h"
#include "Encoder.h"

bool fsm_tmr = false;

/**
 * @brief Function for set the output interrupt pin
 */
void SetInterrupt(void) {

    if ((ESTATUS & INTCONF) != 0) {
        INT_SetLow();
    }
}

/**
 * @brief Function for clear the output interrupt pin
 */
void ClearInterrupt(void) {
    INT_SetHigh();
}

/**
 * @brief Function for clear the output interrupt pin
 */
void TimerInt(void) {
    fsm_tmr = true;
}

/*
                         Main application
 */
void main(void) {
    // initialize the device
    SYSTEM_Initialize();

    // When using interrupts, you need to set the Global and Peripheral Interrupt Enable bits
    // Use the following macros to:

    // Enable the Global Interrupts
    INTERRUPT_GlobalInterruptEnable();

    // Enable the Peripheral Interrupts
    INTERRUPT_PeripheralInterruptEnable();

    // Disable the Global Interrupts
    //INTERRUPT_GlobalInterruptDisable();

    // Disable the Peripheral Interrupts
    //INTERRUPT_PeripheralInterruptDisable();

    DataInitSet();
    PWM_LB_SWC_SetDigitalInput();
    PWM_LG_SW_SetDigitalInput();
    PWM_LR_GP3_SetDigitalInput();
    GP2_SetDigitalInput();
    GP1_SetDigitalInput();

    TMR3_StartTimer();
    TMR0_StartTimer();
    ClearInterrupt();

    CPUDOZEbits.IDLEN = 1;
    CPUDOZEbits.ROI = 1;
    
    while (1) {

        if (fsm_tmr == true) {

            Encoder_FSM();
            GP_Ports_FSM();
            fsm_tmr = false;

            SLEEP();

        }
    }
}
/**
 End of File
 */

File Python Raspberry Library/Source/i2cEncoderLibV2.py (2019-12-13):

import smbus
import time
import struct
from time import sleep

# Encoder register definition#
REG_GCONF = 0x00
REG_GP1CONF = 0x01
REG_GP2CONF = 0x02
REG_GP3CONF = 0x03
REG_INTCONF = 0x04
REG_ESTATUS = 0x05
REG_I2STATUS = 0x06
REG_FSTATUS = 0x07
REG_CVALB4 = 0x08
REG_CVALB3 = 0x09
REG_CVALB2 = 0x0A
REG_CVALB1 = 0x0B
REG_CMAXB4 = 0x0C
REG_CMAXB3 = 0x0D
REG_CMAXB2 = 0x0E
REG_CMAXB1 = 0x0F
REG_CMINB4 = 0x10
REG_CMINB3 = 0x11
REG_CMINB2 = 0x12
REG_CMINB1 = 0x13
REG_ISTEPB4 = 0x14
REG_ISTEPB3 = 0x15
REG_ISTEPB2 = 0x16
REG_ISTEPB1 = 0x17
REG_RLED = 0x18
REG_GLED = 0x19
REG_BLED = 0x1A
REG_GP1REG = 0x1B
REG_GP2REG = 0x1C
REG_GP3REG = 0x1D
REG_ANTBOUNC = 0x1E
REG_DPPERIOD = 0x1F
REG_FADERGB = 0x20
REG_FADEGP = 0x21
REG_GAMRLED = 0x27
REG_GAMGLED = 0x28
REG_GAMBLED = 0x29
REG_GAMMAGP1 = 0x2A
REG_GAMMAGP2 = 0x2B
REG_GAMMAGP3 = 0x2C
REG_GCONF2 = 0x30
REG_IDCODE = 0x70
REG_VERSION = 0x71
REG_EEPROMS = 0x80

# Encoder configuration bit. Use with GCONF #
FLOAT_DATA = 0x0001
INT_DATA = 0x0000
WRAP_ENABLE = 0x0002
WRAP_DISABLE = 0x0000
DIRE_LEFT = 0x0004
DIRE_RIGHT = 0x0000
IPUP_DISABLE = 0x0008
IPUP_ENABLE = 0x0000
RMOD_X2 = 0x0010
RMOD_X1 = 0x0000
RGB_ENCODER = 0x0020
STD_ENCODER = 0x0000
EEPROM_BANK1 = 0x0040
EEPROM_BANK2 = 0x0000
RESET = 0x0080
CLK_STRECH_ENABLE = 0x0100
CLK_STRECH_DISABLE = 0x0000
REL_MODE_ENABLE = 0x0200
REL_MODE_DISABLE = 0x0000

# Encoder status bits and setting. Use with: INTCONF for set and with ESTATUS for read the bits  #
PUSHR = 0x01
PUSHP = 0x02
PUSHD = 0x04
RINC = 0x08
RDEC = 0x10
RMAX = 0x20
RMIN = 0x40
INT_2 = 0x80

# Encoder Int2 bits. Use to read the bits of I2STATUS  #
GP1_POS = 0x01
GP1_NEG = 0x02
GP2_POS = 0x04
GP2_NEG = 0x08
GP3_POS = 0x10
GP3_NEG = 0x20
FADE_INT = 0x40

# Encoder Fade status bits. Use to read the bits of FSTATUS  #
FADE_R = 0x01
FADE_G = 0x02
FADE_B = 0x04
FADE_GP1 = 0x08
FADE_GP2 = 0x10
FADE_GP3 = 0x20

# GPIO Configuration. USe with GP1CONF,GP2CONF,GP3CONF #
GP_PWM = 0x00
GP_OUT = 0x01
GP_AN = 0x02
GP_IN = 0x03

GP_PULL_EN = 0x04
GP_PULL_DI = 0x00

GP_INT_DI = 0x00
GP_INT_PE = 0x08
GP_INT_NE = 0x10
GP_INT_BE = 0x18

# Gamma configuration #

GAMMA_OFF = 0
GAMMA_1 = 1,
GAMMA_1_8 = 2
GAMMA_2 = 3
GAMMA_2_2 = 4
GAMMA_2_4 = 5
GAMMA_2_6 = 6
GAMMA_2_8 = 7


class i2cEncoderLibV2:

    onButtonRelease = None
    onButtonPush = None
    onButtonDoublePush = None
    onIncrement = None
    onDecrement = None
    onChange = None
    onMax = None
    onMin = None
    onMinMax = None
    onGP1Rise = None
    onGP1Fall = None
    onGP2Rise = None
    onGP2Fall = None
    onGP3Rise = None
    onGP3Fall = None
    onFadeProcess = None

    stat = 0
    stat2 = 0
    gconf = 0

# Class costructor

    def __init__(self, bus, add):
        self.i2cbus = bus
        self.i2cadd = add

# Used for initialize the encoder
    def begin(self, conf):
        self.writeEncoder8(REG_GCONF, conf & 0xFF)
        self.writeEncoder8(REG_GCONF2, ((conf >> 8) & 0xFF))
        self.gconf = conf

    def reset(self) :
        self.writeEncoder8(REG_GCONF, 0x80)

# Call che attached callaback if it is defined #
    def eventCaller(self, event) :
        if event:
            event()

# Return true if the status of the encoder changed, otherwise return false #
    def updateStatus(self) :
        self.stat = self.readEncoder8(REG_ESTATUS)
        
        if (self.stat == 0):
            self.stat2 = 0
            return False
        
        if (self.stat & PUSHR) != 0 :
            self.eventCaller (self.onButtonRelease)

        if (self.stat & PUSHP) != 0 :
            self.eventCaller (self.onButtonPush)

        if (self.stat & PUSHD) != 0 :
            self.eventCaller (self.onButtonDoublePush)

        if (self.stat & RINC) != 0 :
            self.eventCaller (self.onIncrement)
            self.eventCaller (self.onChange)

        if (self.stat & RDEC) != 0 :
            self.eventCaller (self.onDecrement)
            self.eventCaller (self.onChange)

        if (self.stat & RMAX) != 0 :
            self.eventCaller (self.onMax)
            self.eventCaller (self.onMinMax)

        if (self.stat & RMIN) != 0 :
            self.eventCaller (self.onMin)
            self.eventCaller (self.onMinMax)

        if (self.stat & INT_2) != 0 :
            self.stat2 = self.readEncoder8(REG_I2STATUS)
            if (self.stat2 == 0) :
                return True

            if (self.stat2 & GP1_POS) != 0 :
                self.eventCaller (self.onGP1Rise)

            if (self.stat2 & GP1_NEG) != 0 :
                self.eventCaller (self.onGP1Fall)

            if (self.stat2 & GP2_POS) != 0 :
                self.eventCaller (self.onGP2Rise)

            if (self.stat2 & GP2_NEG) != 0 :
                self.eventCaller (self.onGP2Fall)

            if (self.stat2 & GP3_POS) != 0 :
                self.eventCaller (self.onGP3Rise)

            if (self.stat2 & GP3_NEG) != 0 :
                self.eventCaller (self.onGP3Fall)

            if (self.stat2 & FADE_INT) != 0 :
                self.eventCaller (self.onFadeProcess)
        return True

#********************************* Read functions ***********************************#

# Return the GP1 Configuration#
    def readGP1conf(self) :
        return (self.readEncoder8(REG_GP1CONF))

# Return the GP1 Configuration#
    def readGP2conf(self) :
        return (self.readEncoder8(REG_GP2CONF))

# Return the GP1 Configuration#
    def readGP3conf(self) :
        return (self.readEncoder8(REG_GP3CONF))

# Return the INT pin configuration#
    def readInterruptConfig(self) :
        return (self.readEncoder8(REG_INTCONF))

# Check if a particular status match, return true is match otherwise false. Before require updateStatus() #
    def readStatus(self, status) :
        if (self.stat & status) != 0 :
            return True
        else:
            return False

# Return the status of the encoder #
    def readStatusRaw(self) :
        return self.stat

# Check if a particular status of the Int2 match, return true is match otherwise false. Before require updateStatus() #
    def readInt2(self, status) :
        if (self.stat2 & status) != 0 :
            return True
        else:
            return False

# Return the Int2 status of the encoder. Before require updateStatus()  #
    def readInt2Raw(self):
        return self.stat2

# Return Fade process status  #
    def readFadeStatusRaw(self):
        return self.readEncoder8(REG_FSTATUS)

# Check if a particular status of the Fade process match, return true is match otherwise false. #
    def readFadeStatus(self, status):
        if (self.readEncoder8(REG_FSTATUS) & status) == 1 :
            return True
        else:
            return False

# Return the PWM LED R value  #
    def readLEDR(self) :
        return (self.readEncoder8(REG_RLED))

# Return the PWM LED G value  #
    def readLEDG(self) :
        return (self.readEncoder8(REG_GLED))

# Return the PWM LED B value  #
    def readLEDB(self) :
        return (self.readEncoder8(REG_BLED))
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

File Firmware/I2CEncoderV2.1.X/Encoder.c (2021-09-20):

#include "i2c_register.h"
#include "mcc_generated_files/mcc.h"
#include "mcc_generated_files/adc.h"
#include "main.h"
#include "GPports.h"
#include "DataVariable.h"
#include "Encoder.h"
#include "PWM.h"


uint8_t pb_fsm = ENCODER_WAITPUSH;
int8_t pb_cnt = 0;
uint16_t double_push_cnt = 0;
uint16_t double_push_delay = 0;
uint8_t fade_cnt = 0;
uint8_t temp_red = 0;
uint8_t temp_green = 0;
uint8_t temp_blu = 0;


volatile uint8_t X1_p; // X1/X2 mode increment
volatile uint8_t X1_n; // X1/X2 mode decrement
volatile uint8_t X2_n; // X2 mode decrement
volatile uint8_t X2_p; // X2 mode increment



volatile uint8_t enc_status;

/**
 * @brief function return the status of the encoder switch
 * @return true if pressed, false if released
 */
bool EncoderSwitch_GetValue(void) {
    if (C_ETYPE == RGB_ENCODER) {
        return (SW_RGB_GetValue());
    } else {
        return ((bool)!PWM_LG_SW_GetValue());
    }

}

/**
 * @brief function that make a anti-bouncing of the switch, must be called every 1ms
 * @return true if pressed, false if released
 */
bool EncoderSwitch_GetValueFiltered(void) {
    static bool pb_status = false;

    if (EncoderSwitch_GetValue() == true) {
        if (pb_cnt++ >= PB_DEBOUNCE) {
            pb_cnt = PB_DEBOUNCE;
            pb_status = true;
        }
    } else {
        if (pb_cnt-- <= 0) {
            pb_cnt = 0;
            pb_status = false;
        }
    }

    return pb_status;
}

void Encoder_AB_Interrupt(void) {

    enc_status = (enc_status << 2);
    enc_status = enc_status | ((uint8_t) PORTC & 0x03);
    enc_status = enc_status & 0x0f;

    if ((enc_status == X1_p) || (enc_status == X2_p)) {

        if (C_DTYPE == INT_DATA_TYPE) {
            CVAL.val = CVAL.val + ISTEP.val;
            EncoderStatusUpdate(S_RINC);
            if (CVAL.val > CMAX.val) {
                EncoderStatusUpdate(S_RMAX);
                if (C_WRAPE == true) {
                    CVAL.val = CMIN.val;
                } else {
                    CVAL.val = CMAX.val;
                }
            }
        } else {
            CVAL.fval = CVAL.fval + ISTEP.fval;
            EncoderStatusUpdate(S_RINC);
            if (CVAL.fval > CMAX.fval) {
                EncoderStatusUpdate(S_RMAX);
                if (C_WRAPE == true) {
                    CVAL.fval = CMIN.fval;
                } else {
                    CVAL.fval = CMAX.fval;
                }
            }
        }
    } else {

        if ((enc_status == X1_n) || (enc_status == X2_n) ) {

            if (C_DTYPE == INT_DATA_TYPE) {

                CVAL.val = CVAL.val - ISTEP.val;
                EncoderStatusUpdate(S_RDEC);
                if (CVAL.val < CMIN.val) {
                    EncoderStatusUpdate(S_RMIN);
                    if (C_WRAPE == true) {
                        CVAL.val = CMAX.val;
                    } else {
                        CVAL.val = CMIN.val;
                    }
                }
            } else {
                CVAL.fval = CVAL.fval - ISTEP.fval;
                EncoderStatusUpdate(S_RDEC);
                if (CVAL.fval < CMIN.fval) {
                    EncoderStatusUpdate(S_RMIN);
                    if (C_WRAPE == true) {
                        CVAL.fval = CMAX.fval;
                    } else {

                        CVAL.fval = CMIN.fval;
                    }
                }
            }
        }
    }

    SetInterrupt();
}

/*
 * @brief Fade manager of the RGB Encoder. It's called every 1ms in the main loop
 */

void FADE_LEDS(void) {

    if (C_ETYPE == STD_ENCODER)
        return;

    if (FADERGB == 0) {
        if (temp_red != RLED) {
            temp_red = RLED;
            PWM_GP3_RLED(temp_red);
        }

        if (temp_green != GLED) {
            temp_green = GLED;
            PWM_GLED(temp_green);
        }

        if (temp_blu != BLED) {
            temp_blu = BLED;
            PWM_BLED(temp_blu);
        }
        return;
    }
    fade_cnt++;
    if (fade_cnt >= FADERGB) {
        fade_cnt = 0;

        if (temp_red != RLED) {

            if (temp_red < RLED) {
                temp_red++;
            }
            if (temp_red > RLED) {
                temp_red--;
            }

            PWM_GP3_RLED(temp_red);
            if (temp_red == RLED) {
                FadeProcessClear(F_FER);
            } else {
                FadeProcessSet(F_FER);
            }
        }

        if (temp_green != GLED) {

            if (temp_green < GLED) {
                temp_green++;
            }
            if (temp_green > GLED) {
                temp_green--;
            }

            PWM_GLED(temp_green);
            if (temp_green == GLED) {
                FadeProcessClear(F_FEG);
            } else {
                FadeProcessSet(F_FEG);

            }
        }


        if (temp_blu != BLED) {

            if (temp_blu < BLED) {
                temp_blu++;
            }
            if (temp_blu > BLED) {
                temp_blu--;
            }

            PWM_BLED(temp_blu);
            if (temp_blu == BLED) {
                FadeProcessClear(F_FEB);
            } else {

                FadeProcessSet(F_FEB);
            }
        }
    }
}

/*
 @brief managinf the encoder push button
 */
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

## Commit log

2018-07-04 Create Arduino Library
2018-07-04 Added Arduino Library
2018-08-12 Added HW files
    [Bill of Materials-EncoderI2Cv2.xls, EncoderI2Cv2.step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]
2018-10-04 Simple example with one board
2018-10-04 Example with 9 boards
2018-10-17 Changed standard encoder definition
    Changed:
    #define STANDARD_ENCODER 0x00
    to
    #define STD_ENCODER 0x00
2018-10-20 Wrong standard encoder definition
2018-11-02 Update Raspberry Library/README.md
2018-12-23 Added more examples with ESP boards
2019-03-02 Moved Arduino library
    Arduino library removed and moved on another repository
    https://github.com/Fattoresaimon/ArduinoDuPPaLib
2019-05-22 Update i2cEncoderLibV2.py
    The "return False" needs indenting for this updateStatus to work properly, otherwise it always returns False.
2019-07-26 Repository update to the HW version V2.1
    [Bill of Materials-EncoderI2Cv2.1.xls, Bill of Materials-EncoderI2Cv2.xls, EncoderI2Cv2.step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]
2019-09-04 fixed the error in python 3
    [i2cEncoderLibV2.py]
2019-12-13 Added Raspberry Python library
2020-06-12 added DXF and updated gerber
    [EncoderI2Cv21.step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]
2020-09-23 Fixed the PCB thickness
    [EncoderI2Cv21.step, EncoderI2Cv21_4Layer.step]
2021-09-20 Updated to the FW 2.3 release
    Changed the encoder movement detection and also the ANTBOUNCE register
2024-10-18 Update version
    [EncoderI2Cv21_4Layer.step]
2024-10-18 added encoder
    [EC11_15mm_Dshape.stp, EC11_15mm_Knurled.stp, EC11_20mm_Dshape.stp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]
